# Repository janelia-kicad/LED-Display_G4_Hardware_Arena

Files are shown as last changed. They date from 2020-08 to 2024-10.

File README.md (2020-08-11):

---
title: Arena PCB
parent: Hardware
grand_parent: Generation 4
---

# Arena PCB 

An arena consists of a *Bottom PCB*, a *Top PCB*, and an *Interconnect PCB*.

The *Bottom PCB* is the basis on which the panels are mounted and where the power and input signal are connected. The *Top PCB* terminates the signal lines for each of the panel columns. The *Interconnect PCB* is an adapter from the NI connector to a ribbon connector required on the *Bottom PCB*. An arena can support up to 12 columns with up to 4 panels in each column. There are different forms of the panel, a full cylinder and a 12-18 cylinder.

## Arena 12-18

The Arena 12-18 allows to build panels around the fly in a 2/3 cylinder with a diameter of 250mm. The name originates from a the full cylinder virtually consisting of 18 columns of which 12 are actually part of the PCB. The current design interation developed in 2019 uses 7 layers.

## Interconnect PCB

The interconnect is a 2 layer PCB. It servers as an adapter between a VHDCI receptacle and a 40-pin header which is connected to the Arena via a ribbon cable. Recent tests have shown, that these ribbon cables introduce noise and should be kept as short as possible.

# Files

```
├── Production              - Gerber, drill, BOM
│   ├── 2017_Arena_12-18    - Arena board (old)
│   ├── 2019_Arena_12-18    - Arena board (current)
│   └── Interconnect        - Interconnect board
├── Schematic
│   └── Arena_bottom.pdf    - generated 2017-06-09
└── README.md
```

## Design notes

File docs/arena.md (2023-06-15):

---
title: Arena
parent: Acquisition
grand_parent: Generation 4
nav_order: 7
---

1. TOC
{:toc}

# Arena Board

The arena board organizes panels in a geometry and provides structural integrity to the whole setup. Different shapes of cylindrical arenas have been built. They are often described by their number of panel columns populated and the virtual ones forming a full circle. An _arena 12-12_ is a closed cylinder formed by 12 columns in total. All columns can be populated in this design, but typically between 1 and 3 are left empty to access the center of the arena.

Most functional designs will have two separate bill of material (BOM). One of the BOM should refer to _BOTTOM_, another to _TOP_. For a single setup, you will need two arena bards of the same type, one acting as the bottom board, one as the top board.

The BOM for the bottom arena board will usually contain more components. The bottom arena board is where the interconnect board and power are connected to and where the signals from the computer are distributed to the different columns. The top arena board gives structural integrity to the whole setup, it terminates signals, and sometimes provides additional power connectors.

## arena 12-12 board {#a12-12}

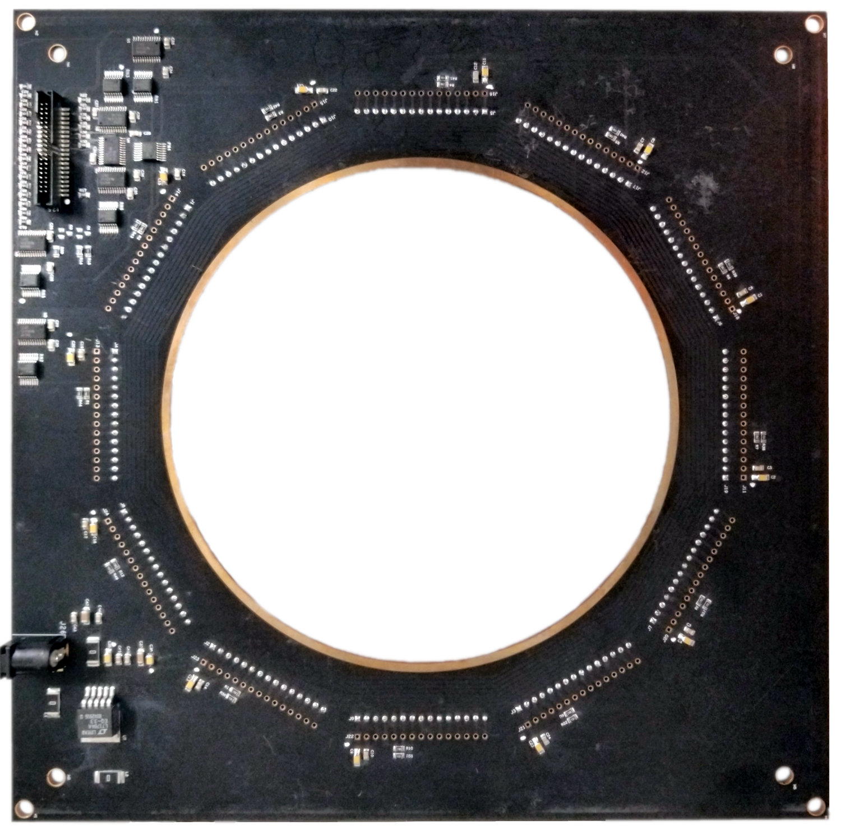
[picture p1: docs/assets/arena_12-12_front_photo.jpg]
Arena 12-12 board v1


A 12-12 Arena places twelve columns of panels in a regular dodecagon, forming an approximate cylindrical display with 170mm diameter. These are type of arenas are useful for behavioral experiments.

Currently, the most recent version 2 is the most widely used version. Nevertheless, version 4 has some improvements and is designed to minimize noise. This should work, but is not yet widely adapted. All other versions are either deprecated or prototypes.

The __Arena 12-12 Version 1__ (OrCAD design file at `arena_12-12/arena_12-12_v1.brd`, see [schematics](assets/arena_12-12_v1_schematic.pdf)) was developed in June 2017 as a 6 layer board. In addition to the connectors approximating an inner circle with 170mm diameter, it had a second row of connectors about 180mm apart. Another visible distinction are eight vias inside the connector ring, which are used for the chip selects. The image on the right shows such an arena board with the ribbon connector on the top left and the power connector on the bottom left.

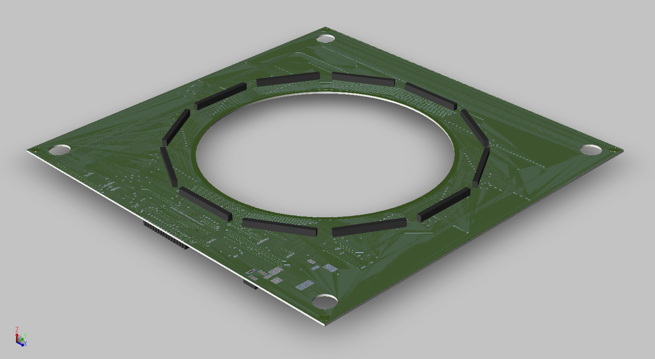
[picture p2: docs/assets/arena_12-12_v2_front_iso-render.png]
Rendering of an Arena 12-12 Version 2


The __Arena 12-12 Version 2__ (OrCAD design file at `arena_12-12/arena_12-12_v2.brd`) is similar to version 1 in [schematics](assets/arena_12-12_v1_schematic.pdf) and most of the pcb layout, but is missing the outer ring of potential connectors. Development on the 6 layer version 2 started in February 2018. If you want to repair a version 1 or version 2 board, we recommend the production files for __Arena 12-12 v2.4__ archived at `arena_12-12/production_v2/arena_12-12_v2p4.zip` as it includes incremental improvements like a more helpful silkscreen. While most of the arenas were hand-assembled and with parts that our machine shop had lying around. Version v2.4 is an attempt to fill in some of the gaps and is a step towards being able to give the assembly job to an external contractor. [Contact us]({{site.baseurl}}/Contact) about the progress if you have questions.

__Arena 12-12 Version 2C__ (OrCAD design file at `arena_12-12/arena_12-12_v2C`) is a prototype to length match all signal lines and decrease electric noise by routing them on individual layers. As a result the board has 12 (hex: `0xC`, hence 2C) layers. In our hands it didn't show improvements over other version 2 boards, but if you are looking to debug timing issues this could be a helpful starting point.

__Arena 12-12 Version 3__ (OrCAD design file at `arena_12-12/arena_12-12_v3.brd`, see [schematics](assets/arena_12-12_v3_schematic.pdf)) is a 6 layer prototype with two rings of connectors and additional changes to the physical shape of the PCB. It never left prototyping stage and is here only for historical purposes. This version was designed in June 2019.

__Arena 12-12 Version 4__ (OrCAD design file at `arena_12-12/arena_12-12_v4.brd`, see [schematics](assets/arena_12-12_v4_schematic.pdf)) is the attempt to minimize noise in the system further. To achieve that, the electronic design of this 6 layer PCB was changed in August 2019 so that the clock signal is now actively driven by a fanout instead of a simpler voltage translator as in previous versions. Furthermore, the chip select lines are isolated from each other through active components. The circular PCB was physically interrupted to avoid timing issues through circular traces.

The __Arena 12-12 Version 5__ (OrCAD design file at `arena_12-12/arena_12-12_v5.brd`, see [schematics](assets/arena_12-12_v5_schematic.pdf)) is an experimental 6 layer design without a [interconnect board](#interconnect) but instead with a direct VHDCI connector. Development is ongoing since Summer 2020, but the design does not work yet.

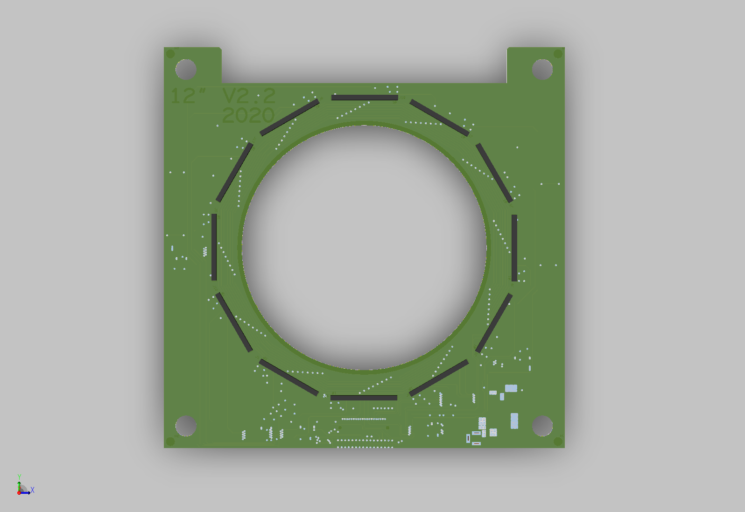
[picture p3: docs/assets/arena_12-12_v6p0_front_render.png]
Rendering of a notched Arena 12-12 Version 6


The __Arena 12-12 Version 6__ (OrCAD design file at `arena_12-12/arena_12-12_v6.brd`, see [schematics](assets/arena_12-12_v6_schematic.pdf)) from June 2019 is technically the same as Version 2 (hence the schematic is literally the same), but has a cutout in the PCB to fit under a specific microscope (see image of _notched_ arena). The latest production files are at `arena_12-12/production_v6/arena_12-12_v6p0.zip`. This version was previously know as version v2.2, but since later improvements to v2.1 lead to confusion, we rebranded it as version v6.0.

## 12-18 arena board {#a12-18}

The Arena 12-18 populates 12 out of 18 sides of a regular octadecagon with panel connectors. This means the approximated cylinder can cover up to 240° of the visual field with a diameter of around 250mm. This type of arena is particularly useful for electrophysiology and imaging experiments.

__Arena 12-18 Version 1__ and 2 are based on the same [schematic](assets/arena_12-18_bottom_schematics.pdf), differences are in routing. Also, __Arena 12-18 v2.0__ uses hidden vias, is more difficult and expensive to manufacture, and has not been used as often as boards from version 1 (and we cannot share the design files at this point). Consequently we recommend using the newest version 1 at the moment, archived at `arena_12-18/production_v1/arena_12-18_v1p1.zip`. The Arena 12-18 v1.1 is a 7 layer PCB with a footprint of 299×206mm². For a more detailed description and changelog see the `README.mdown` file in `arena_12-18/production_v1/`.

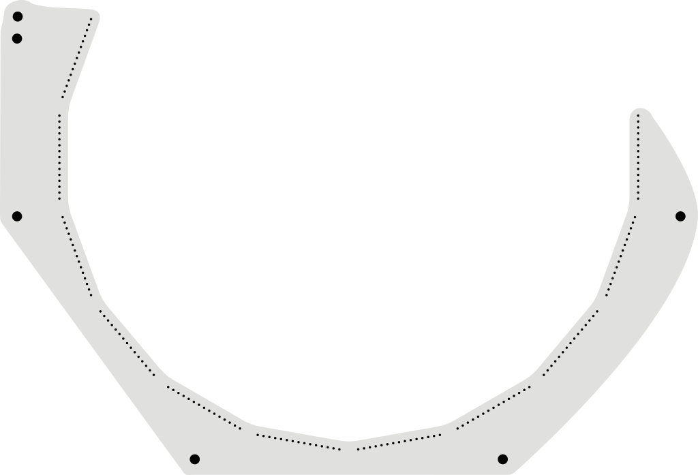
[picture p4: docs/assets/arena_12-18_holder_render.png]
Rendering of the 12-18 arena holder

For some arenas, one board required physical but not electrical connection. In this case a laser cut board, for example from acrylic, is good enough. We share a file `Arena_holder.svg` that can be used to laser cut this type of board inside the arena_12-18 folder.

## Arena Interconnect Board {#interconnect}

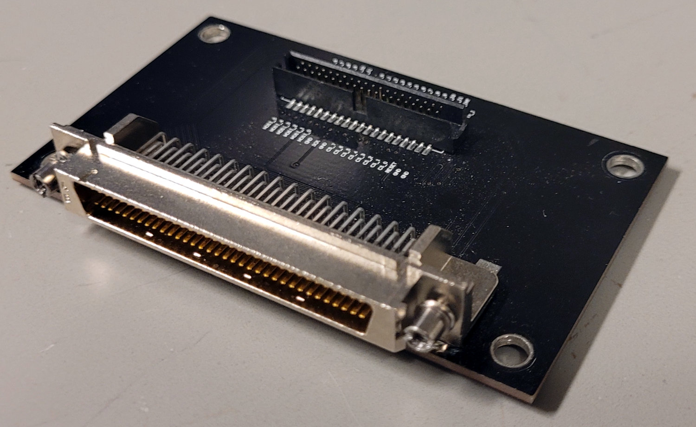
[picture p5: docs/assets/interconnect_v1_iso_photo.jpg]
Assembled interconnect board


Some of the arenas are rotated during experiments and a direct connection of the stiff VHDCI cables would put unnecessary physical stress on the arena board and connector. Therefore the majority of arena boards use a 40pin header which can be used with flexible ribbon cables. The arena interconnect board acts as an adapter between 40pin arena connector and 68pin VHDCI connector from the computer PCIe card. Unfortunately, recent tests suggest, that the ribbon cable introduces noise in the communication. The ribbon cable should be as short as possible to reduce the noise.

The __Arena Interconnect Board Version 1__ (OrCAD design file at `interconnect/interconnect_v1.brd`, see [schematics](assets/interconnect_v1_schematic.pdf)) is a simple 2 layer PCB within the dimensions of 4.9×8.4mm². The most recent production files are archived at `interconnect/production_v1/interconnect_v1p2.zip`.

We also share the OrCAD design files (`interconnect/interconnect_v2.brd`) for an __Interconnect Board Version 2__ (see [schematics](assets/interconnect_v2_schematic.pdf)). This board is designed as 4-layer PCBs with additional power connectors and 15pin connector. In theory, they could be used to drive a single column of panels directly. This design is currently untested and we recommend using version 1.

# Historic

## 12-18 arena board v0.2

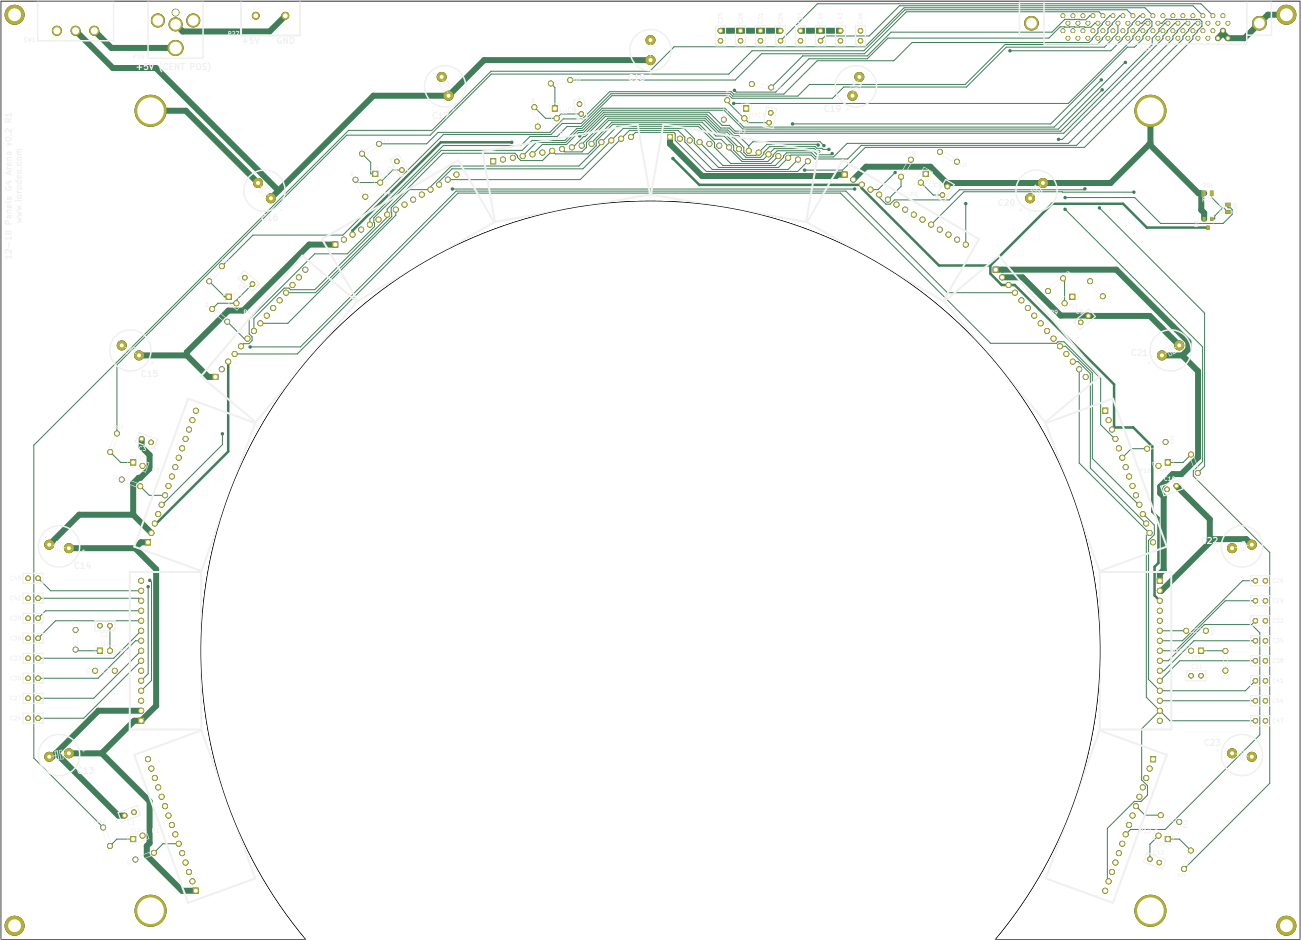
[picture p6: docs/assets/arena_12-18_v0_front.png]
12-18 arena initial design v0.2 (front)


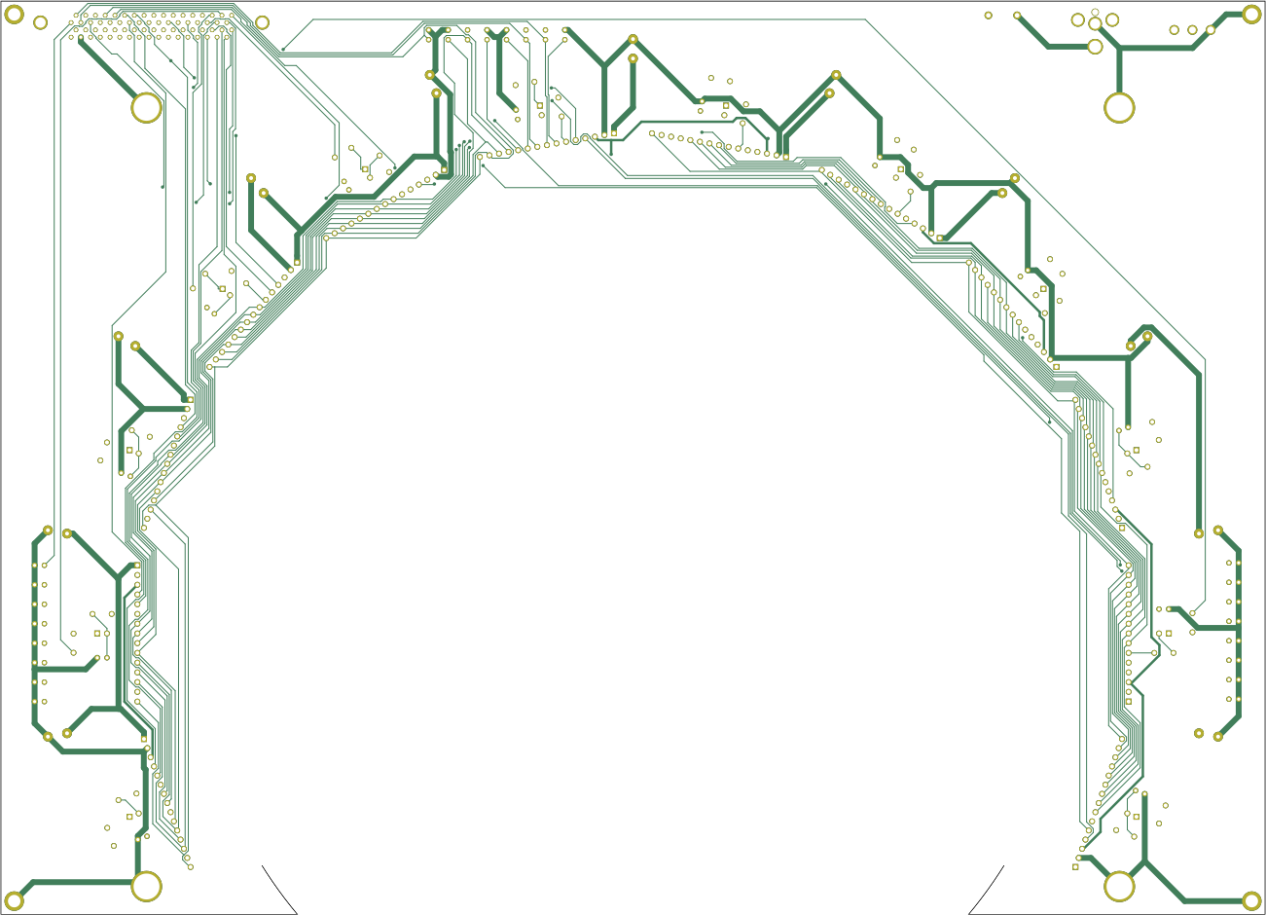
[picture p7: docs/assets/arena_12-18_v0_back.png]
12-18 arena initial design v0.2


The initial version of an 12-18 arena was designed in KiCad (see [schematic](assets/arena_12-18_v0_schematic.pdf) and [pcb](assets/arena_12-18_v0_pcb.pdf)), but the production never exceeded the version 0.2. The project is at `arena_12-18_v0`.

## 12-18 arena board v0.1

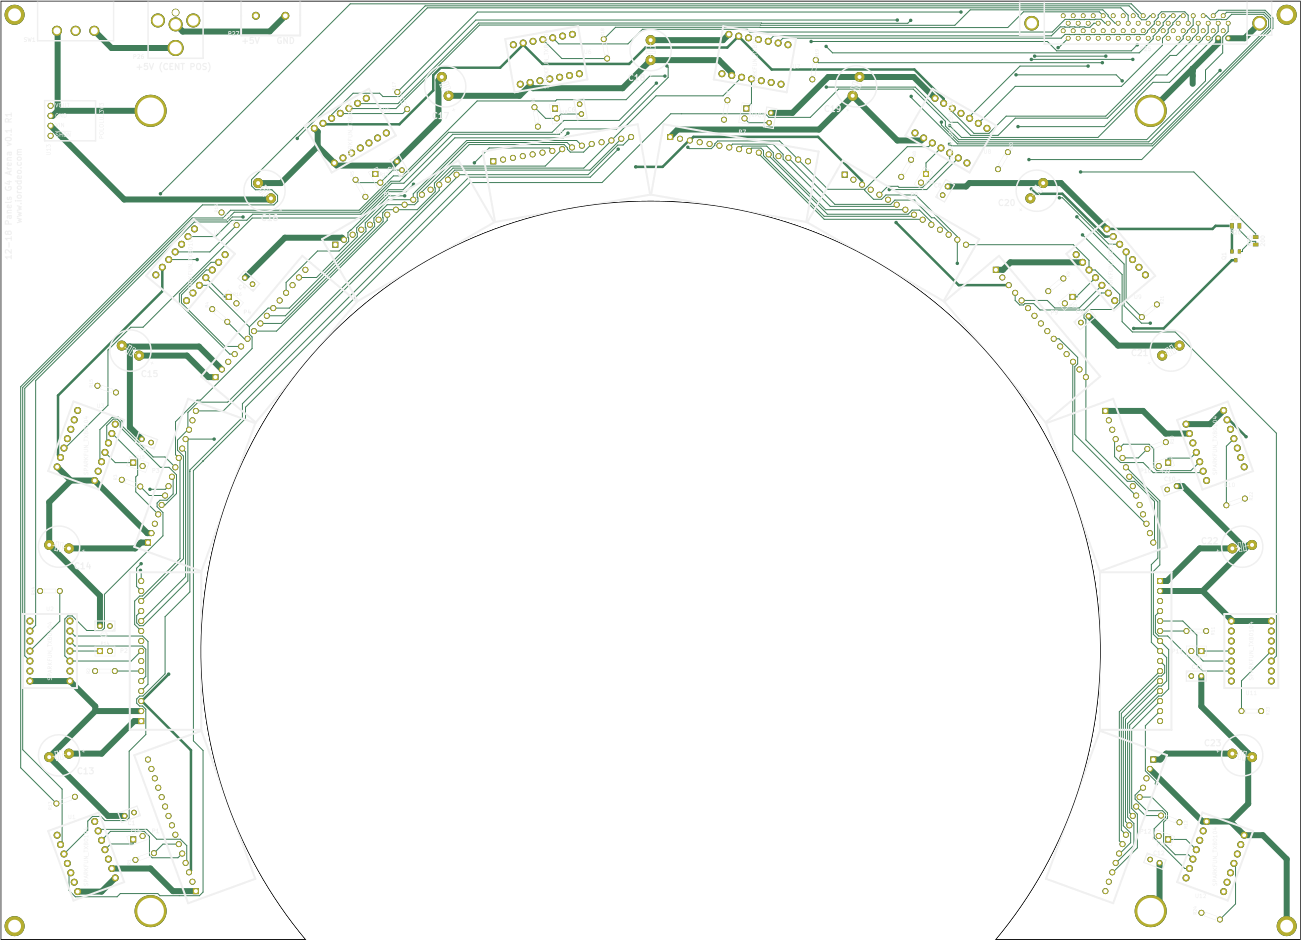
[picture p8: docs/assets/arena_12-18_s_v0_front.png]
12-18 arena initial design v0.1 (front)


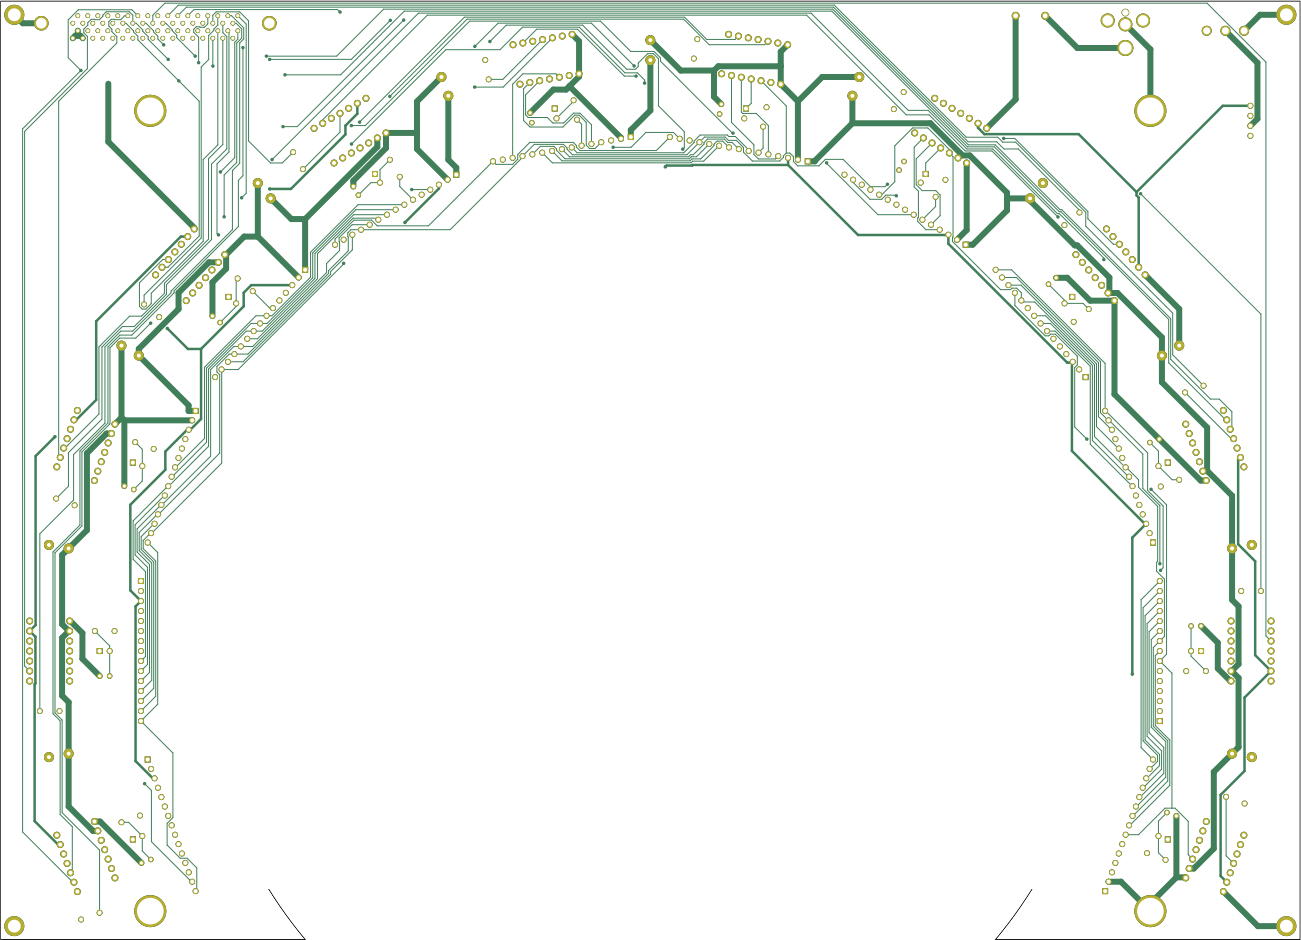
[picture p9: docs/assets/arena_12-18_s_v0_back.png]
12-18 arena initial design v0.1


Early on, there was a 12-18 arena that was called _with shifters_ was designed in KiCad (see project at `arena_12-18_s_v0` and [schematic](assets/arena_12-18_s_v0_schematic.pdf), but the production in `arena_12-18_s_v0/production_v0` never exceeded the version 0.1.

## 6 connector arena prototype (6-inf arena)

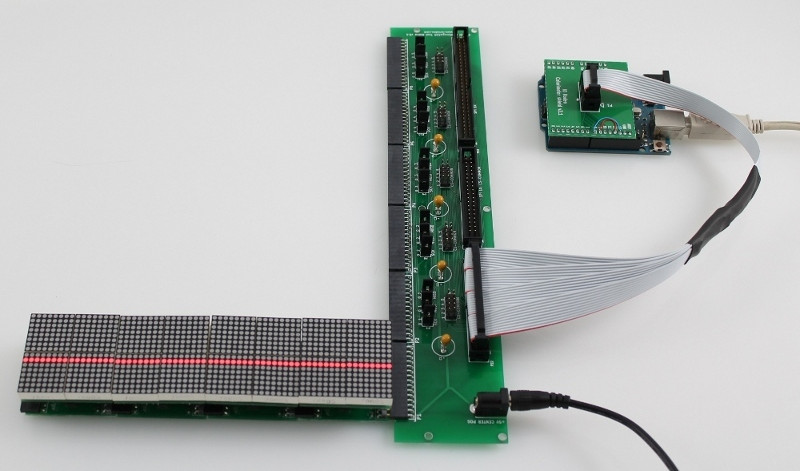
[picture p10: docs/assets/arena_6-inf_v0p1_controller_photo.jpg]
6 Connector arena (6-inf) with an Arduino prototype controller


The test arena with 6 panel connectors in a row (called a _6-inf arena_) is used to connect the panels with the controller and to supply power to the panels. There are three different headers which can be used to connect the panels to the display controller.

- P22 40-Pin (2x20) single SPI bus header.
- P23 60_Pin (2x30) six SPI bus header.
- P30 40-Pin (2x20) six SPI bus w/ common chip select lines.

5V power is supplied to the panels via 2.1mm DC jack, polarity is center positive.

There are three different versions for the ATmega328 based panels, one for the MAX6960 panels.
{:.clear}

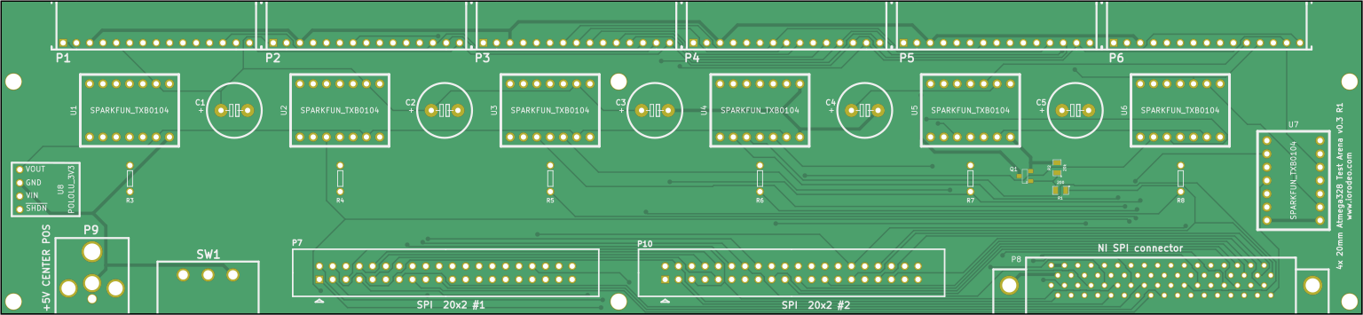
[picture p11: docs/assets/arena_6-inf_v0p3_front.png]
6-inf arena PCB for ATmega328 v0.3 (front)


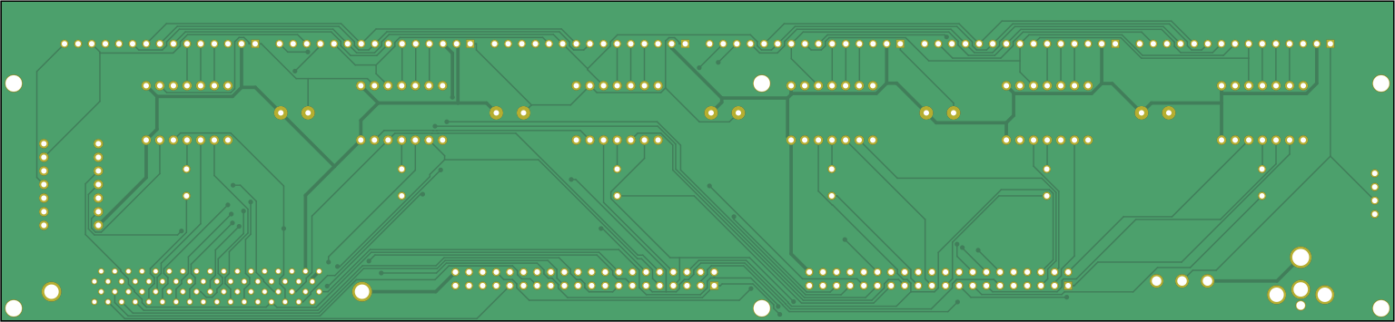
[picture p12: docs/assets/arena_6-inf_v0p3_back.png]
6-inf arena PCB for ATmega328 v0.3


Design files for version 0.3 of the 6-inf arenas for a ATmega328 (see [schematic](assets/arena_6-inf_v0p3_schematic.pdf)) are available in `arena_6-inf_v0p3`, production files in the subfolder `arena_6-inf_v0p3/production_v0`.

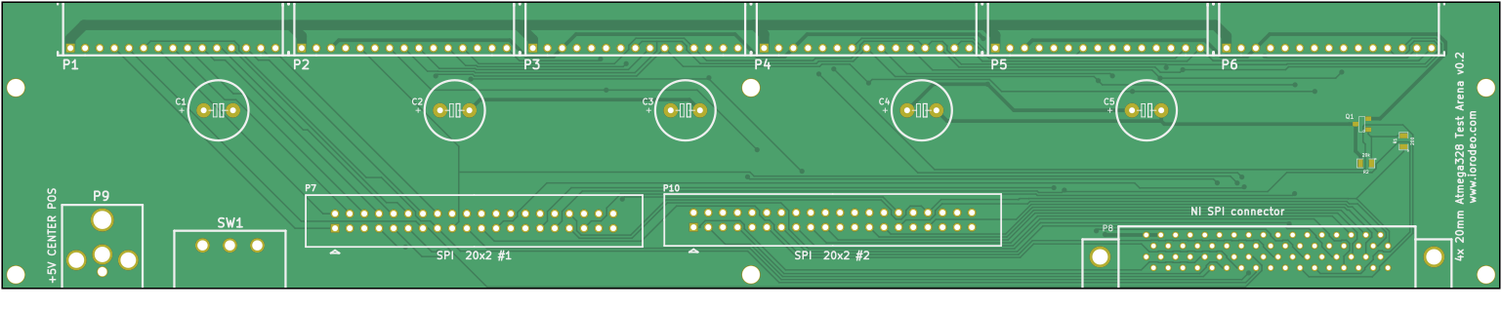
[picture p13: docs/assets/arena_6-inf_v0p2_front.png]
6-inf arena PCB for ATmega328 v0.2 (front)


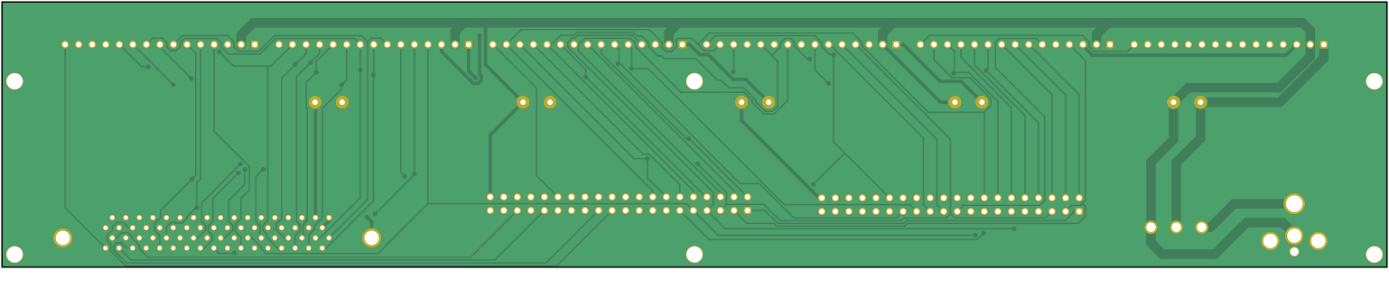
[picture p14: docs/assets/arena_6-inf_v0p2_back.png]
6-inf arena PCB for ATmega328 v0.2


Design files for version 0.2 of the 6-inf arenas for a ATmega328 (see [schematic](assets/arena_6-inf_v0p2_schematic.pdf)) are available in `arena_6-inf_v0p2`, production files in the subfolder `arena_6-inf_v0p2/production_v0`.

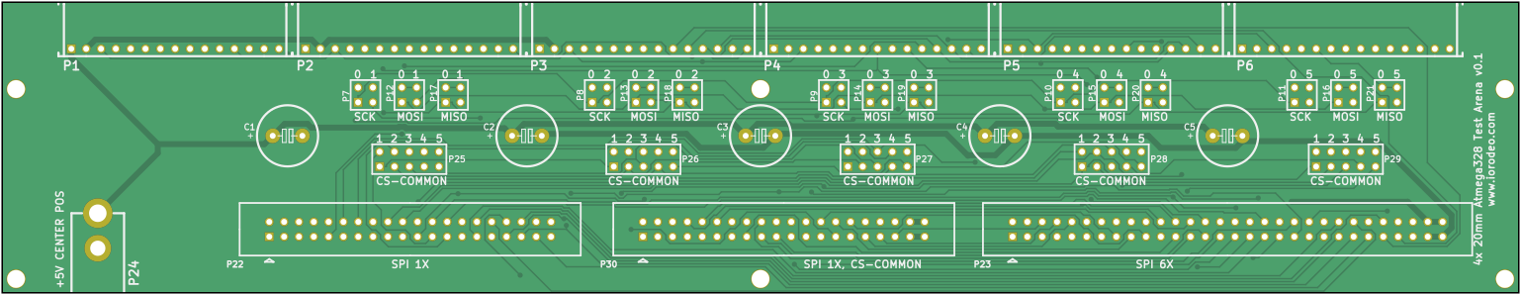
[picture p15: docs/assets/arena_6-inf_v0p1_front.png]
6-inf arena PCB for ATmega328 v0.1 (front)


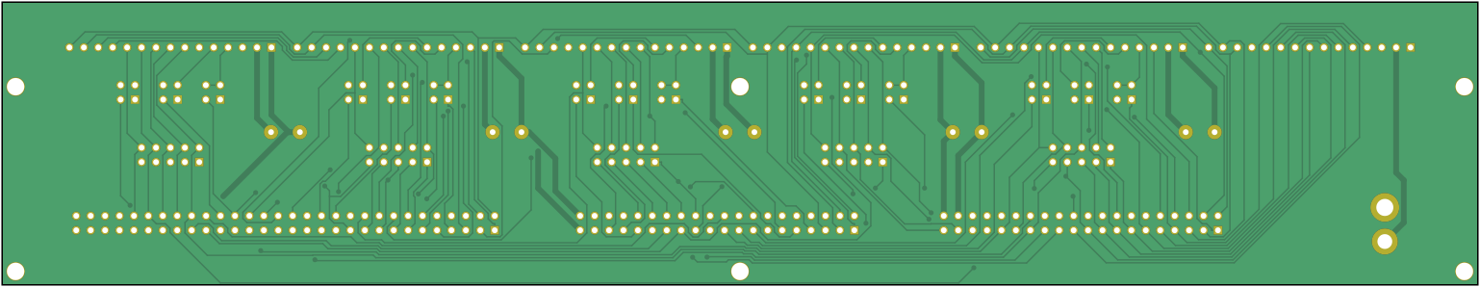
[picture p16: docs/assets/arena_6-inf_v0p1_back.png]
6-inf arena PCB for ATmega328 v0.1


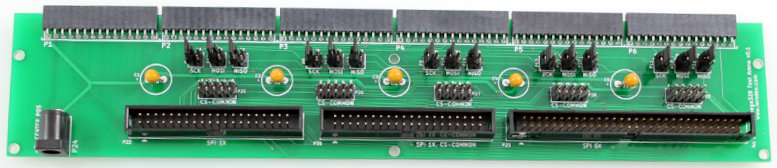
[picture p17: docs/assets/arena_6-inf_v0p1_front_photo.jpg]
6-inf arena prototype in version v0.1


Design files for version 0.1 of the 6-inf arenas for a ATmega328 (see [schematic](assets/arena_6-inf_v0p1_schematic.pdf)) are available in `arena_6-inf_v0p1`, production files in the subfolder `arena_6-inf_v0p1/production_v0`. There are 5 sets of jumpers which can be used to configure the arena.

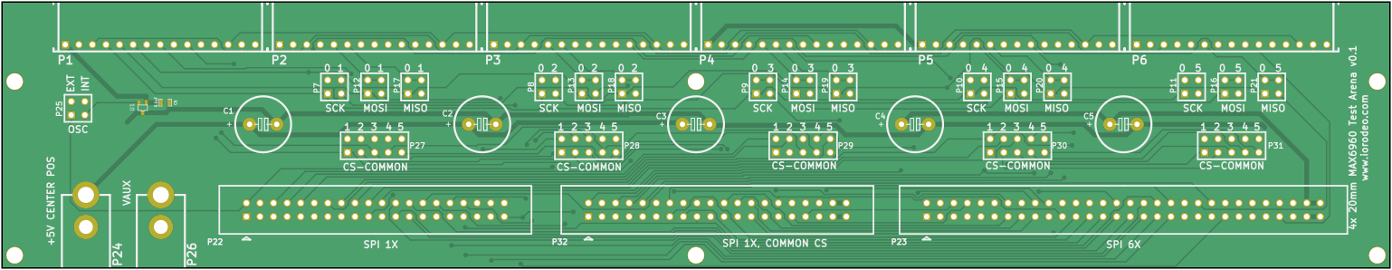
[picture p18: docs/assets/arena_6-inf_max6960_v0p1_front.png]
6-inf arena PCB for MAX6960 (front)


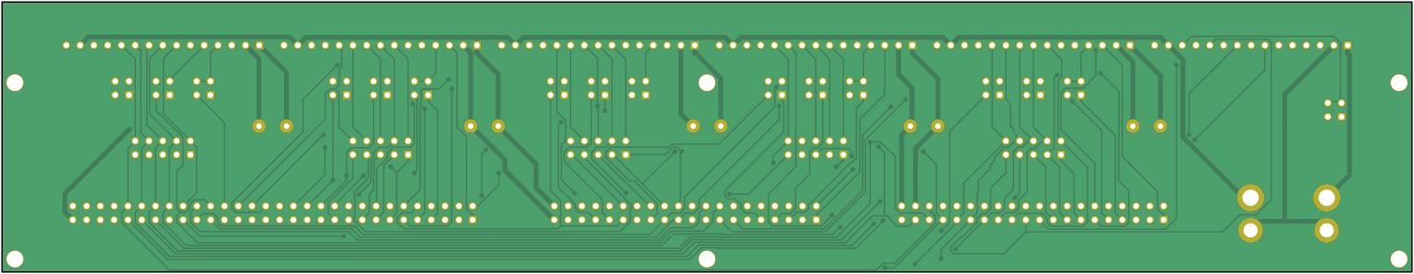
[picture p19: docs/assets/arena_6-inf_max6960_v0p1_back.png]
6-inf arena PCB for MAX6960


There is also a 6-inf arenas for a MAX6960 driver (see [schematic](assets/arena_6-inf_max6960_v0p1_schematic.pdf)) available in `arena_6-inf_max6960`. This specific one only made it to version 0.1 and production files in the subfolder `arena_6-inf_max6960/production_v0`.

## Prototype Controller

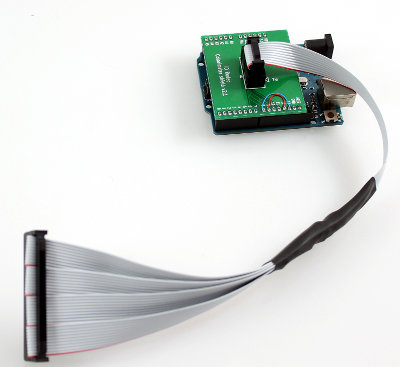
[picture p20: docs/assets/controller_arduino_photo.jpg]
Arduino based prototype controller


A demonstration controller, based on an Arduino Uno, is provided with the arena and panels. The demonstration controller connects to header P22 on the arena and will display a moving stripe pattern in 16-level gray scale mode.  The panels (up to four) should be connected to header P1 when using the demo controller. Note, the demo controller requires 5V power via the USB connector on the Arduino Uno in order to operate.

The firmware for an Arduino Uno, Arduino Due, and Teensy 3 are in the [Firmware repository]({{site.baseurl}}/Generation%204/Firmware/docs/). We cannot find the shields to connect these boards to the test arena at the moment, but they should be fairly easy to reverse engineer. But then again, we cannot think of a use case for the prototype controller or the prototype arena.

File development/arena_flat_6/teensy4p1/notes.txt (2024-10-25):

Changes from rev 1 to rev2. 
Fixed missing 5V trace between teensy's VIN (pin 48) to VUSB (pin 49).

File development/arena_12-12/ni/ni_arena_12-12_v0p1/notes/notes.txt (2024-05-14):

panel header pin distance from front

D = PCB + HDR1 + HDR2 - 0.5*HDR3

where

PCB  = thickness of PCB (1.6mm)
HDR1 = distance from PCB to top of insulation for 2x2 headers on driver (3.81mm)
HDR2 = distance from PCB to top of insulation for 2x2 headers on comm (8.5mm)
HDR3 = distance from PCB to pin in 15-pos header on comm (0.5*2.54mm)

D = 1.6 + 3.81 + 8.5 + 0.5*2.54 = 12.01mm

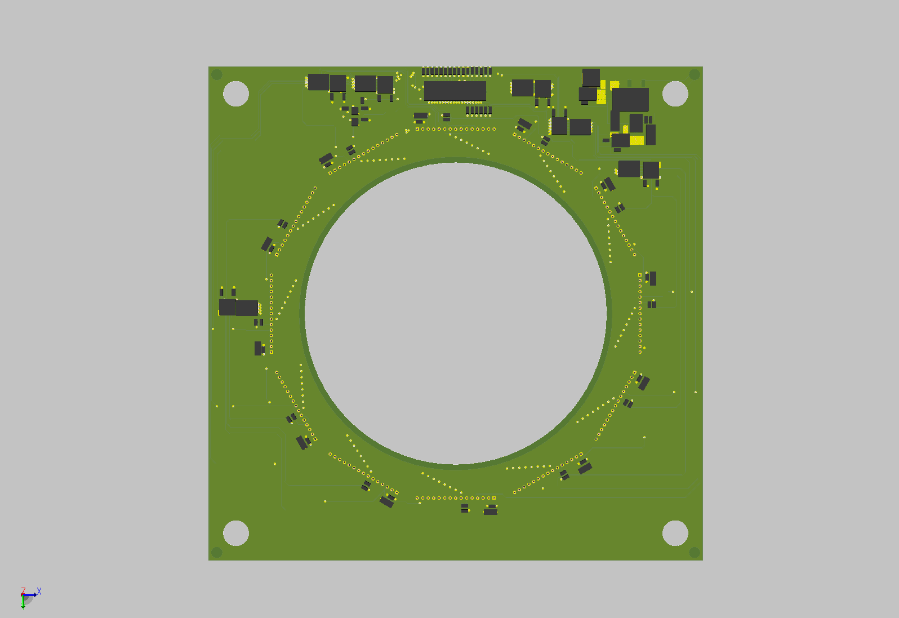
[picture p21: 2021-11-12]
docs/assets/arena_12-12_v2_back_render.png

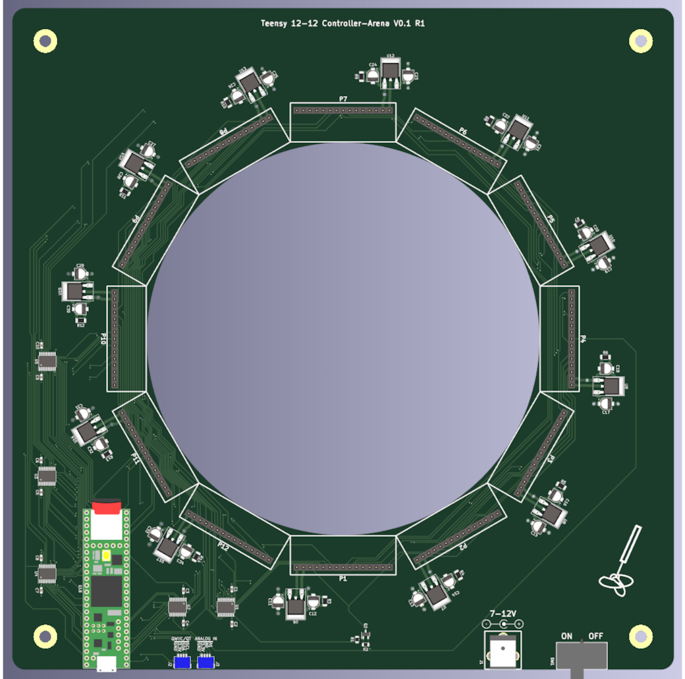
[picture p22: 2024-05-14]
development/arena_12-12_w_vreg/teensy4p1/teensy_arena_12-12_v0p2/images/kicad_3d_view.png

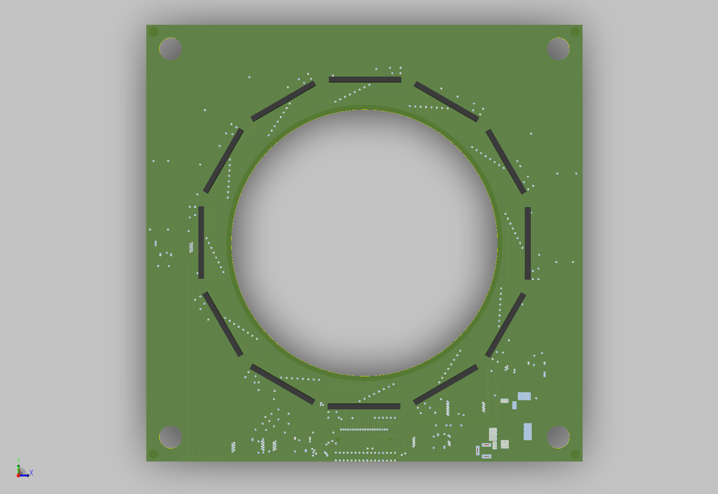
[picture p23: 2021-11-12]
docs/assets/arena_12-12_v2_front_render.png

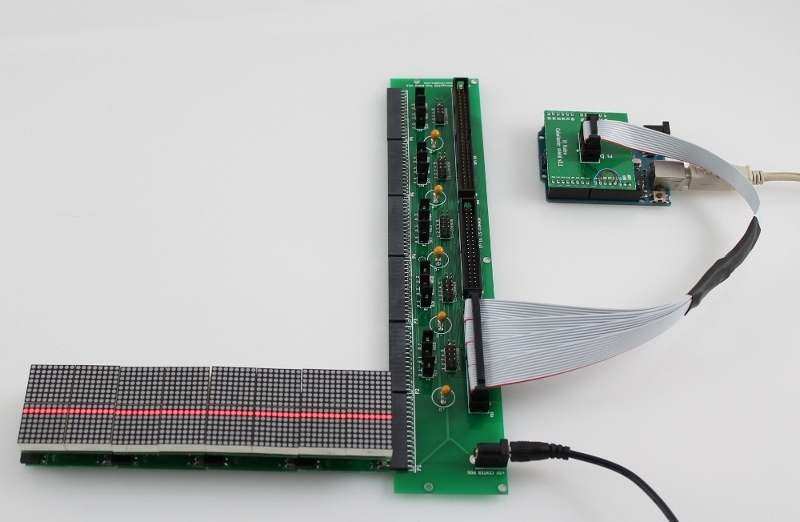
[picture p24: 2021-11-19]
docs/assets/arena_6-inf_v0p1_controller_photo.png

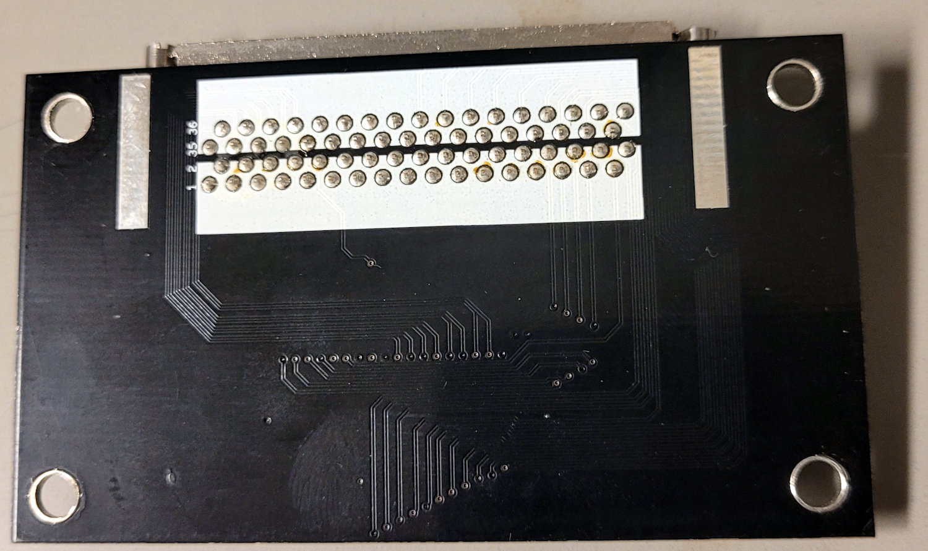
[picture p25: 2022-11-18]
docs/assets/interconnect_v1_back_photo.jpg

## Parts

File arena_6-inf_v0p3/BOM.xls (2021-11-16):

Item # | Qty | Reference | Descritpion | P/N | Vendor | unit price
1 | 5 | C1-C5 | 10uF tantulum capacitor, 25V | 478-4170-ND | Digikey | 0.98 | 24 | 23.52
2 | 6 | P1-P6 | 15x1 female header, right angle | S5490-ND or SAM1195-15-ND | Digikey | 2.26 | 12 | 27.12
3 | 2 | P7, P10 | 20x2 male header, shrouded | S9175-ND | Digikey | 0.91 | 2 | 1.82
4 | 1 | P8 | 68-pin DSUB for NI cable, TE Connectivity | A33476-ND | Digikey | 24.82 | 1 | 24.82
5 | 1 | Q1 | MOSFET N-Channel | SI2302-TPMSCT-ND | Digikey | 0.49 | 1 | 0.49
6 | 1 | R1 | Resistor, 200 SM0805 | RHM200KCT-ND | Digikey | 0.1 | 1 | 0.1
7 | 1 | R2 | Resistor, 20k SM0805 | P20.0KCCT-ND | Digikey | 0.1 | 1 | 0.1
8 | 6 | R3–R8 | Resistor 100Ohm | S100QCT-ND | Digikey | 0.1 | 12 | 1.2
9 | 1 | SW1 | Slide switch | CKC5102-ND | Digikey | 2.23 | 2 | 4.46
10 | 1 | P9 | 2.1mm DC Jack,high current | CP-063AH-ND | Digikey | 1.78 | 2 | 3.56
11 | 7 | U1-U7 | Voltage-Level Translator Breakout – TXB0104 | BOB-11771 | Sparkfun | 3.95 | 13 | 51.35
12 | 1 | U8 | 3.3V, 600mA step down voltage regulator | 2106 | Pololu | 5.95 | 1 | 5.95
 |  |  |  |  |  |  |  | 0
Extra |  |  |  |  |  |  |  | 0
1 | 2 | P22,P30 | connector socket IDC 40 position | S9326-ND | Digikey | 1.54 | 2 | 3.08
 |  |  |  |  |  | 1.6 | 6 | 9.6
 |  |  |  |  |  |  |  | 157.17 | 785.85

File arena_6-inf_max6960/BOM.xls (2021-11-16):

Item # | Qty | Reference | Descritpion | P/N | Vendor
1 | 5 | C1-C5 | 10uF tantulum capacitor, 25V | 478-4170-ND | Digikey
2 | 1 | C6 | 0.1uF ceramic capacitor, SM0603 | 445-1316-1-ND | Digikey
3 | 6 | P1-P6 | 15x1 female header, right angle | S5490-ND, SAM1195-15-ND | Digikey
4 | 15 | P7-P21, P25 | 2x2 male header, break away | S2011EC-40-ND | Digikey
5 | 2 | P22, P32 | 20x2 male header, shrouded | S9175-ND | Digikey
6 | 1 | P23 | 30x2 male header, shrouded | OR968-ND | Digikey
7 | 2 | P24, P26 | 2.1mm DC Jack 2-pin | 137673 | Jameco
8 | 5 | P27-P31 | 5x2 male header | S2011EC-40-ND | Digikey
9 | 1 | U1 | MAX7375, | MAX7375AXR425+TCT-ND | Digikey
Extra
1 | 1 | P22,P30 | connector socket IDC 40 position | S9326-ND | Digikey
2 | 1 | P23 | connector socket IDC 60 position | OR978-ND | Digikey

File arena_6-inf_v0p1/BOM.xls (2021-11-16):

Item # | Qty | Reference | Descritpion | P/N | Vendor
1 | 5 | C1-C5 | 10uF tantulum capacitor, 25V | 478-4170-ND | Digikey
2 | 6 | P1-P6 | 15x1 female header, right angle | S5490-ND or SAM1195-15-ND | Digikey
3 | 15 | P7-P21 | 2x2 male header, break away | S2011EC-40-ND | Digikey
4 | 2 | P22, P30 | 20x2 male header, shrouded | S9175-ND | Digikey
5 | 1 | P23 | 30x2 male header, shrouded | OR968-ND | Digikey
6 | 1 | P24 | 2.1mm DC Jack 2-pin | 137673 | Jameco
7 | 5 | P25-P29 | 5x2 male header | S2011EC-40-ND | Digikey
Extra
1 | 1 | P22,P30 | connector socket IDC 40 position | S9326-ND | Digikey
2 | 1 | P23 | connector socket IDC 60 position | OR978-ND | Digikey

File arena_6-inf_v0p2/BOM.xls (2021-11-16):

Item # | Qty | Reference | Descritpion | P/N | Vendor
1 | 5 | C1-C5 | 10uF tantulum capacitor, 25V | 478-4170-ND | Digikey
2 | 6 | P1-P6 | 15x1 female header, right angle | S5490-ND or SAM1195-15-ND | Digikey
3 | 2 | P7, P10 | 20x2 male header, shrouded | S9175-ND | Digikey
4 | 1 | P8 | 68-pin DSUB for NI cable, TE Connectivity | A33476-ND | Digikey
5 | 1 | Q1 | MOSFET N-Channel | SI2302-TPMSCT-ND | Digikey
6 | 1 | R1 | Resistor, 200 SM0805 | RHM200KCT-ND | Digikey
7 | 1 | R2 | Resistor, 20k SM0805 | P20.0KCCT-ND | Digikey
8 | 1 | SW1 | Slide switch | CKC5102-ND | Digikey
9 | 1 | P9 | 2.1mm DC Jack 2-pin | 137673 | Jameco
Extra
1 | 1 | P22,P30 | connector socket IDC 40 position | S9326-ND | Digikey
2 | 1 | P23 | connector socket IDC 60 position | OR978-ND | Digikey

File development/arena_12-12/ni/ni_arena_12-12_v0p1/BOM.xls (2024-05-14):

Item # | Qty | Reference | Descritpion | P/N | Vendor
1 | 5 | C1-C6 | 10uF tantalum capacitor, 25V | 478-4170-ND | Digikey
2 | 1 | J1 | 2.1mm DC Jack,high current | CP-063AH-ND | Digikey
3 | 2 | J2, J3 | Grove 2mm 4pin R/A conn | 1597-1083-ND | Digikey
4 | 6 | P1-P6 | 15x1 female header, right angle | SAM1195-15-ND | Digikey
5 | 1 | Q2 | MOSFET N-Channel | SI2302-TPMSCT-ND | Digikey
6 | 1 | R1 | Resistor, 200 Ohms, SM0805 | RHM200KCT-ND | Digikey
7 | 1 | R2 | Resistor, 20k SM0805 | P20.0KCCT-ND | Digikey
8 | 1 | SW1 | Slide switch | CKC5102-ND | Digikey
9 | 6 | U1-U6 | Voltage-Level Translator Breakout – TXB0104 | 1568-1208-ND | Digikey
10 | 1 | U7 | Teensy 4.1 | 1568-DEV-16771-ND | Digikey

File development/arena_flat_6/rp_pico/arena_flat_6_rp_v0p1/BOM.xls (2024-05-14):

Item # | Qty | Reference | Descritpion | P/N | Vendor
1 | 5 | C1-C6 | 10uF tantalum capacitor, 25V | 478-4170-ND | Digikey
2 | 1 | J1 | 2.1mm DC Jack,high current | CP-063AH-ND | Digikey
3 | 6 | P1-P6 | 15x1 female header, right angle | SAM1195-15-ND | Digikey
4 | 1 | Q2 | MOSFET N-Channel | SI2302-TPMSCT-ND | Digikey
5 | 1 | R1 | Resistor, 200 Ohms, SM0805 | RHM200KCT-ND | Digikey
6 | 1 | R2 | Resistor, 20k SM0805 | P20.0KCCT-ND | Digikey
7 | 1 | SW1 | Slide switch | CKC5102-ND | Digikey
8 | 6 | U1-U6 | Voltage-Level Translator Breakout – TXB0104 | 1568-1208-ND | Digikey
9 | 1 | U10 | Raspberry Pi Pico RP2040 | 2648-SC0915CT-ND | Digikey

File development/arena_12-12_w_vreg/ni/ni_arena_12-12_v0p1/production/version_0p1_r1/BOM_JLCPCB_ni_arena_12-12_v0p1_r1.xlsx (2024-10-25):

Comment | Designator | Footprint | LCSC Part #（optional） | Qty
0.1uF ceramic Capacitor | C1, C2, C3, C4, C5, C6, C7, C8, C9, C10 | 0603 | C1591 | 10
10uF Ceramic Capacitor, 25V | C11, C14, C17, C20, C23, C26, C29, C32, C35, C38, C41, C44, C47, C48 | 0603 | C96446 | 14
100nF Ceramic Capacitor | C12, C15, C18, C21, C24, C27, C30, C33, C36, C39, C42, C45 | 0603 | C1591 | 12
22uF Ceramic Capacitor | C13, C16, C19, C22, C25, C28, C31, C34, C37, C40, C43, C46 | 0603 | C2762594 | 12
3.3uH Inductor | L1, L2, L3, L4, L5, L6, L7, L8, L9, L10, L11, L12 | SMD,7.2x6.6mm | C5189747 | 12
200 Ohm resistor | R1 | 0805 | C17540 | 1
20k Ohms resistor | R2 | 0805 | C4328 | 1
56.2k Resistor, 0.1% | R3, R5, R7, R9, R11, R13, R15, R17, R19, R21, R23, R25 | 0603 | C705784 | 12
10k Resistor, 0.1% | R4, R6, R8, R10, R12, R14, R16, R18, R20, R22, R24, R26 | 0603 | C95204 | 12
MOSFET N-channel | Q2 | SOT-23 | C165220 | 1
Level shifter TXB0108PWR | U1,U2,U3,U4,U5 | TSSOP-20 | C53406 | 5
TPS564201DDC Step-Down Regulator | U6, U7, U8, U9, U10, U11, U12, U13, U14, U15, U16, U17 | TSOT-23-6 | C464812 | 12
AP2112K-3.3 3.3V Linear Regulator | U18 | SOT-25-5 | C51118 | 1
DC Power Barrel Jack | J1 | through hole | global parts | 1
TE/NI 68 Position Connector | J2 | through hole | global parts | 1
15x1 female header, 0.1in pitch | P1,P2,P3,P4,P5,P6,P7,P8,P9,P10,P11,P12 | through hole | global parts | 12
Slide Switch SPDT | SW1 | through hole | global parts | 1

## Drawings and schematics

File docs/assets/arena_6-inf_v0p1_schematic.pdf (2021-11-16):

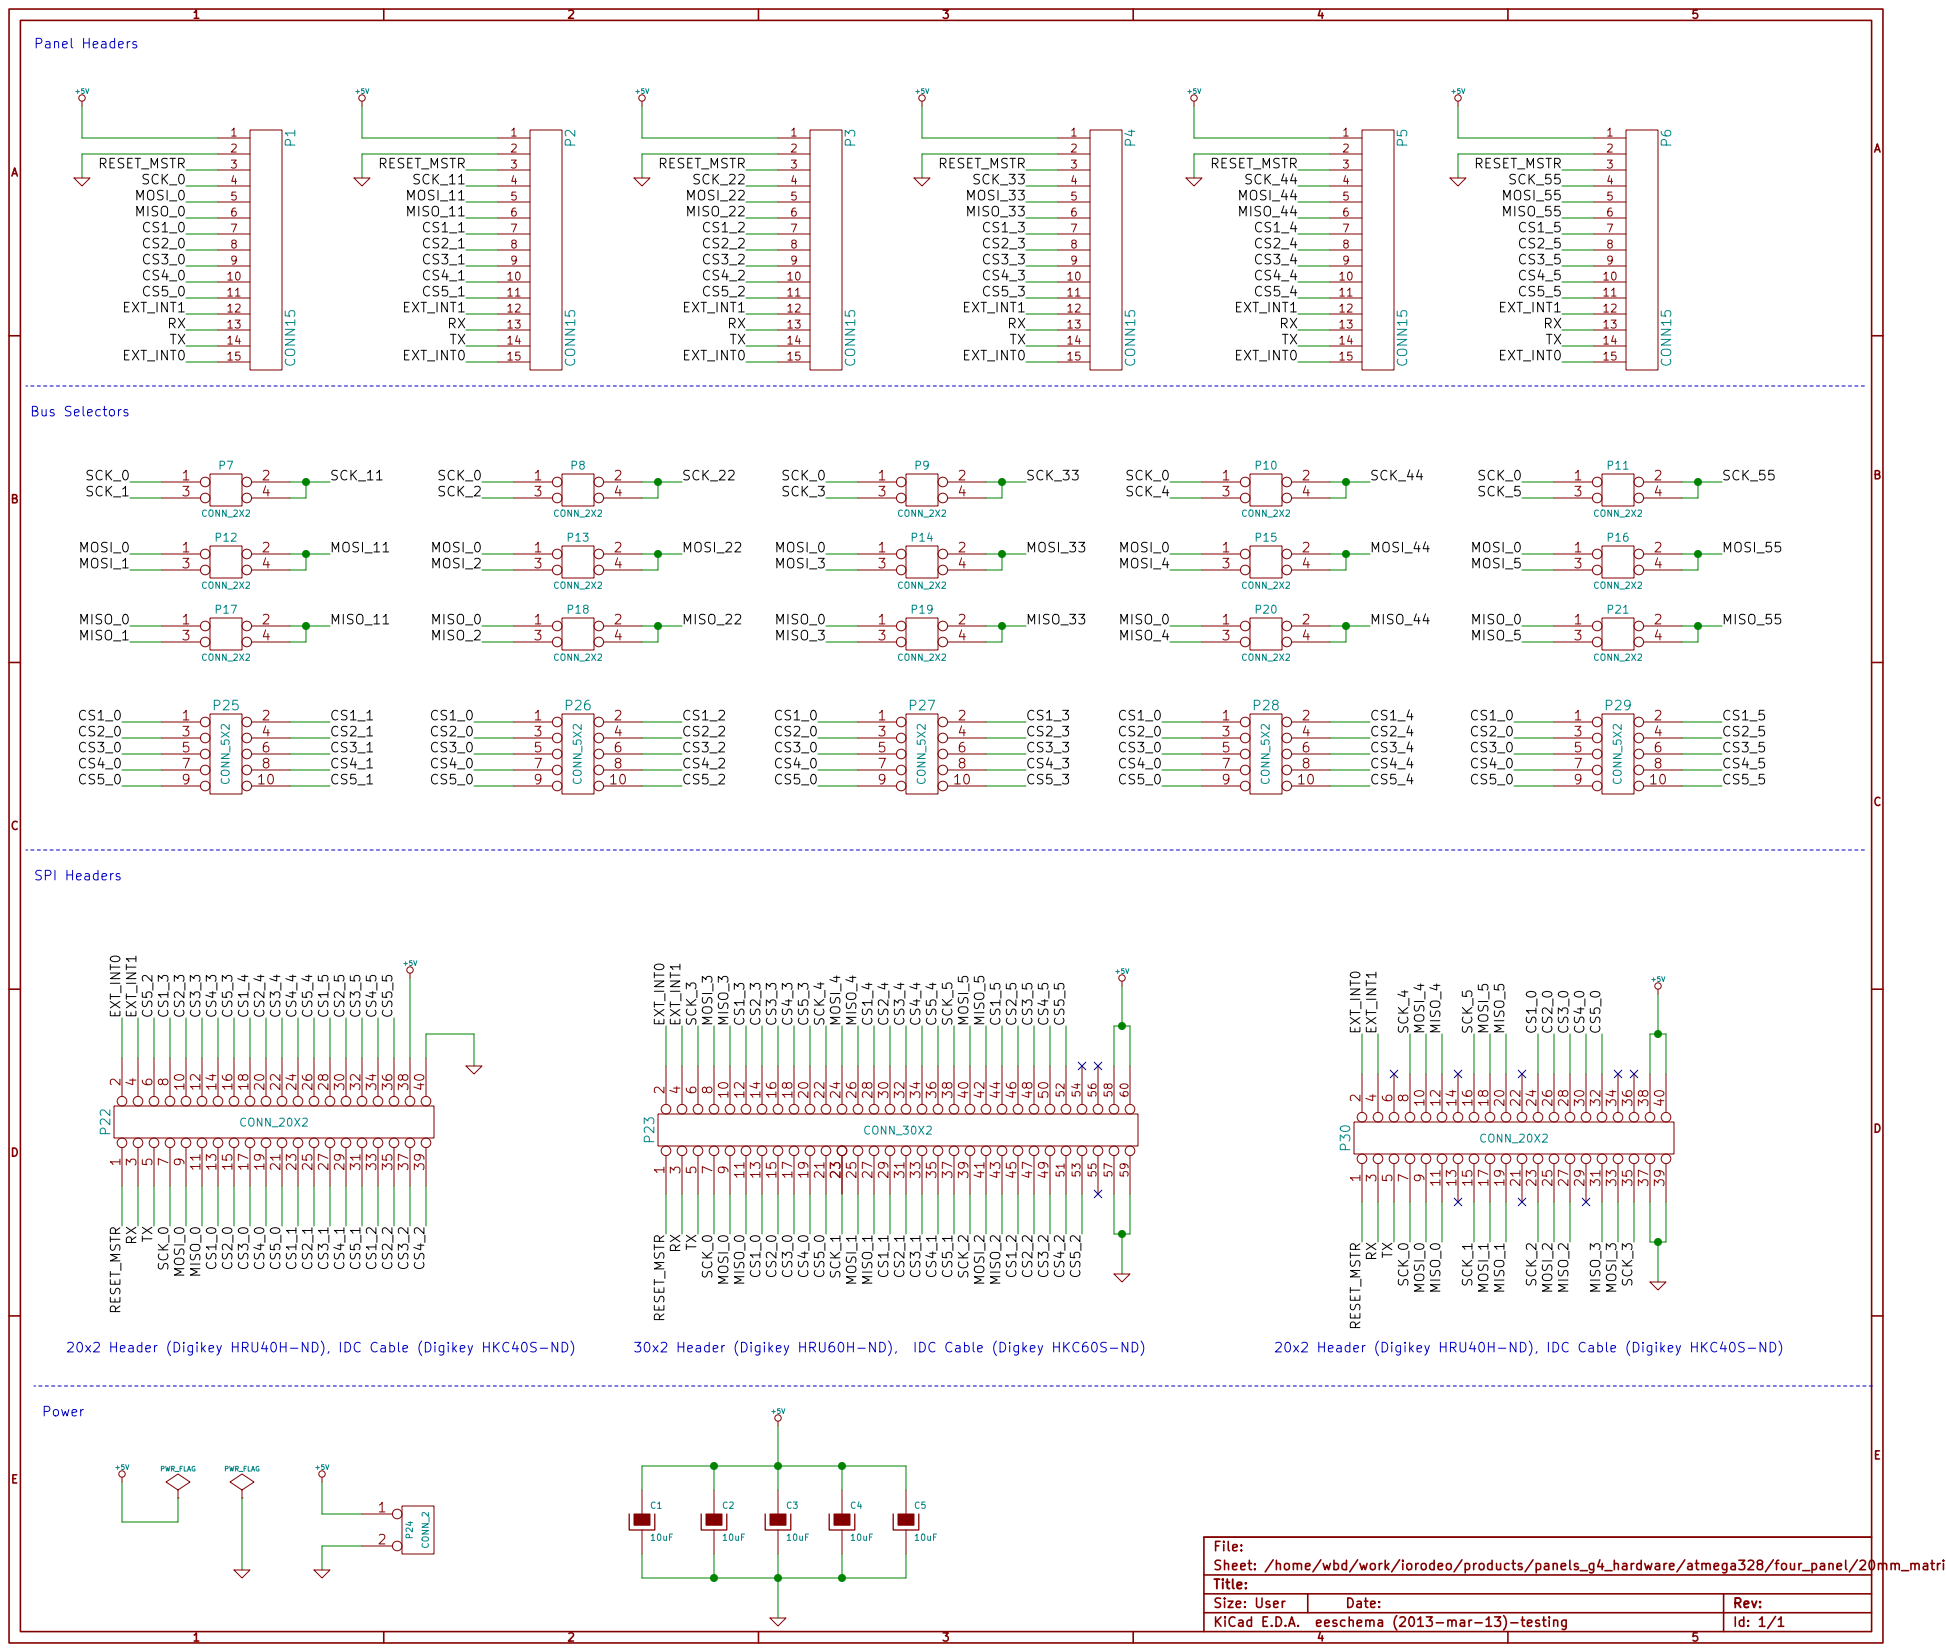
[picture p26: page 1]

9 10203040 112131 122232 132333 142434 152535 162636 172737 182838 192939 P22CONN_20X2 20x2 Header (Digikey HRU40H-ND), IDC Cable (Digikey HKC40S-ND) RESET_MSTRRXTX EXT_INT0 EXT_INT1 SCK_0 MOSI_0 MISO_0 CS1_0 CS2_0 CS3_0 CS4_0 CS5_0 CS1_1 CS2_1 CS3_1 CS4_1 CS5_1 CS1_2 CS2_2 CS3_2 CS4_2 CS5_2 CS1_3 CS2_3 CS3_3 CS4_3 CS5_3 CS1_4 CS2_4 CS3_4 CS4_4 CS5_4 CS1_5 CS2_5 CS3_5 CS4_5 CS5_5

30x2 Header (Digikey HRU60H-ND), IDC Cable (Digkey HKC60S-ND) 1 2

20x2 Header (Digikey HRU40H-ND), IDC Cable (Digikey HKC40S-ND)

E Sheet: /home/wbd/work/iorodeo/products/panels_g4_hardware/atmega328/four_panel/20mm_matrix/test_arena/arena.sch File: Title:

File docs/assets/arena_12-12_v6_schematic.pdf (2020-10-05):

5VDC | 5VDC | 5VDC | 5VDC | 5VDC | 5VDC | 5VDC | 5VDC | 5VDC | 5VDC | 5VDC | 5VDC

J7

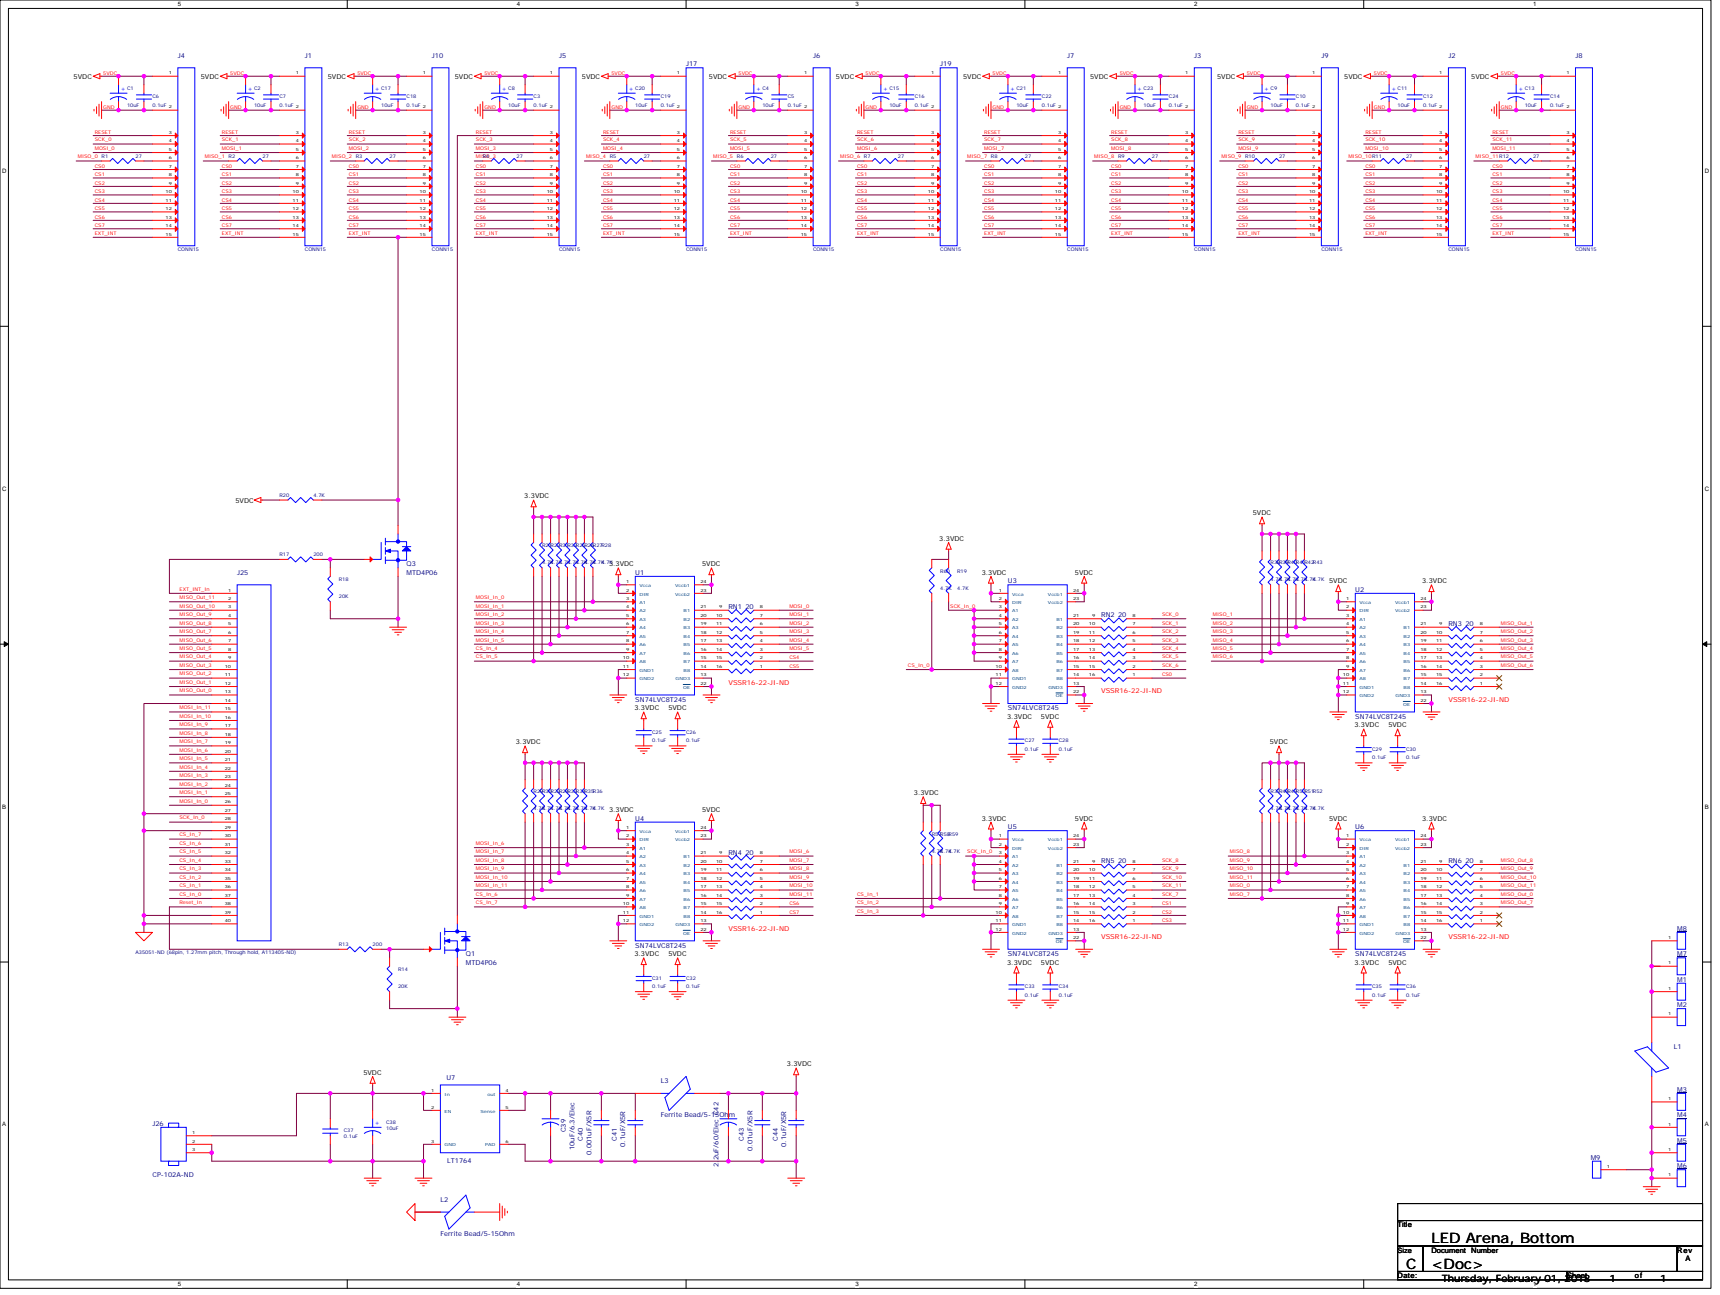
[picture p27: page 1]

A35051-ND (68pin, 1.27mm pitch, Through hold, A113405-ND)

Size Size Size C C C | Document Number Document Number Document Number <Doc> <Doc> <Doc> | Rev Rev Rev A A A

Date: Date: Date: Thursday, February 01, 2018 Thursday, February 01, 2018 Thursday, February 01, 2018 | Sheet Sheet Sheet 1 1 1 of of of 1 1 1

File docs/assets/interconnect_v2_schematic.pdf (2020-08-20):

### 5VDC

### 5VDC

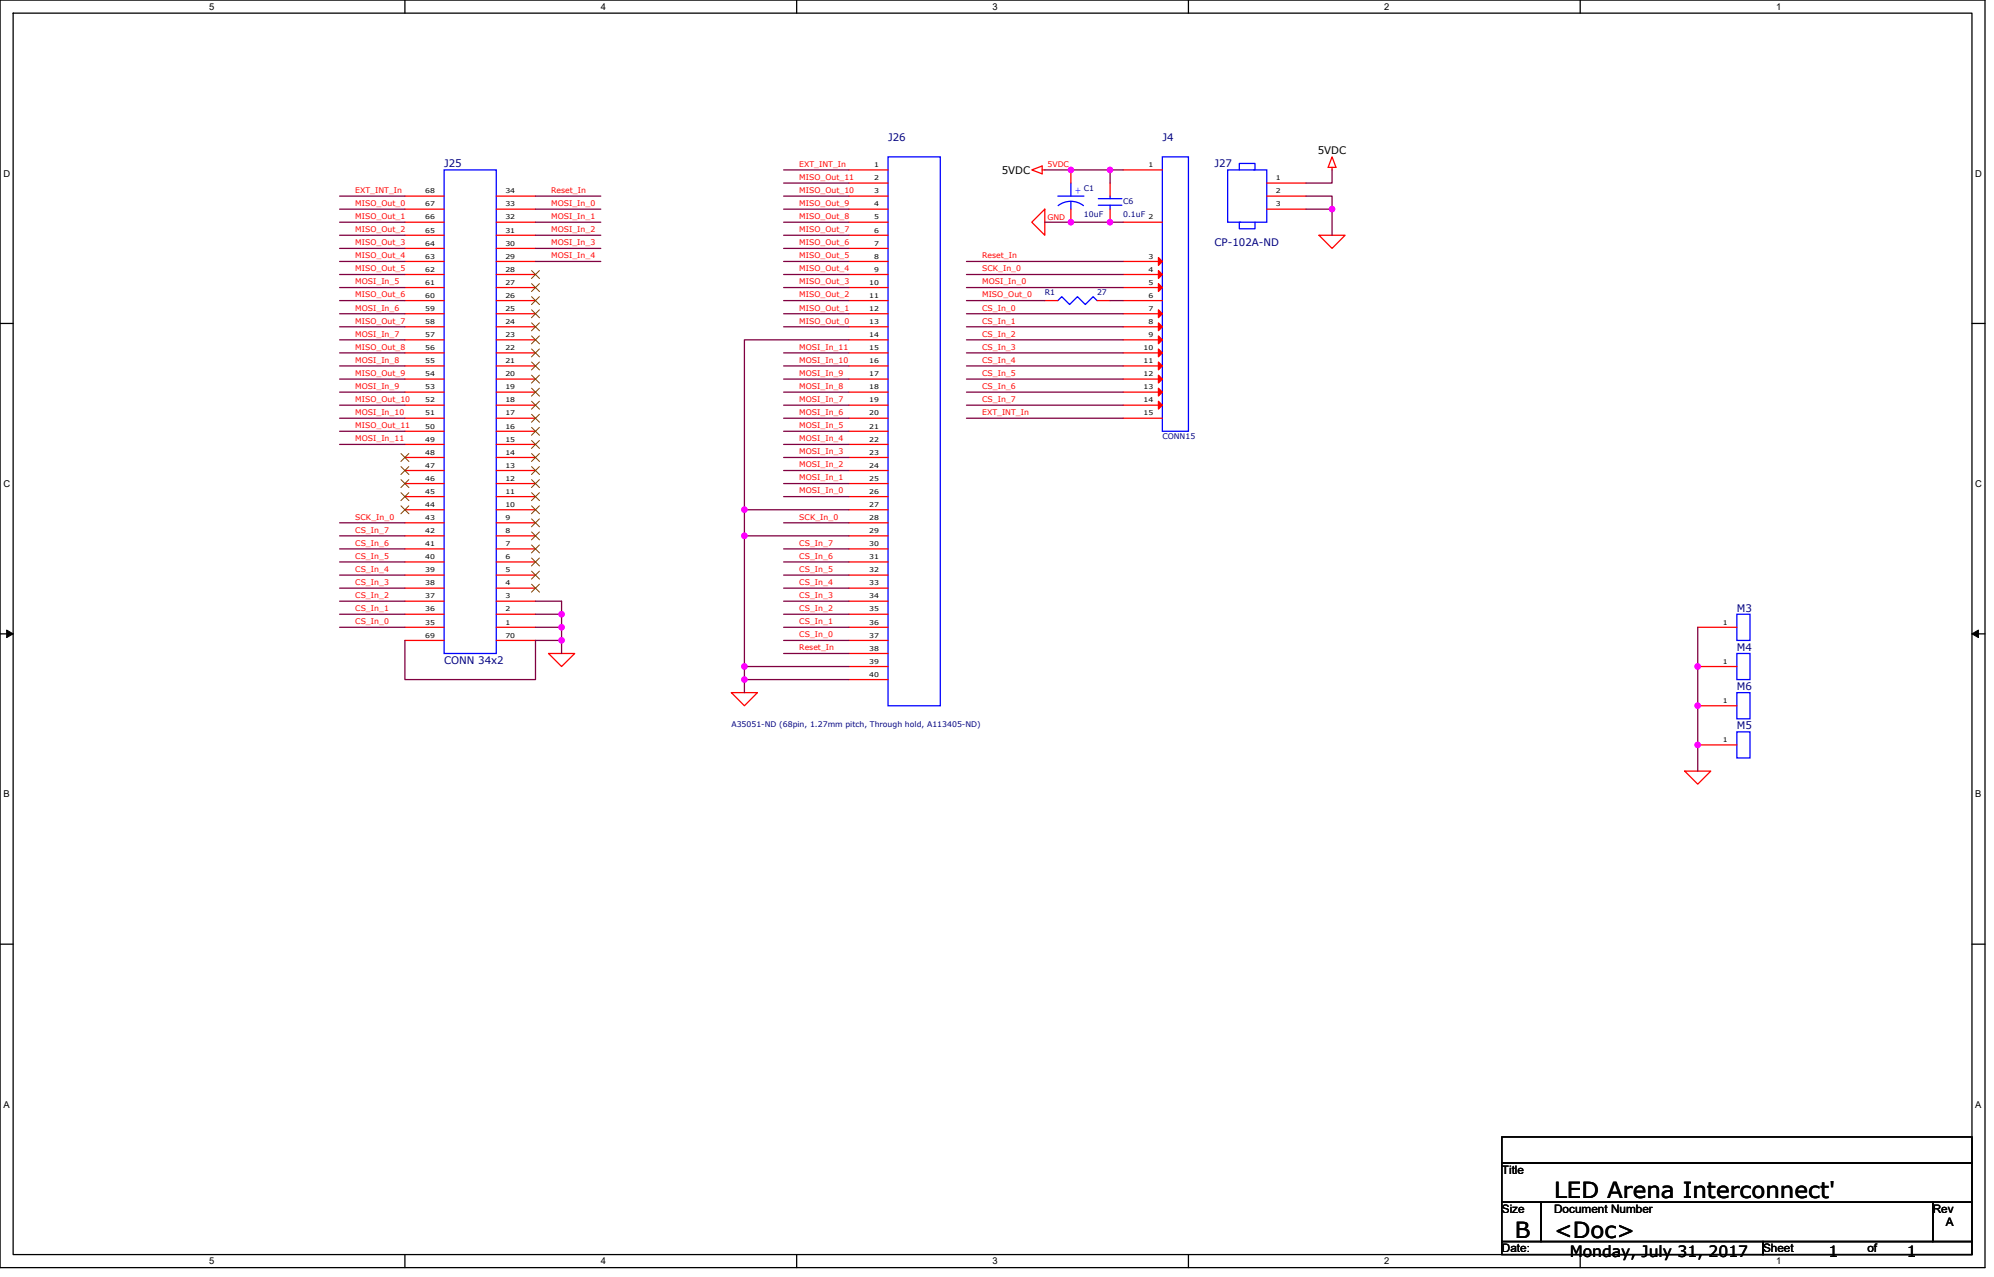
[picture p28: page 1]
Monday, July 31, 2017; CONN15; CONN 34x2; MISO_Out_0; EXT_INT_In; MISO_Out_2; MISO_Out_1; MISO_Out_4; MISO_Out_3; MOSI_In_5; MISO_Out_5; MOSI_In_6; MISO_Out_6; MOSI_In_7; MISO_Out_7; MOSI_In_8; MISO_Out_8; MOSI_In_9; MISO_Out_9; MOSI_In_10; MISO_Out_10; MOSI_In_11; MISO_Out_11; SCK_In_0; Reset_In; MOSI_In_4; MOSI_In_1; MOSI_In_0; MOSI_In_3; MOSI_In_2; MOSI_In_6 MOSI_In_5 MOSI_In_4 MOSI_In_3 MOSI_In_2 MOSI_In_1; MISO_Out_6 MISO_Out_5 MISO_Out_4 MISO_Out_3 MISO_Out_2 MISO_Out_1; 5VDC; GND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

A35051-ND (68pin, 1.27mm pitch, Through hold, A113405-ND)

Title
LED Arena Interconnect'

Size Size Size B B B | Document Number Document Number Document Number <Doc> <Doc> <Doc> | Rev Rev Rev A A A

Date: Date: Date: | Sheet Sheet Sheet of of of

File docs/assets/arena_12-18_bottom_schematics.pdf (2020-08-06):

5VDC | 5VDC | 5VDC
5VDC | 5VDC | 5VDC

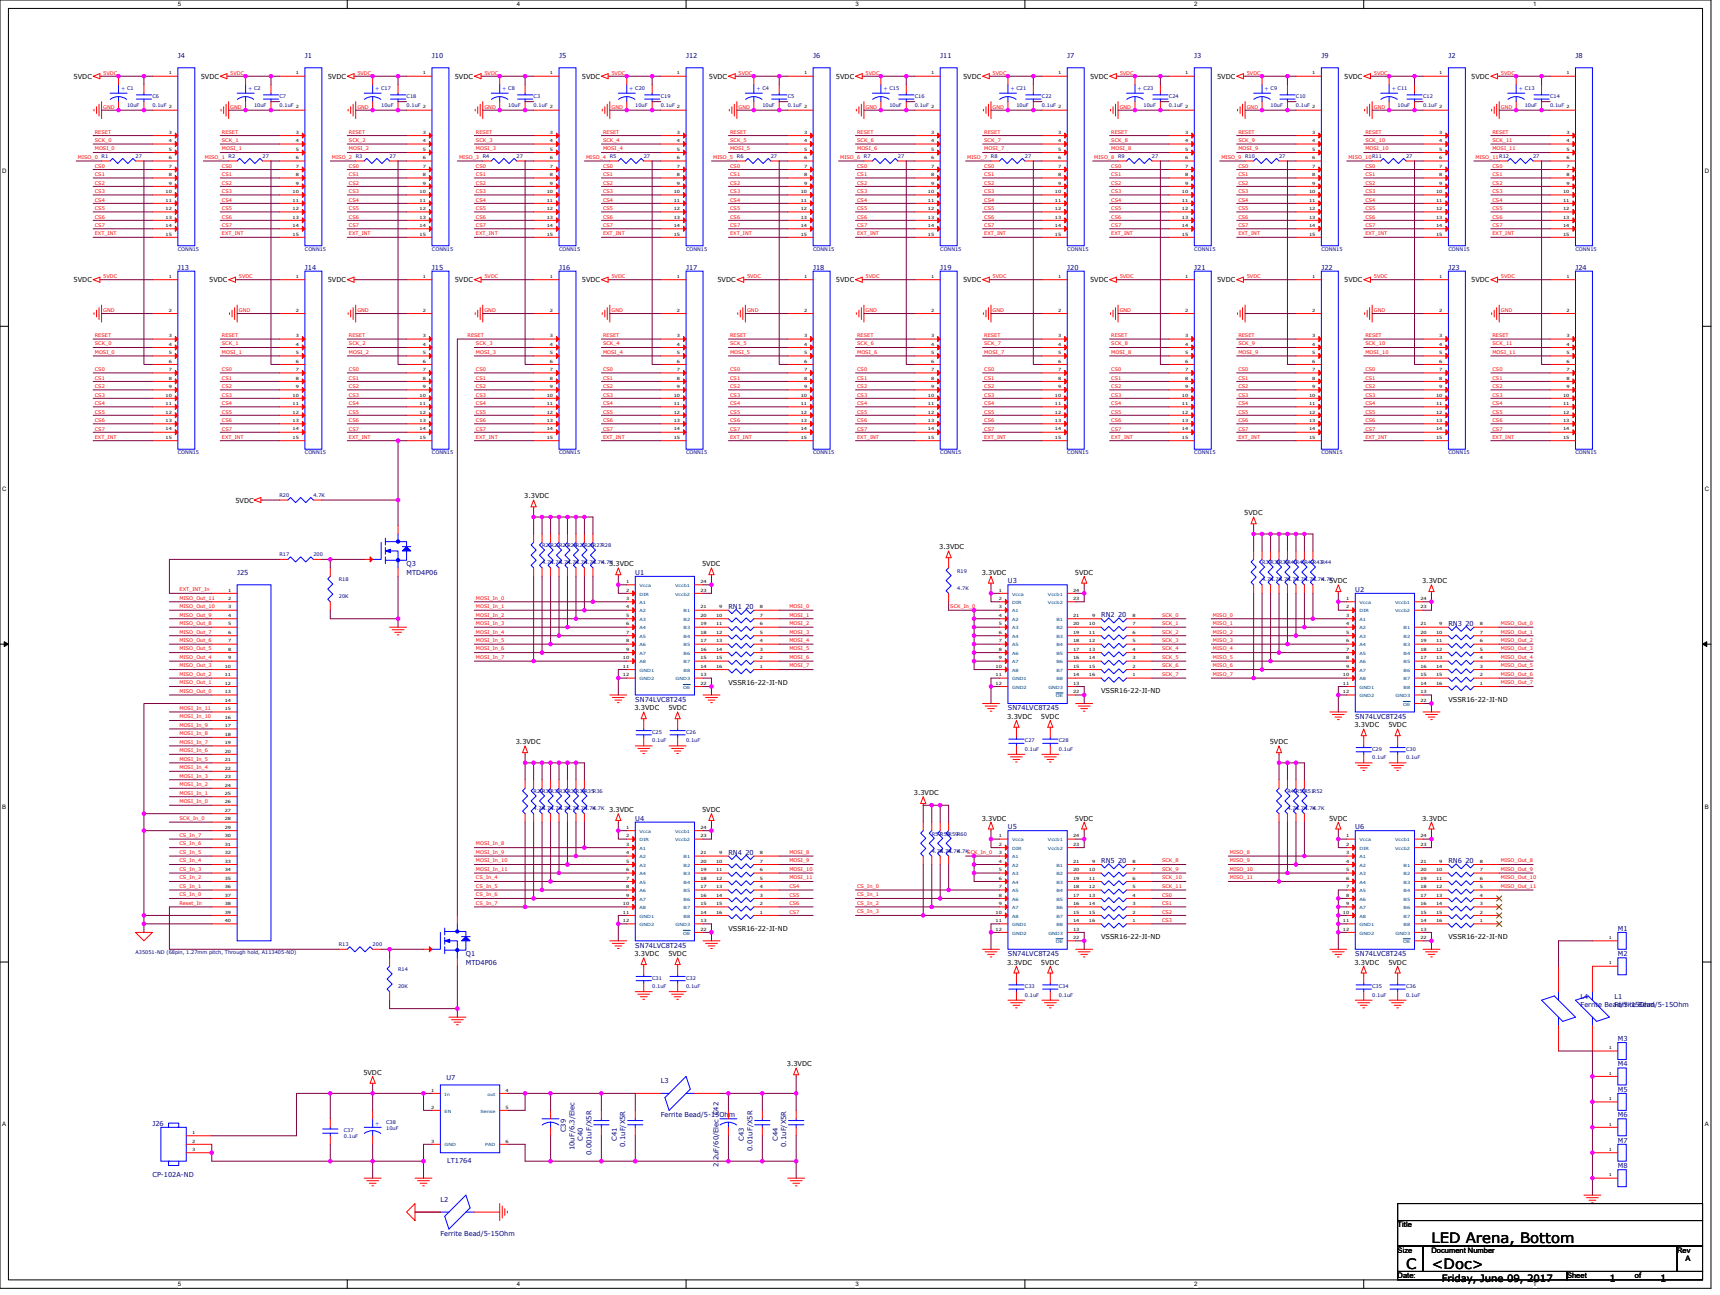
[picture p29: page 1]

A35051-ND (68pin, 1.27mm pitch, Through hold, A113405-ND)

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

Date: Date: Date: Friday, June 09, 2017 Friday, June 09, 2017 Friday, June 09, 2017 | Sheet Sheet Sheet 1 1 1 of of of 1 1 1

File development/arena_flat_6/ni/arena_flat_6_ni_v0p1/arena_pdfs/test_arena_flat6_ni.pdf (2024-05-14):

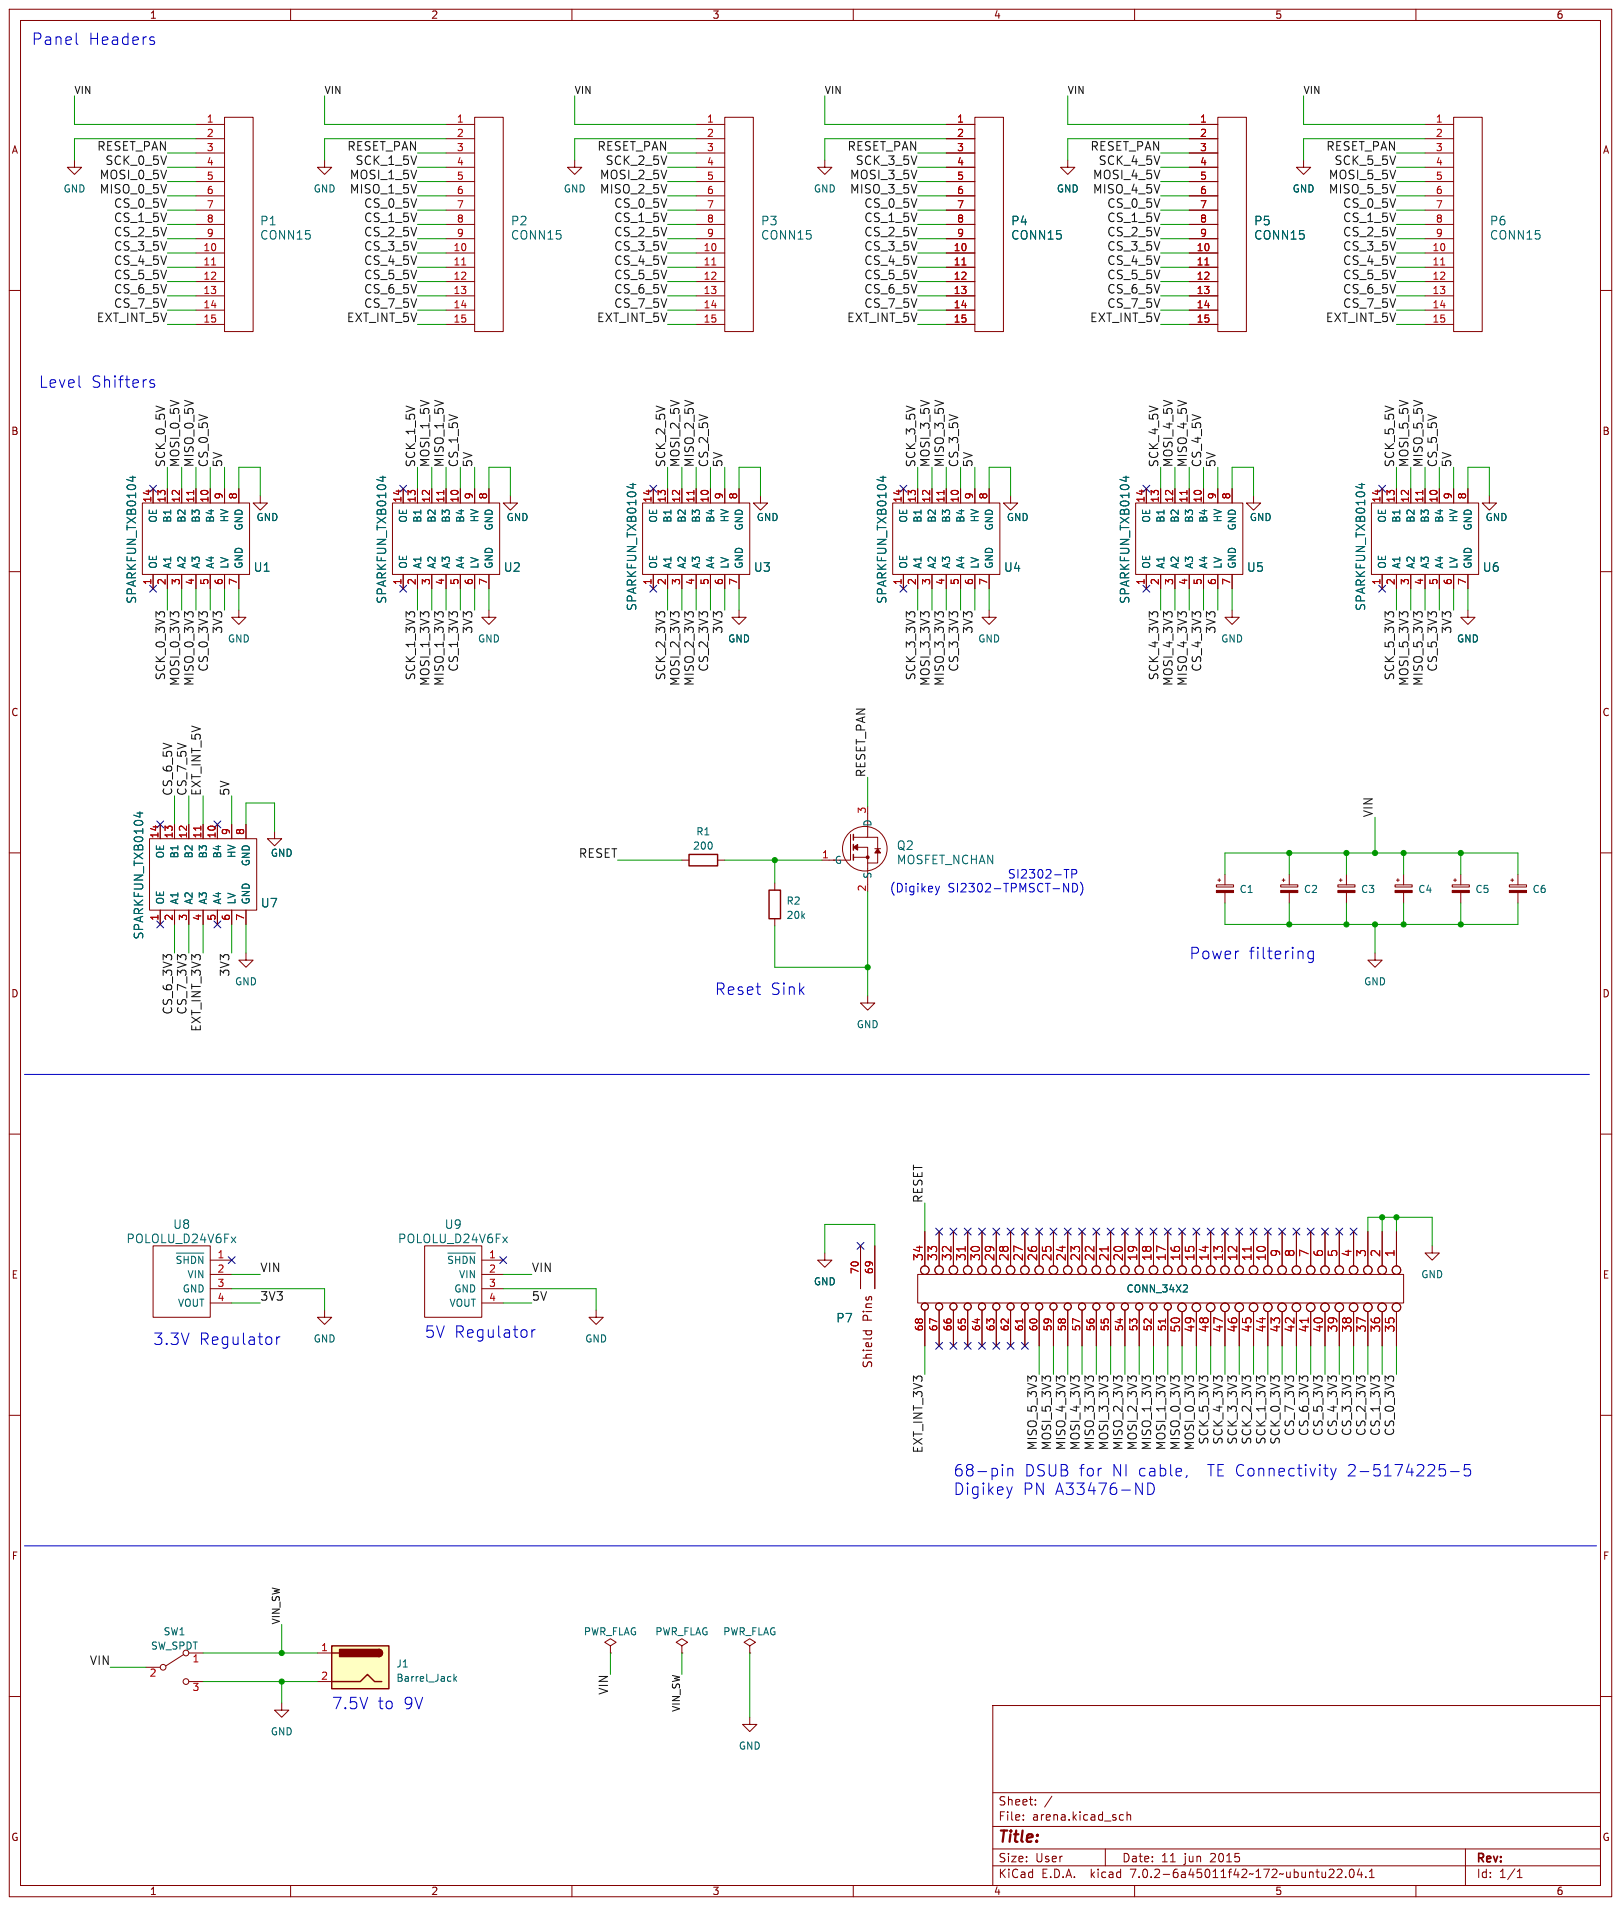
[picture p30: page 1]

9 GND GND GND U6 SPARKFUN_TXB0104 OE

~{SHDN} 1 VIN 2 GND 3 VOUT 4 U8 POLOLU_D24V6Fx GND

Id: 1/1 Title: File: arena.kicad_sch Sheet: /

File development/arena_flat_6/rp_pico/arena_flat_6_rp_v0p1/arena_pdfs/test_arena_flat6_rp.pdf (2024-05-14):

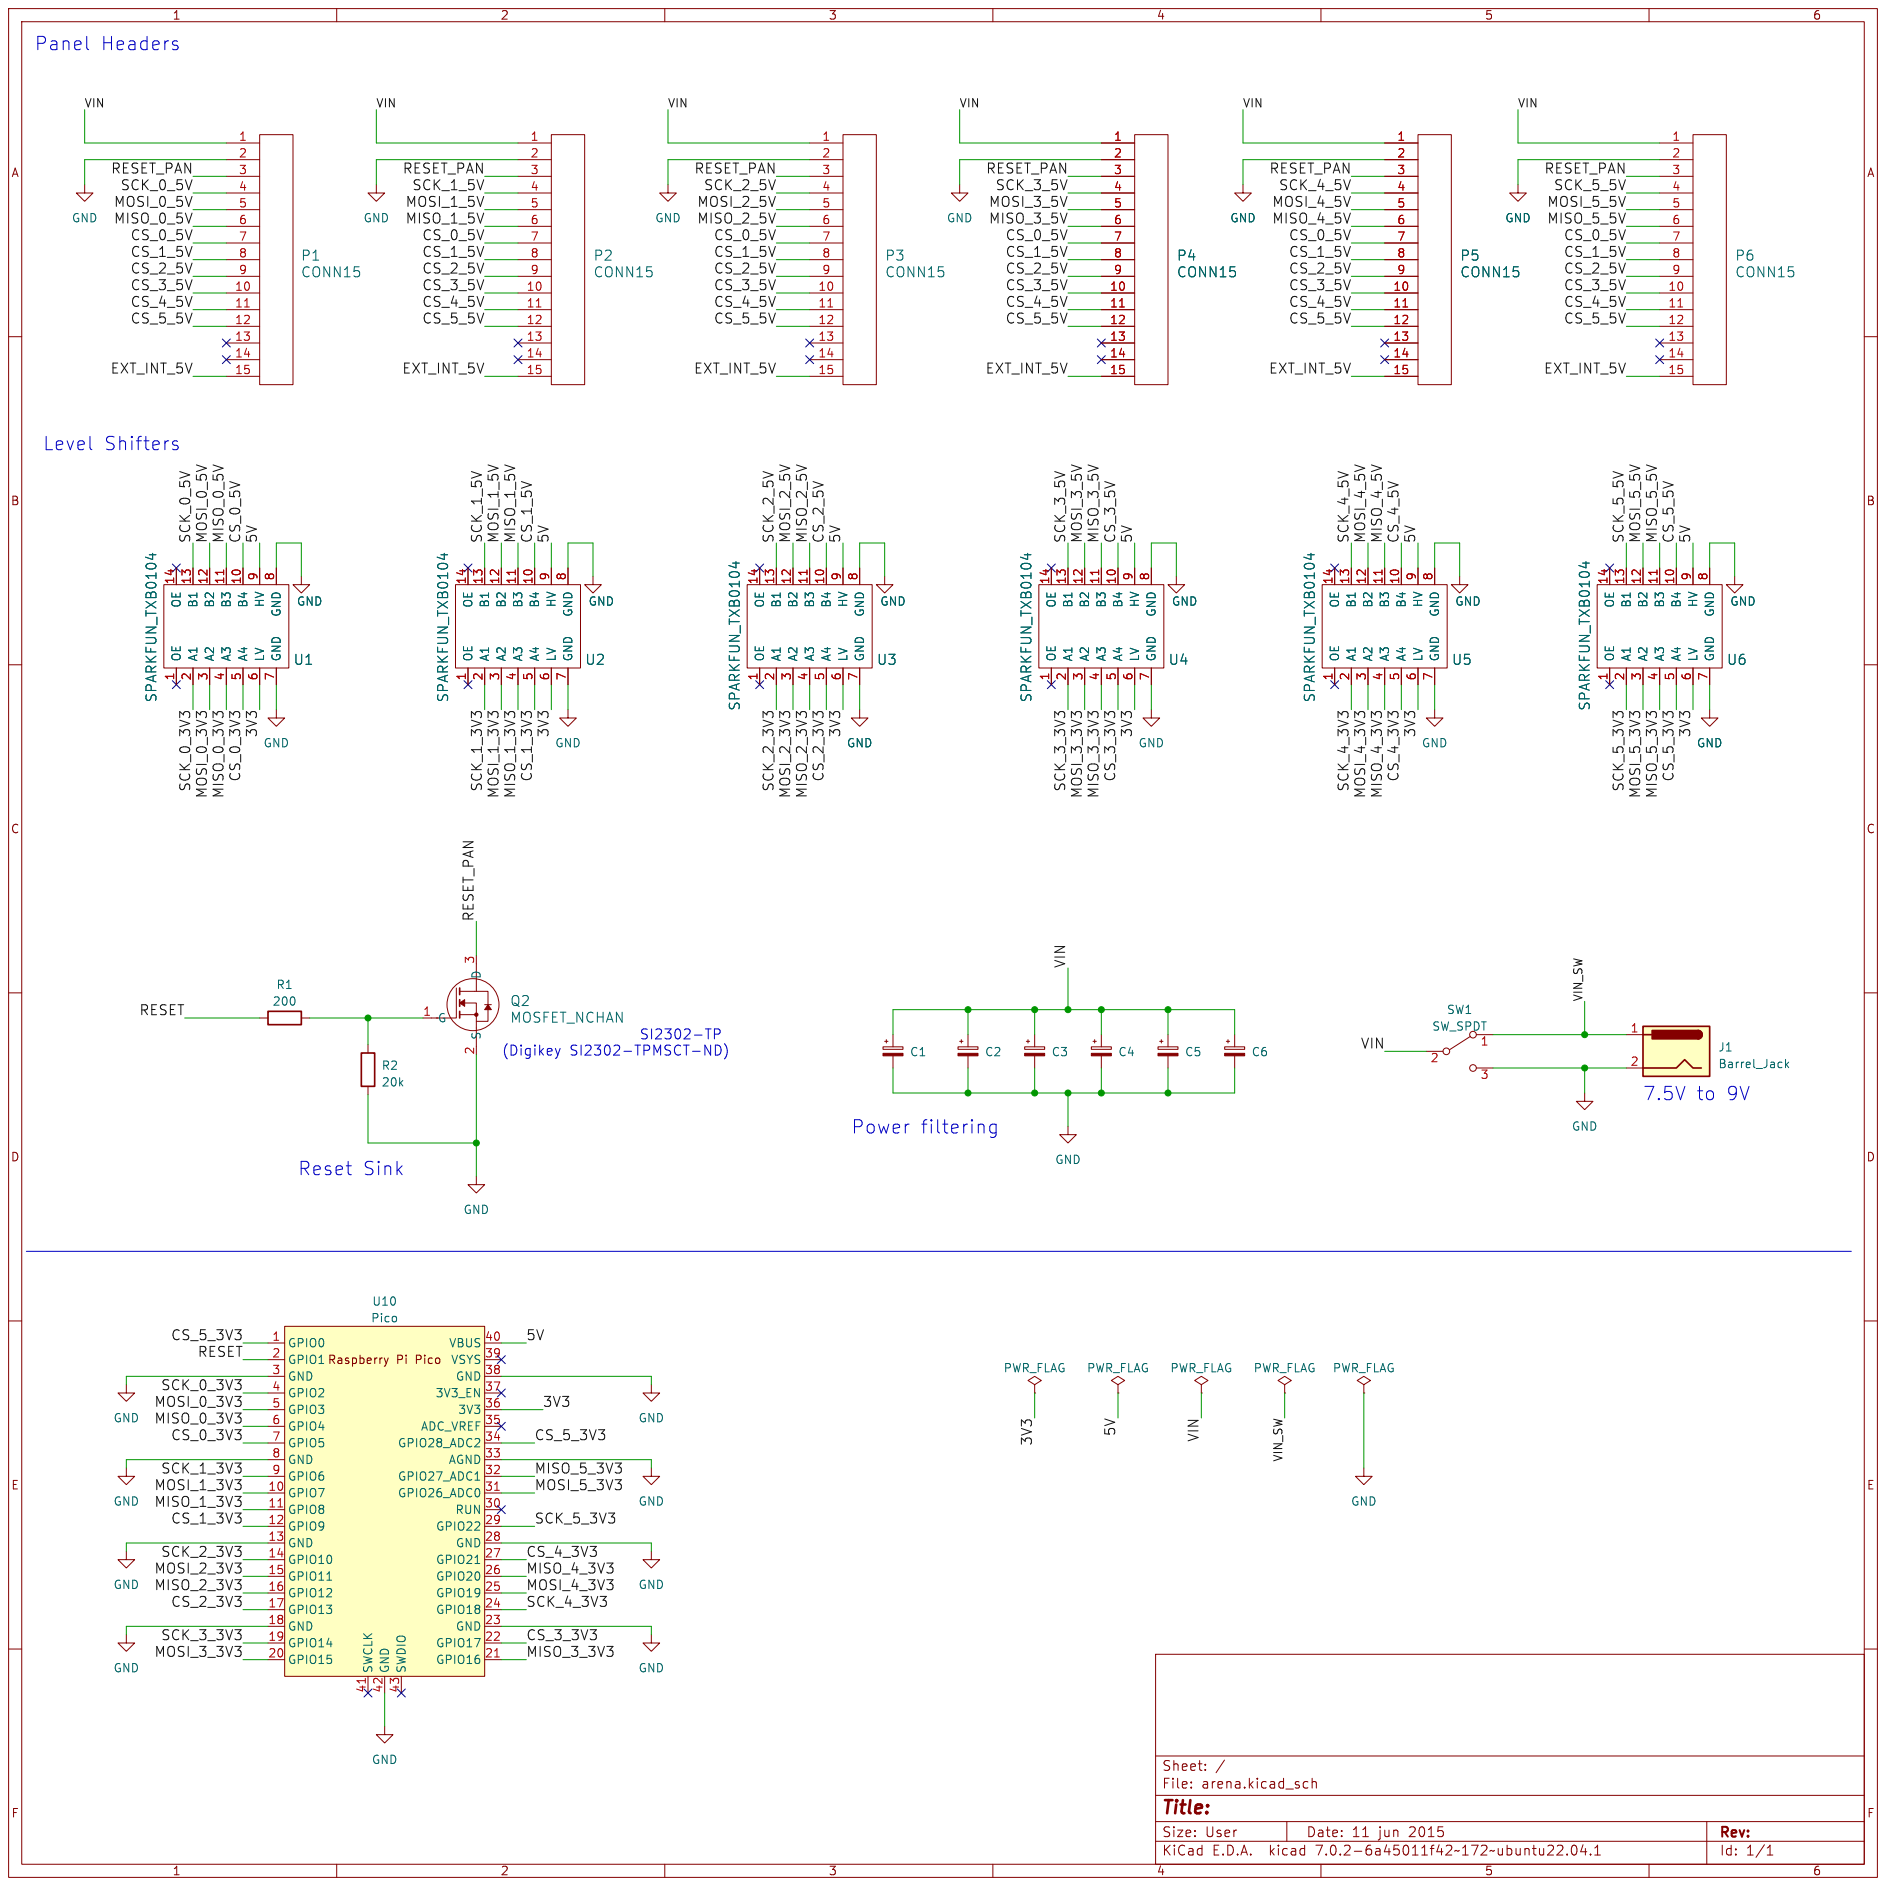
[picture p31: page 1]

Id: 1/1 Title: File: arena.kicad_sch Sheet: / OE

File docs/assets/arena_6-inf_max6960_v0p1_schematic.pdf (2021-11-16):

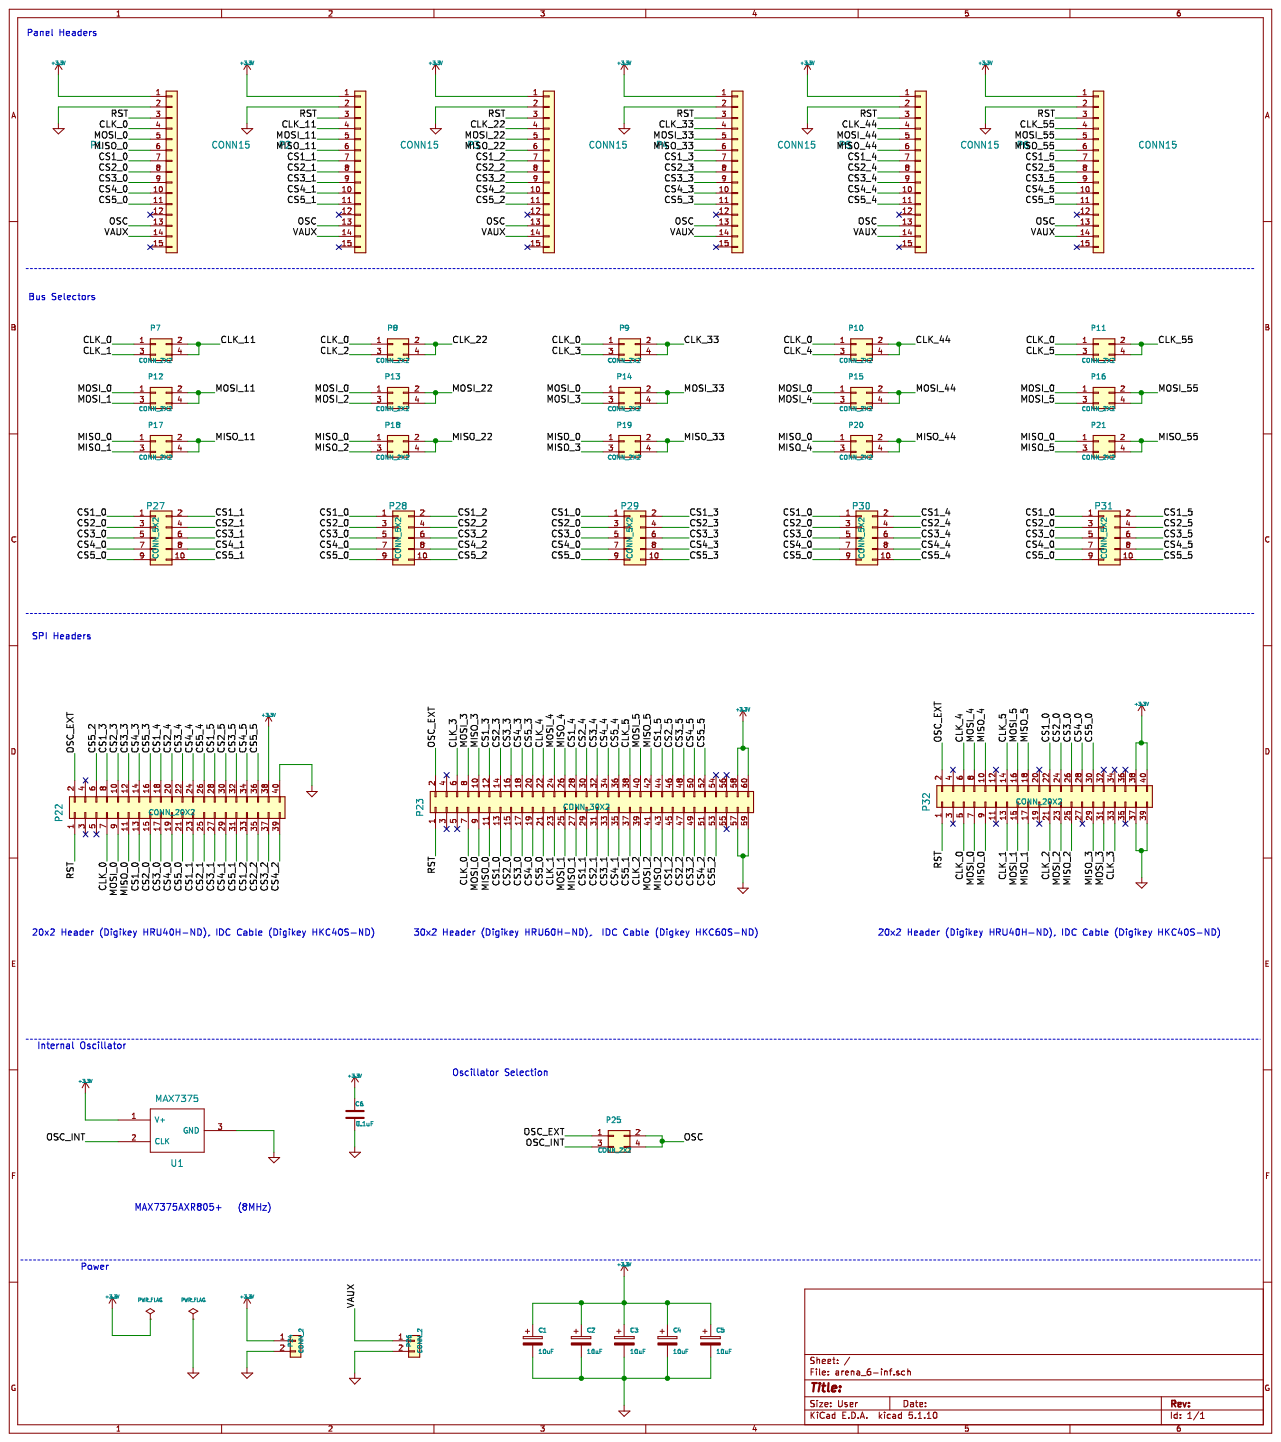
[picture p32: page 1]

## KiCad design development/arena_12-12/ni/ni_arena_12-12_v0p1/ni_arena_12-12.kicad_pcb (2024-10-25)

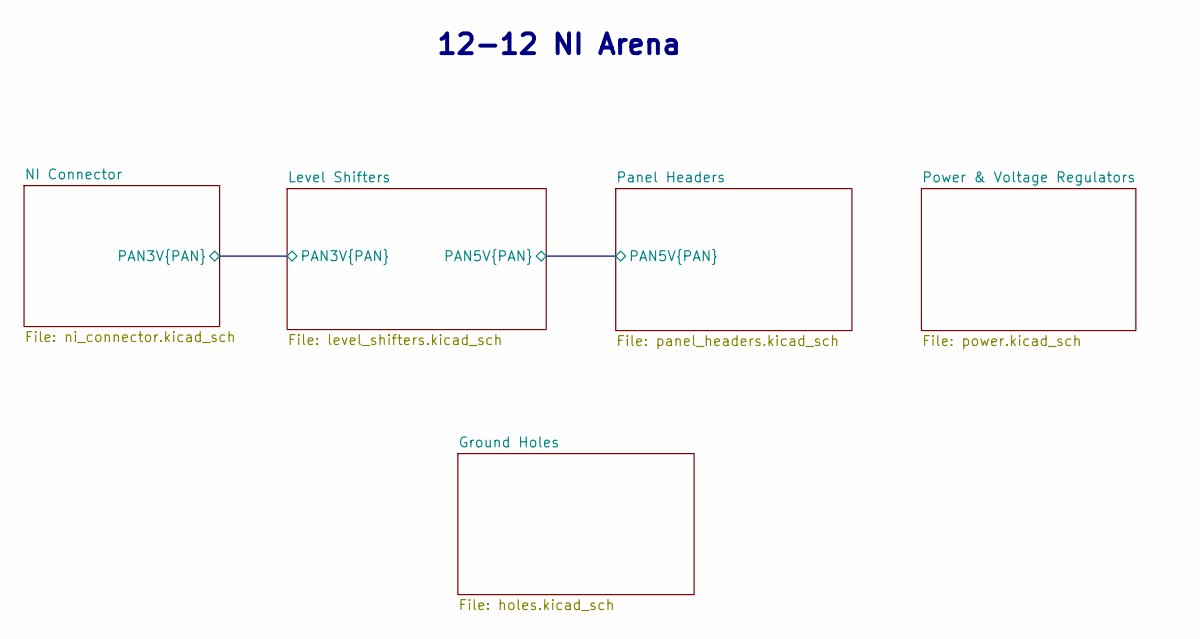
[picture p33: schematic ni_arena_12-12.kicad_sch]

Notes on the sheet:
12-12 NI Arena

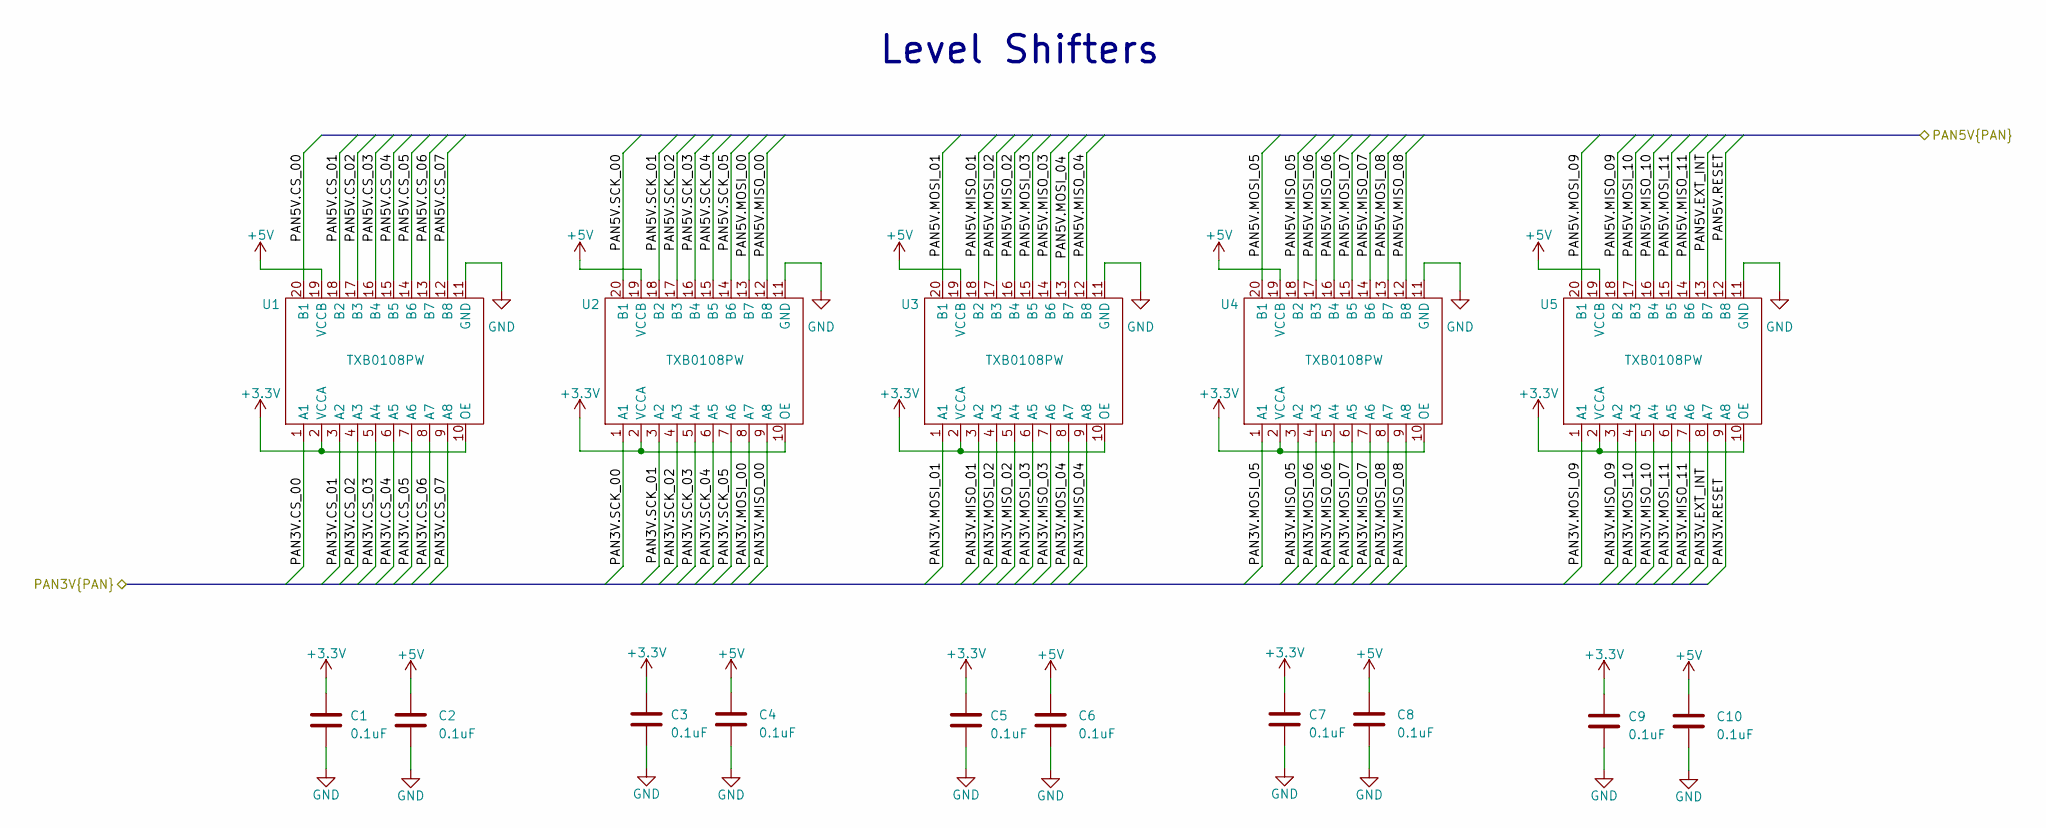
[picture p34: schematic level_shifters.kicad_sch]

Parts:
C1, C2, C3, C4, C5, C6, C7, C8, C9, C10: 0.1uF; C_0603_1608Metric
U1, U2, U3, U4, U5: TXB0108PW; TSSOP-20_4.4x6.5mm_P0.65mm

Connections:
+3.3V: C1.1, C3.1, C5.1, C7.1, C9.1, U1.2 (VCCA), U1.10 (OE), U2.2 (VCCA), U2.10 (OE), U3.2 (VCCA), U3.10 (OE), U4.2 (VCCA), U4.10 (OE), U5.2 (VCCA), U5.10 (OE); also elsewhere on the board
+5V: C2.1, C4.1, C6.1, C8.1, C10.1, U1.19 (VCCB), U2.19 (VCCB), U3.19 (VCCB), U4.19 (VCCB), U5.19 (VCCB); also elsewhere on the board
/Level Shifters/PAN3V.CS_00: U1.1 (A1); also elsewhere on the board
/Level Shifters/PAN3V.CS_01: U1.3 (A2); also elsewhere on the board
/Level Shifters/PAN3V.CS_02: U1.4 (A3); also elsewhere on the board
/Level Shifters/PAN3V.CS_03: U1.5 (A4); also elsewhere on the board
/Level Shifters/PAN3V.CS_04: U1.6 (A5); also elsewhere on the board
/Level Shifters/PAN3V.CS_05: U1.7 (A6); also elsewhere on the board
/Level Shifters/PAN3V.CS_06: U1.8 (A7); also elsewhere on the board
/Level Shifters/PAN3V.CS_07: U1.9 (A8); also elsewhere on the board
/Level Shifters/PAN3V.EXT_INT: U5.8 (A7); also elsewhere on the board
/Level Shifters/PAN3V.MISO_00: U2.9 (A8); also elsewhere on the board
/Level Shifters/PAN3V.MISO_01: U3.3 (A2); also elsewhere on the board
/Level Shifters/PAN3V.MISO_02: U3.5 (A4); also elsewhere on the board
/Level Shifters/PAN3V.MISO_03: U3.7 (A6); also elsewhere on the board
/Level Shifters/PAN3V.MISO_04: U3.9 (A8); also elsewhere on the board
/Level Shifters/PAN3V.MISO_05: U4.3 (A2); also elsewhere on the board
/Level Shifters/PAN3V.MISO_06: U4.5 (A4); also elsewhere on the board
/Level Shifters/PAN3V.MISO_07: U4.7 (A6); also elsewhere on the board
/Level Shifters/PAN3V.MISO_08: U4.9 (A8); also elsewhere on the board
/Level Shifters/PAN3V.MISO_09: U5.3 (A2); also elsewhere on the board
/Level Shifters/PAN3V.MISO_10: U5.5 (A4); also elsewhere on the board
/Level Shifters/PAN3V.MISO_11: U5.7 (A6); also elsewhere on the board
/Level Shifters/PAN3V.MOSI_00: U2.8 (A7); also elsewhere on the board
/Level Shifters/PAN3V.MOSI_01: U3.1 (A1); also elsewhere on the board
/Level Shifters/PAN3V.MOSI_02: U3.4 (A3); also elsewhere on the board
/Level Shifters/PAN3V.MOSI_03: U3.6 (A5); also elsewhere on the board
/Level Shifters/PAN3V.MOSI_04: U3.8 (A7); also elsewhere on the board
/Level Shifters/PAN3V.MOSI_05: U4.1 (A1); also elsewhere on the board
/Level Shifters/PAN3V.MOSI_06: U4.4 (A3); also elsewhere on the board
/Level Shifters/PAN3V.MOSI_07: U4.6 (A5); also elsewhere on the board
/Level Shifters/PAN3V.MOSI_08: U4.8 (A7); also elsewhere on the board
/Level Shifters/PAN3V.MOSI_09: U5.1 (A1); also elsewhere on the board
/Level Shifters/PAN3V.MOSI_10: U5.4 (A3); also elsewhere on the board
/Level Shifters/PAN3V.MOSI_11: U5.6 (A5); also elsewhere on the board
/Level Shifters/PAN3V.RESET: U5.9 (A8); also elsewhere on the board
/Level Shifters/PAN3V.SCK_00: U2.1 (A1); also elsewhere on the board
/Level Shifters/PAN3V.SCK_01: U2.3 (A2); also elsewhere on the board
/Level Shifters/PAN3V.SCK_02: U2.4 (A3); also elsewhere on the board
/Level Shifters/PAN3V.SCK_03: U2.5 (A4); also elsewhere on the board
/Level Shifters/PAN3V.SCK_04: U2.6 (A5); also elsewhere on the board
/Level Shifters/PAN3V.SCK_05: U2.7 (A6); also elsewhere on the board
/Level Shifters/PAN5V.CS_00: U1.20 (B1); also elsewhere on the board
/Level Shifters/PAN5V.CS_01: U1.18 (B2); also elsewhere on the board
/Level Shifters/PAN5V.CS_02: U1.17 (B3); also elsewhere on the board
/Level Shifters/PAN5V.CS_03: U1.16 (B4); also elsewhere on the board
/Level Shifters/PAN5V.CS_04: U1.15 (B5); also elsewhere on the board
/Level Shifters/PAN5V.CS_05: U1.14 (B6); also elsewhere on the board
/Level Shifters/PAN5V.CS_06: U1.13 (B7); also elsewhere on the board
/Level Shifters/PAN5V.CS_07: U1.12 (B8); also elsewhere on the board
/Level Shifters/PAN5V.EXT_INT: U5.13 (B7); also elsewhere on the board
/Level Shifters/PAN5V.MISO_00: U2.12 (B8); also elsewhere on the board
/Level Shifters/PAN5V.MISO_01: U3.18 (B2); also elsewhere on the board
/Level Shifters/PAN5V.MISO_02: U3.16 (B4); also elsewhere on the board
/Level Shifters/PAN5V.MISO_03: U3.14 (B6); also elsewhere on the board
/Level Shifters/PAN5V.MISO_04: U3.12 (B8); also elsewhere on the board
/Level Shifters/PAN5V.MISO_05: U4.18 (B2); also elsewhere on the board
/Level Shifters/PAN5V.MISO_06: U4.16 (B4); also elsewhere on the board
/Level Shifters/PAN5V.MISO_07: U4.14 (B6); also elsewhere on the board
/Level Shifters/PAN5V.MISO_08: U4.12 (B8); also elsewhere on the board
/Level Shifters/PAN5V.MISO_09: U5.18 (B2); also elsewhere on the board
/Level Shifters/PAN5V.MISO_10: U5.16 (B4); also elsewhere on the board
/Level Shifters/PAN5V.MISO_11: U5.14 (B6); also elsewhere on the board
/Level Shifters/PAN5V.MOSI_00: U2.13 (B7); also elsewhere on the board
/Level Shifters/PAN5V.MOSI_01: U3.20 (B1); also elsewhere on the board
/Level Shifters/PAN5V.MOSI_02: U3.17 (B3); also elsewhere on the board
/Level Shifters/PAN5V.MOSI_03: U3.15 (B5); also elsewhere on the board
/Level Shifters/PAN5V.MOSI_04: U3.13 (B7); also elsewhere on the board
/Level Shifters/PAN5V.MOSI_05: U4.20 (B1); also elsewhere on the board
/Level Shifters/PAN5V.MOSI_06: U4.17 (B3); also elsewhere on the board
/Level Shifters/PAN5V.MOSI_07: U4.15 (B5); also elsewhere on the board
/Level Shifters/PAN5V.MOSI_08: U4.13 (B7); also elsewhere on the board
/Level Shifters/PAN5V.MOSI_09: U5.20 (B1); also elsewhere on the board
/Level Shifters/PAN5V.MOSI_10: U5.17 (B3); also elsewhere on the board
/Level Shifters/PAN5V.MOSI_11: U5.15 (B5); also elsewhere on the board
/Level Shifters/PAN5V.RESET: U5.12 (B8); also elsewhere on the board
/Level Shifters/PAN5V.SCK_00: U2.20 (B1); also elsewhere on the board
/Level Shifters/PAN5V.SCK_01: U2.18 (B2); also elsewhere on the board
/Level Shifters/PAN5V.SCK_02: U2.17 (B3); also elsewhere on the board
/Level Shifters/PAN5V.SCK_03: U2.16 (B4); also elsewhere on the board
/Level Shifters/PAN5V.SCK_04: U2.15 (B5); also elsewhere on the board
/Level Shifters/PAN5V.SCK_05: U2.14 (B6); also elsewhere on the board
GND: C1.2, C2.2, C3.2, C4.2, C5.2, C6.2, C7.2, C8.2, C9.2, C10.2, U1.11 (GND), U2.11 (GND), U3.11 (GND), U4.11 (GND), U5.11 (GND); also elsewhere on the board

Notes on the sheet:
Level Shifters

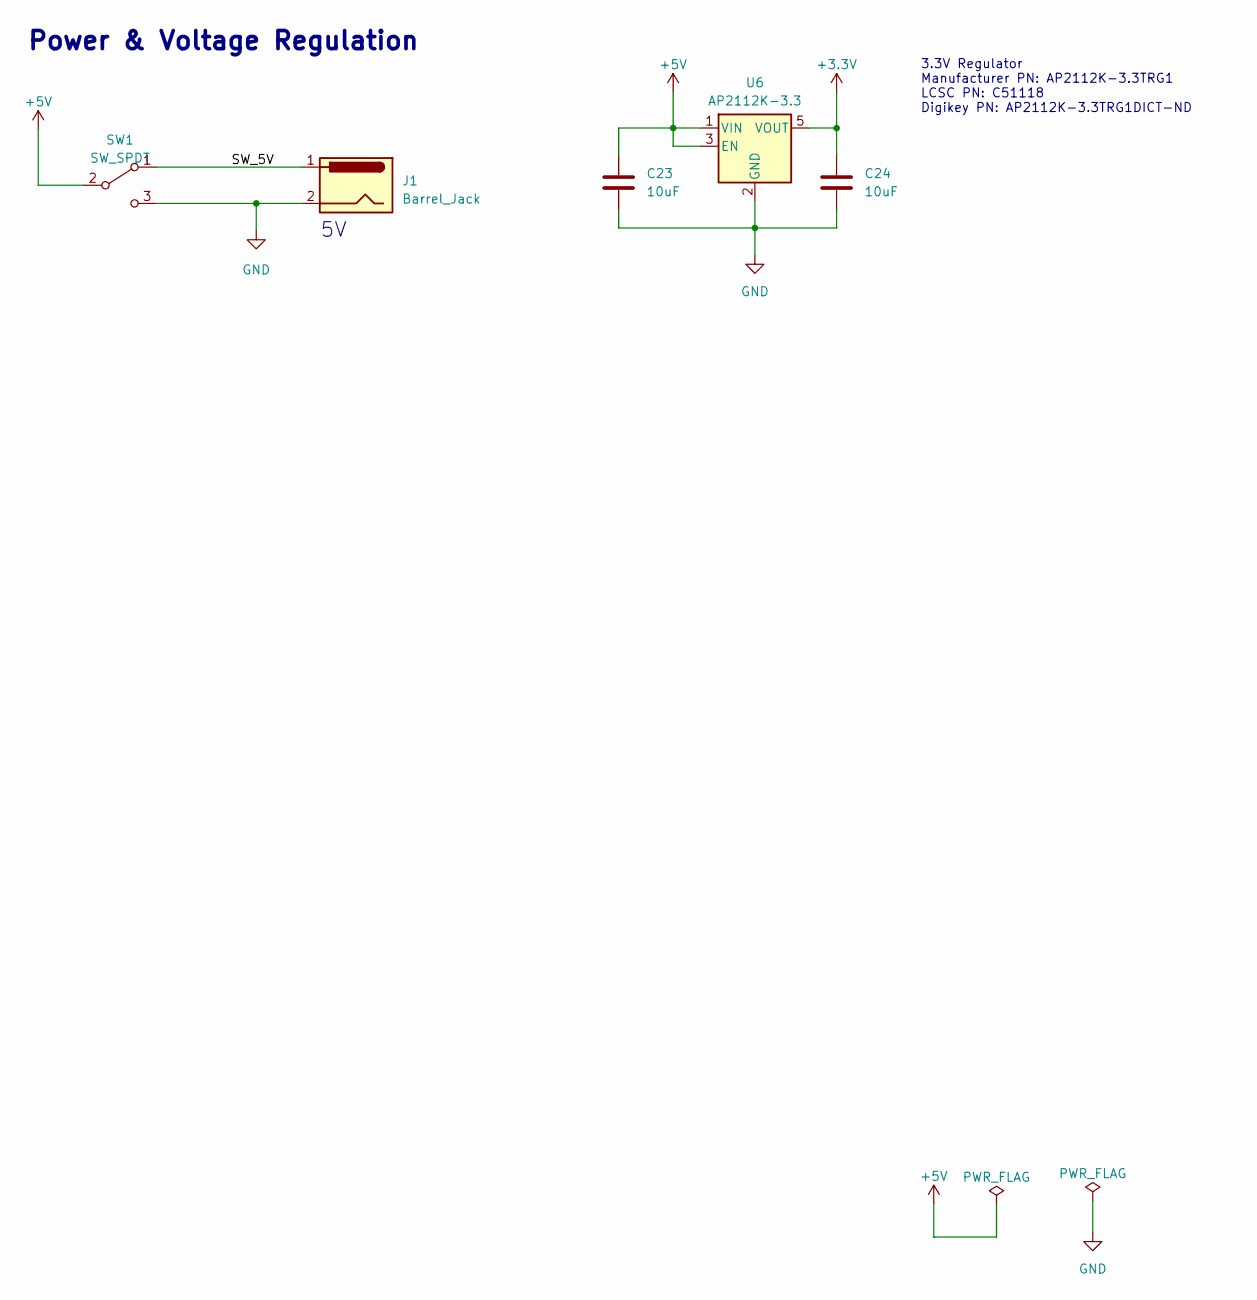
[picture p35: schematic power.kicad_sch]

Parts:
C23, C24: 10uF; C_0603_1608Metric
J1: Barrel_Jack; DCJACK_2PIN_HIGHCURRENT
SW1: SW_SPDT; slide_switch
U6: AP2112K-3.3; SOT-23-5

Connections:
+3.3V: C24.1, U6.5 (VOUT); also elsewhere on the board
+5V: C23.1, SW1.2 (B), U6.1 (VIN), U6.3 (EN); also elsewhere on the board
GND: C23.2, C24.2, J1.2, SW1.3 (C), U6.2 (GND); also elsewhere on the board
unnamed: J1.1, SW1.1 (A)

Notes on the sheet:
3.3V Regulator Manufacturer PN: AP2112K-3.3TRG1 LCSC PN: C51118 Digikey PN: AP2112K-3.3TRG1DICT-ND
Power & Voltage Regulation

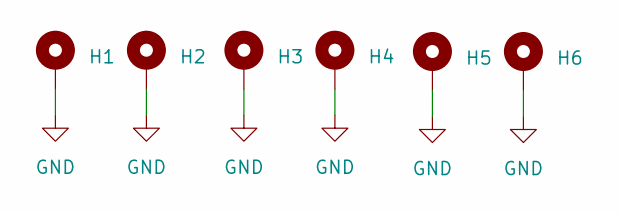
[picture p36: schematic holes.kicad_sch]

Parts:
H1, H2, H3, H4, H5, H6: MountingHole_Pad; MountingHole_4.5mm_Pad

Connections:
GND: H1.1, H2.1, H3.1, H4.1, H5.1, H6.1; also elsewhere on the board

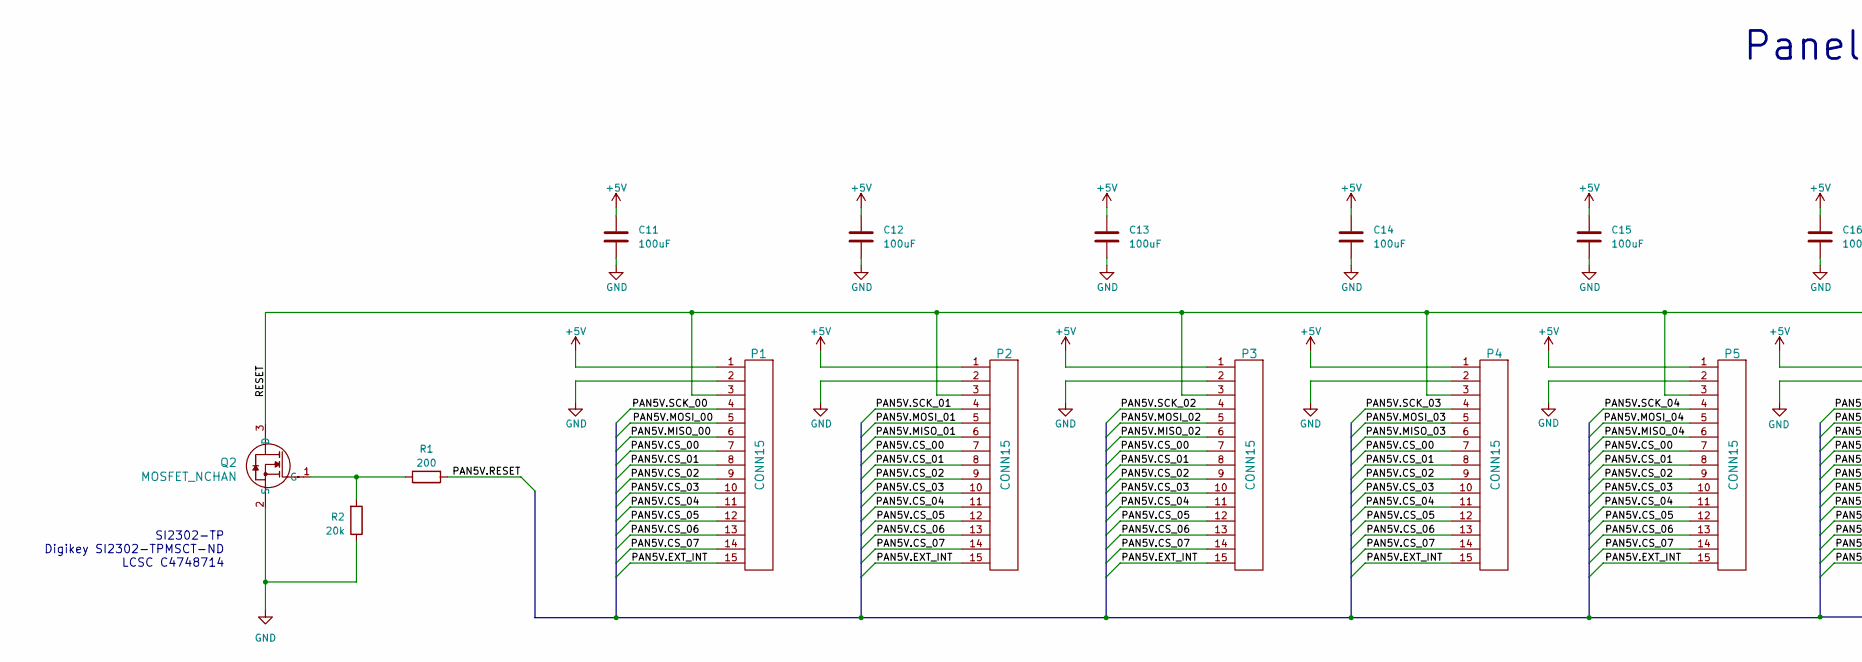
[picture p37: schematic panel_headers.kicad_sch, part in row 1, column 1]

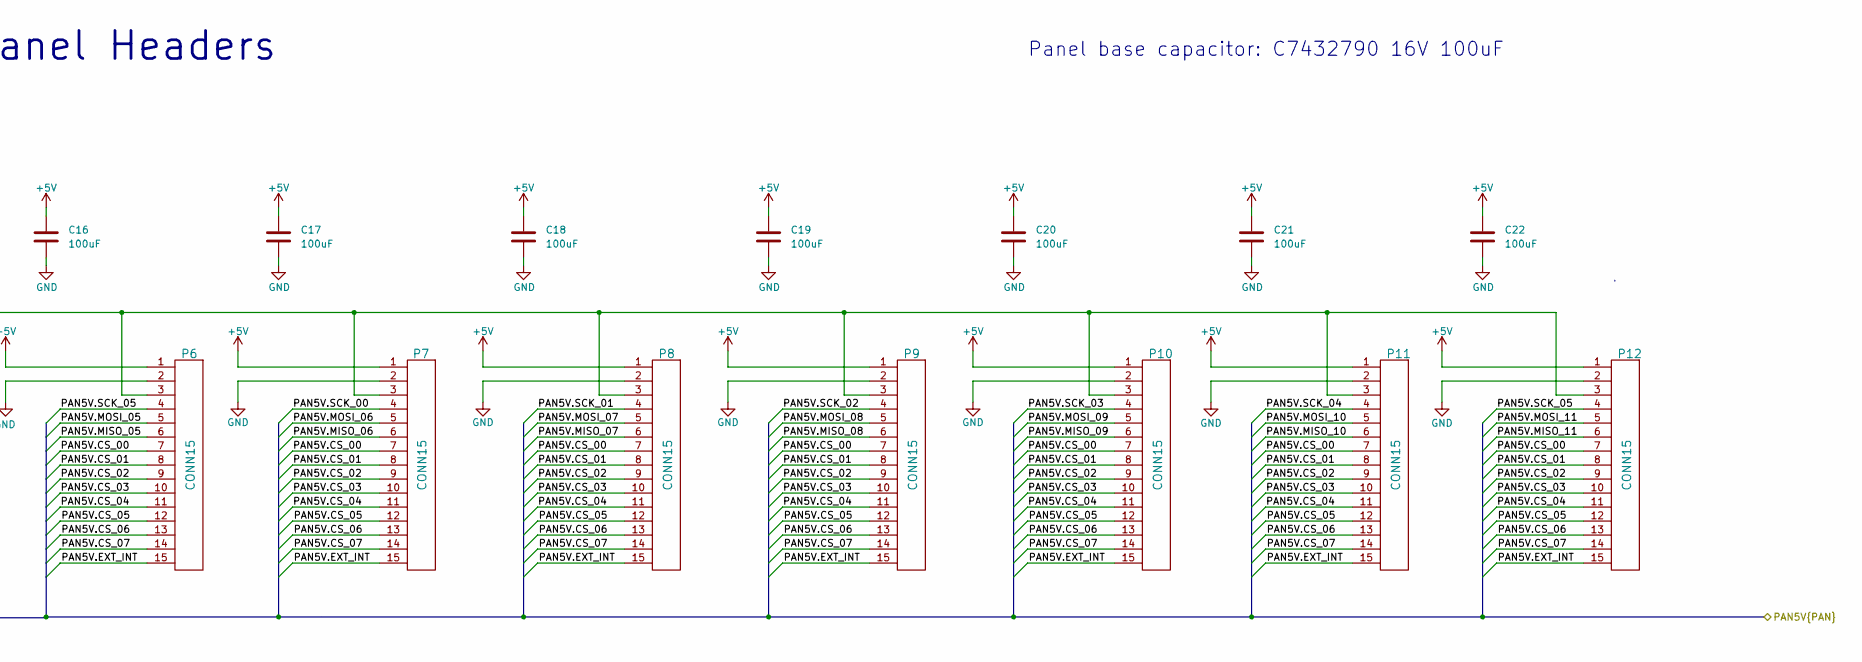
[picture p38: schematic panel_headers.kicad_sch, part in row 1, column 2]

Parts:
C11, C12, C13, C14, C15, C16, C17, C18, C19, C20, C21, C22: 100uF; C_1210_3225Metric
P1, P2, P3, P4, P5, P6, P7, P8, P9, P10, P11, P12: CONN15; HEADER_TOP
Q2: MOSFET_NCHAN; SOT-23-3
R1: 200; R_0805_2012Metric
R2: 20k; R_0805_2012Metric

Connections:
+5V: C11.1, C12.1, C13.1, C14.1, C15.1, C16.1, C17.1, C18.1, C19.1, C20.1, C21.1, C22.1, P1.1, P2.1, P3.1, P4.1, P5.1, P6.1, P7.1, P8.1, P9.1, P10.1, P11.1, P12.1; also elsewhere on the board
/Level Shifters/PAN5V.CS_00: P1.7, P2.7, P3.7, P4.7, P5.7, P6.7, P7.7, P8.7, P9.7, P10.7, P11.7, P12.7; also elsewhere on the board
/Level Shifters/PAN5V.CS_01: P1.8, P2.8, P3.8, P4.8, P5.8, P6.8, P7.8, P8.8, P9.8, P10.8, P11.8, P12.8; also elsewhere on the board
/Level Shifters/PAN5V.CS_02: P1.9, P2.9, P3.9, P4.9, P5.9, P6.9, P7.9, P8.9, P9.9, P10.9, P11.9, P12.9; also elsewhere on the board
/Level Shifters/PAN5V.CS_03: P1.10, P2.10, P3.10, P4.10, P5.10, P6.10, P7.10, P8.10, P9.10, P10.10, P11.10, P12.10; also elsewhere on the board
/Level Shifters/PAN5V.CS_04: P1.11, P2.11, P3.11, P4.11, P5.11, P6.11, P7.11, P8.11, P9.11, P10.11, P11.11, P12.11; also elsewhere on the board
/Level Shifters/PAN5V.CS_05: P1.12, P2.12, P3.12, P4.12, P5.12, P6.12, P7.12, P8.12, P9.12, P10.12, P11.12, P12.12; also elsewhere on the board
/Level Shifters/PAN5V.CS_06: P1.13, P2.13, P3.13, P4.13, P5.13, P6.13, P7.13, P8.13, P9.13, P10.13, P11.13, P12.13; also elsewhere on the board
/Level Shifters/PAN5V.CS_07: P1.14, P2.14, P3.14, P4.14, P5.14, P6.14, P7.14, P8.14, P9.14, P10.14, P11.14, P12.14; also elsewhere on the board
/Level Shifters/PAN5V.EXT_INT: P1.15, P2.15, P3.15, P4.15, P5.15, P6.15, P7.15, P8.15, P9.15, P10.15, P11.15, P12.15; also elsewhere on the board
/Level Shifters/PAN5V.MISO_00: P1.6; also elsewhere on the board
/Level Shifters/PAN5V.MISO_01: P2.6; also elsewhere on the board
/Level Shifters/PAN5V.MISO_02: P3.6; also elsewhere on the board
/Level Shifters/PAN5V.MISO_03: P4.6; also elsewhere on the board
/Level Shifters/PAN5V.MISO_04: P5.6; also elsewhere on the board
/Level Shifters/PAN5V.MISO_05: P6.6; also elsewhere on the board
/Level Shifters/PAN5V.MISO_06: P7.6; also elsewhere on the board
/Level Shifters/PAN5V.MISO_07: P8.6; also elsewhere on the board
/Level Shifters/PAN5V.MISO_08: P9.6; also elsewhere on the board
/Level Shifters/PAN5V.MISO_09: P10.6; also elsewhere on the board
/Level Shifters/PAN5V.MISO_10: P11.6; also elsewhere on the board
/Level Shifters/PAN5V.MISO_11: P12.6; also elsewhere on the board
/Level Shifters/PAN5V.MOSI_00: P1.5; also elsewhere on the board
/Level Shifters/PAN5V.MOSI_01: P2.5; also elsewhere on the board
/Level Shifters/PAN5V.MOSI_02: P3.5; also elsewhere on the board
/Level Shifters/PAN5V.MOSI_03: P4.5; also elsewhere on the board
/Level Shifters/PAN5V.MOSI_04: P5.5; also elsewhere on the board
/Level Shifters/PAN5V.MOSI_05: P6.5; also elsewhere on the board
/Level Shifters/PAN5V.MOSI_06: P7.5; also elsewhere on the board
/Level Shifters/PAN5V.MOSI_07: P8.5; also elsewhere on the board
/Level Shifters/PAN5V.MOSI_08: P9.5; also elsewhere on the board
/Level Shifters/PAN5V.MOSI_09: P10.5; also elsewhere on the board
/Level Shifters/PAN5V.MOSI_10: P11.5; also elsewhere on the board
/Level Shifters/PAN5V.MOSI_11: P12.5; also elsewhere on the board
/Level Shifters/PAN5V.RESET: R1.2; also elsewhere on the board
/Level Shifters/PAN5V.SCK_00: P1.4, P7.4; also elsewhere on the board
/Level Shifters/PAN5V.SCK_01: P2.4, P8.4; also elsewhere on the board
/Level Shifters/PAN5V.SCK_02: P3.4, P9.4; also elsewhere on the board
/Level Shifters/PAN5V.SCK_03: P4.4, P10.4; also elsewhere on the board
/Level Shifters/PAN5V.SCK_04: P5.4, P11.4; also elsewhere on the board
/Level Shifters/PAN5V.SCK_05: P6.4, P12.4; also elsewhere on the board
/Panel Headers/RESET: P1.3, P2.3, P3.3, P4.3, P5.3, P6.3, P7.3, P8.3, P9.3, P10.3, P11.3, P12.3, Q2.3 (D)
GND: C11.2, C12.2, C13.2, C14.2, C15.2, C16.2, C17.2, C18.2, C19.2, C20.2, C21.2, C22.2, P1.2, P2.2, P3.2, P4.2, P5.2, P6.2, P7.2, P8.2, P9.2, P10.2, P11.2, P12.2, Q2.2 (S), R2.1; also elsewhere on the board
unnamed: Q2.1 (G), R1.1, R2.2

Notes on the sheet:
Panel base capacitor: C7432790 16V 100uF
Panel Headers
SI2302-TP Digikey SI2302-TPMSCT-ND LCSC C4748714

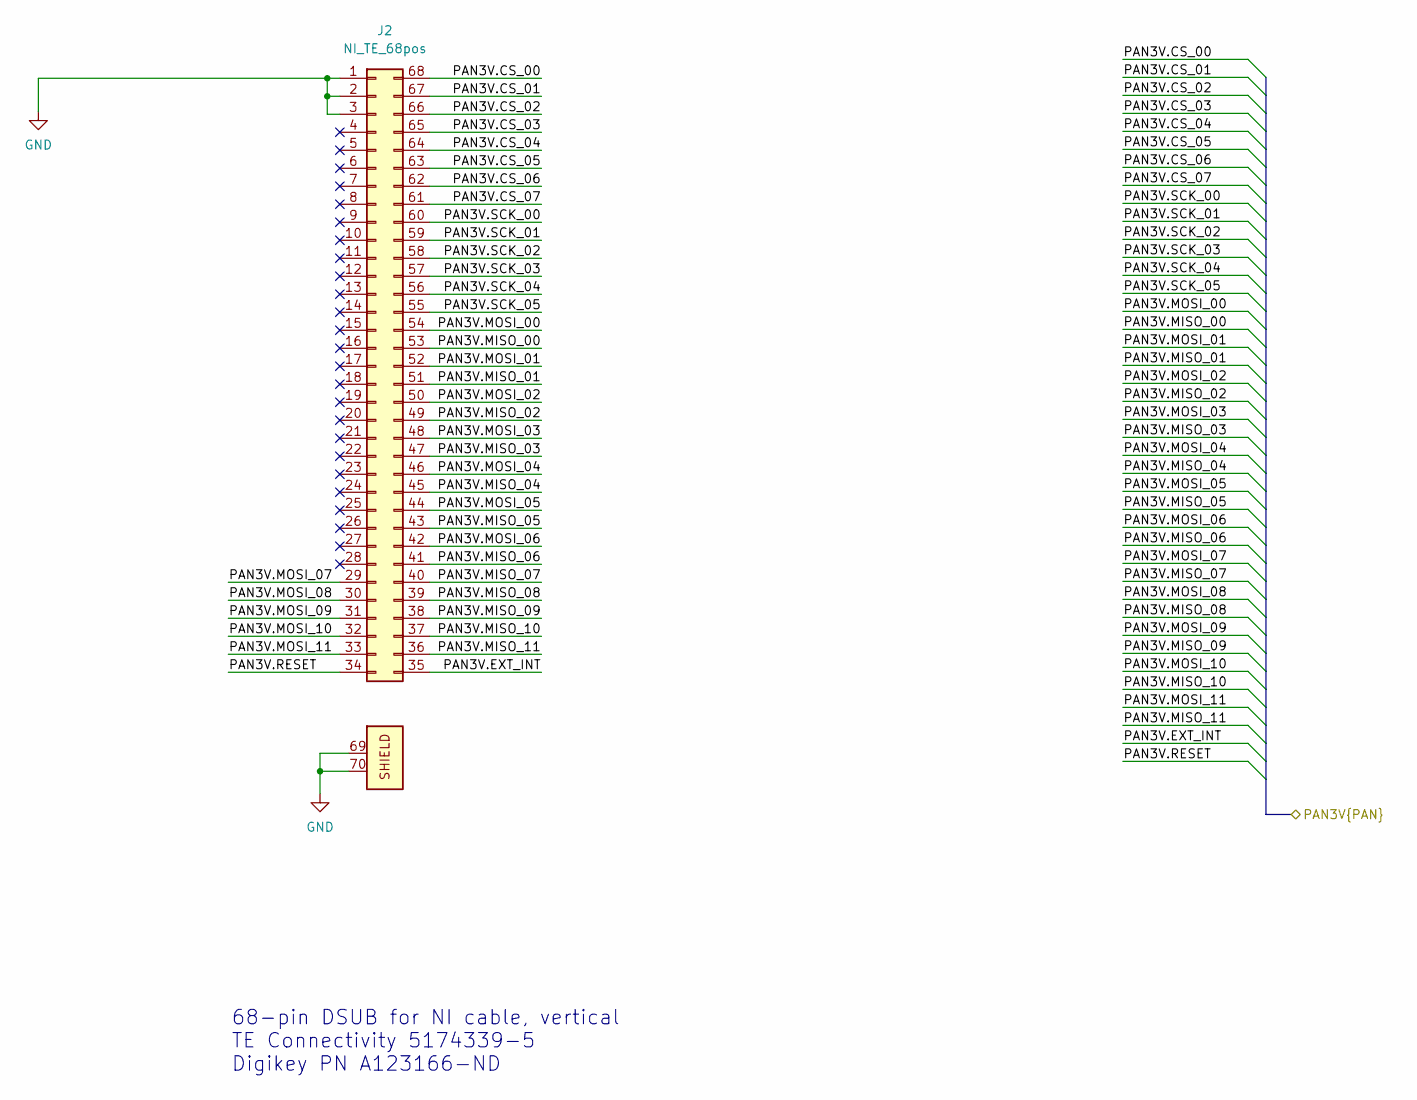
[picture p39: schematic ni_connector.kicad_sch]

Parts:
J2: NI_TE_68pos; TE_CONN_DSUB_VERT_68

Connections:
/Level Shifters/PAN3V.CS_00: J2.68; also elsewhere on the board
/Level Shifters/PAN3V.CS_01: J2.67; also elsewhere on the board
/Level Shifters/PAN3V.CS_02: J2.66; also elsewhere on the board
/Level Shifters/PAN3V.CS_03: J2.65; also elsewhere on the board
/Level Shifters/PAN3V.CS_04: J2.64; also elsewhere on the board
/Level Shifters/PAN3V.CS_05: J2.63; also elsewhere on the board
/Level Shifters/PAN3V.CS_06: J2.62; also elsewhere on the board
/Level Shifters/PAN3V.CS_07: J2.61; also elsewhere on the board
/Level Shifters/PAN3V.EXT_INT: J2.35; also elsewhere on the board
/Level Shifters/PAN3V.MISO_00: J2.53; also elsewhere on the board
/Level Shifters/PAN3V.MISO_01: J2.51; also elsewhere on the board
/Level Shifters/PAN3V.MISO_02: J2.49; also elsewhere on the board
/Level Shifters/PAN3V.MISO_03: J2.47; also elsewhere on the board
/Level Shifters/PAN3V.MISO_04: J2.45; also elsewhere on the board
/Level Shifters/PAN3V.MISO_05: J2.43; also elsewhere on the board
/Level Shifters/PAN3V.MISO_06: J2.41; also elsewhere on the board
/Level Shifters/PAN3V.MISO_07: J2.40; also elsewhere on the board
/Level Shifters/PAN3V.MISO_08: J2.39; also elsewhere on the board
/Level Shifters/PAN3V.MISO_09: J2.38; also elsewhere on the board
/Level Shifters/PAN3V.MISO_10: J2.37; also elsewhere on the board
/Level Shifters/PAN3V.MISO_11: J2.36; also elsewhere on the board
/Level Shifters/PAN3V.MOSI_00: J2.54; also elsewhere on the board
/Level Shifters/PAN3V.MOSI_01: J2.52; also elsewhere on the board
/Level Shifters/PAN3V.MOSI_02: J2.50; also elsewhere on the board
/Level Shifters/PAN3V.MOSI_03: J2.48; also elsewhere on the board
/Level Shifters/PAN3V.MOSI_04: J2.46; also elsewhere on the board
/Level Shifters/PAN3V.MOSI_05: J2.44; also elsewhere on the board
/Level Shifters/PAN3V.MOSI_06: J2.42; also elsewhere on the board
/Level Shifters/PAN3V.MOSI_07: J2.29; also elsewhere on the board
/Level Shifters/PAN3V.MOSI_08: J2.30; also elsewhere on the board
/Level Shifters/PAN3V.MOSI_09: J2.31; also elsewhere on the board
/Level Shifters/PAN3V.MOSI_10: J2.32; also elsewhere on the board
/Level Shifters/PAN3V.MOSI_11: J2.33; also elsewhere on the board
/Level Shifters/PAN3V.RESET: J2.34; also elsewhere on the board
/Level Shifters/PAN3V.SCK_00: J2.60; also elsewhere on the board
/Level Shifters/PAN3V.SCK_01: J2.59; also elsewhere on the board
/Level Shifters/PAN3V.SCK_02: J2.58; also elsewhere on the board
/Level Shifters/PAN3V.SCK_03: J2.57; also elsewhere on the board
/Level Shifters/PAN3V.SCK_04: J2.56; also elsewhere on the board
/Level Shifters/PAN3V.SCK_05: J2.55; also elsewhere on the board
GND: J2.1, J2.2, J2.3, J2.69 (GND), J2.70 (GND); also elsewhere on the board

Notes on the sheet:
68-pin DSUB for NI cable, vertical TE Connectivity 5174339-5 Digikey PN A123166-ND

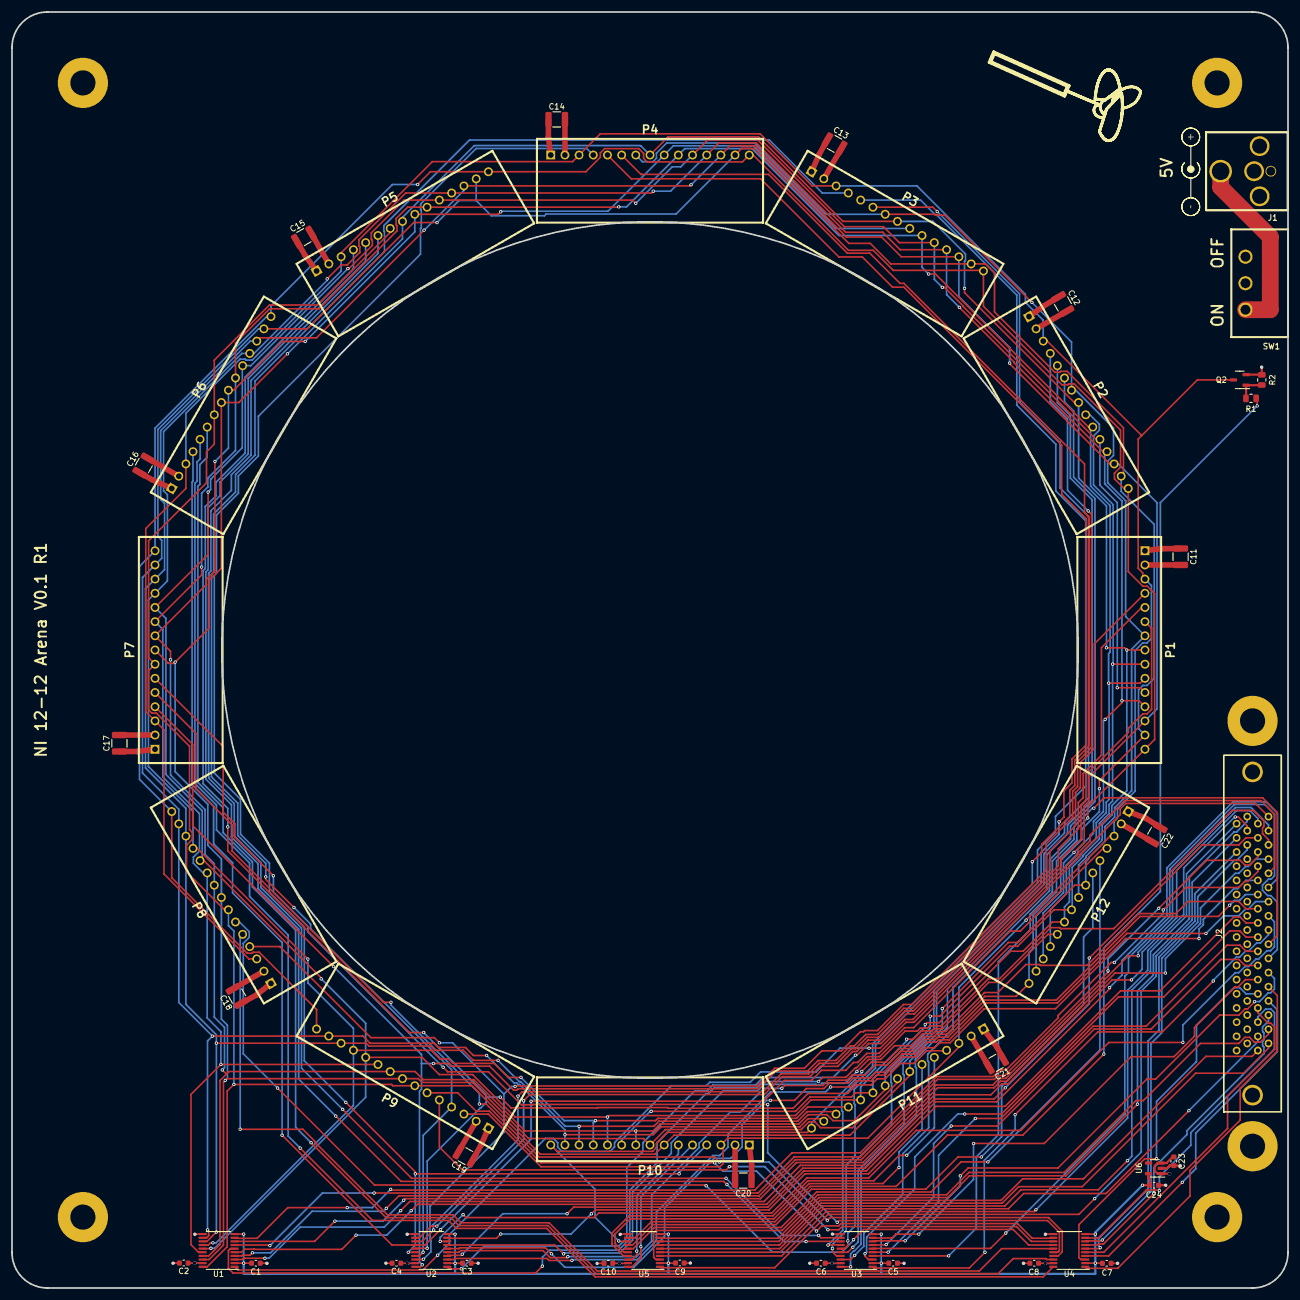
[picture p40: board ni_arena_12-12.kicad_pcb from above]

Board: 4 copper layers, 228.6 x 228.6 mm, 54 parts (0 on the bottom side), 86 nets.

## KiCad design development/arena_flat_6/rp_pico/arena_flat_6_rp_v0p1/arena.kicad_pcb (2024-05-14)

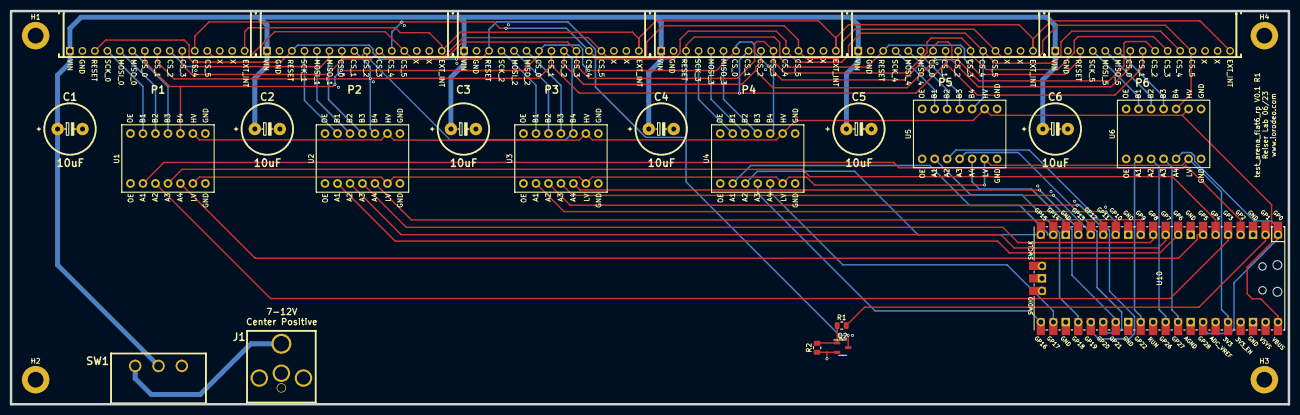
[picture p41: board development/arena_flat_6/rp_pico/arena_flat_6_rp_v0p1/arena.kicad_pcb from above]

Board: 4 copper layers, 260.0 x 80.0 mm, 28 parts (0 on the bottom side), 57 nets.

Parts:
C1, C2, C3, C4, C5, C6: 10uF; Capacitor_Polarized
H1, H2, H3, H4: MountingHole_Pad; MountingHole_3.2mm_M3_DIN965_Pad
J1: Barrel_Jack; DCJACK_2PIN_HIGHCURRENT
P1, P2, P3, P4, P5, P6: CONN15; HEADER_TOP
Q2: MOSFET_NCHAN; SOT-23-3
R1: 200; R_0805_2012Metric
R2: 20k; R_0805_2012Metric
SW1: SW_SPDT; slide_switch
U1, U2, U3, U4, U5, U6: SPARKFUN_TXB0104
U10: Pico; RPi_Pico_SMD_TH

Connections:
/3V3: U1.6 (LV), U2.6 (LV), U3.6 (LV), U4.6 (LV), U5.6 (LV), U6.6 (LV), U10.36 (3V3)
/5V: U1.9 (HV), U2.9 (HV), U3.9 (HV), U4.9 (HV), U5.9 (HV), U6.9 (HV), U10.40 (VBUS)
/CS_0_3V3: U1.5 (A4), U10.7 (GPIO5)
/CS_0_5V: P1.7, P2.7, P3.7, P4.7, P5.7, P6.7, U1.10 (B4)
/CS_1_3V3: U2.5 (A4), U10.12 (GPIO9)
/CS_1_5V: P1.8, P2.8, P3.8, P4.8, P5.8, P6.8, U2.10 (B4)
/CS_2_3V3: U3.5 (A4), U10.17 (GPIO13)
/CS_2_5V: P1.9, P2.9, P3.9, P4.9, P5.9, P6.9, U3.10 (B4)
/CS_3_3V3: U4.5 (A4), U10.22 (GPIO17)
/CS_3_5V: P1.10, P2.10, P3.10, P4.10, P5.10, P6.10, U4.10 (B4)
/CS_4_3V3: U5.5 (A4), U10.27 (GPIO21)
/CS_4_5V: P1.11, P2.11, P3.11, P4.11, P5.11, P6.11, U5.10 (B4)
/CS_5_3V3: U6.5 (A4), U10.1 (GPIO0), U10.34 (GPIO28_ADC2)
/CS_5_5V: P1.12, P2.12, P3.12, P4.12, P5.12, P6.12, U6.10 (B4)
/EXT_INT_5V: P1.15, P2.15, P3.15, P4.15, P5.15, P6.15
/MISO_0_3V3: U1.4 (A3), U10.6 (GPIO4)
/MISO_0_5V: P1.6, U1.11 (B3)
/MISO_1_3V3: U2.4 (A3), U10.11 (GPIO8)
/MISO_1_5V: P2.6, U2.11 (B3)
/MISO_2_3V3: U3.4 (A3), U10.16 (GPIO12)
/MISO_2_5V: P3.6, U3.11 (B3)
/MISO_3_3V3: U4.4 (A3), U10.21 (GPIO16)
/MISO_3_5V: P4.6, U4.11 (B3)
/MISO_4_3V3: U5.4 (A3), U10.26 (GPIO20)
/MISO_4_5V: P5.6, U5.11 (B3)
/MISO_5_3V3: U6.4 (A3), U10.32 (GPIO27_ADC1)
/MISO_5_5V: P6.6, U6.11 (B3)
/MOSI_0_3V3: U1.3 (A2), U10.5 (GPIO3)
/MOSI_0_5V: P1.5, U1.12 (B2)
/MOSI_1_3V3: U2.3 (A2), U10.10 (GPIO7)
/MOSI_1_5V: P2.5, U2.12 (B2)
/MOSI_2_3V3: U3.3 (A2), U10.15 (GPIO11)
/MOSI_2_5V: P3.5, U3.12 (B2)
/MOSI_3_3V3: U4.3 (A2), U10.20 (GPIO15)
/MOSI_3_5V: P4.5, U4.12 (B2)
/MOSI_4_3V3: U5.3 (A2), U10.25 (GPIO19)
/MOSI_4_5V: P5.5, U5.12 (B2)
/MOSI_5_3V3: U6.3 (A2), U10.31 (GPIO26_ADC0)
/MOSI_5_5V: P6.5, U6.12 (B2)
/RESET: R1.2, U10.2 (GPIO1)
/RESET_PAN: P1.3, P2.3, P3.3, P4.3, P5.3, P6.3, Q2.3 (D)
/SCK_0_3V3: U1.2 (A1), U10.4 (GPIO2)
/SCK_0_5V: P1.4, U1.13 (B1)
/SCK_1_3V3: U2.2 (A1), U10.9 (GPIO6)
/SCK_1_5V: P2.4, U2.13 (B1)
/SCK_2_3V3: U3.2 (A1), U10.14 (GPIO10)
/SCK_2_5V: P3.4, U3.13 (B1)
/SCK_3_3V3: U4.2 (A1), U10.19 (GPIO14)
/SCK_3_5V: P4.4, U4.13 (B1)
/SCK_4_3V3: U5.2 (A1), U10.24 (GPIO18)
/SCK_4_5V: P5.4, U5.13 (B1)
/SCK_5_3V3: U6.2 (A1), U10.29 (GPIO22)
/SCK_5_5V: P6.4, U6.13 (B1)
/VIN: C1.1, C2.1, C3.1, C4.1, C5.1, C6.1, P1.1, P2.1, P3.1, P4.1, P5.1, P6.1, SW1.2 (B)
/VIN_SW: J1.1, SW1.1 (A)
GND: C1.2, C2.2, C3.2, C4.2, C5.2, C6.2, H1.1, H2.1, H3.1, H4.1, J1.2, P1.2, P2.2, P3.2, P4.2, P5.2, P6.2, Q2.2 (S), R2.1, SW1.3 (C), U1.7 (GND), U1.8 (GND), U2.7 (GND), U2.8 (GND), U3.7 (GND), U3.8 (GND), U4.7 (GND), U4.8 (GND), U5.7 (GND), U5.8 (GND), U6.7 (GND), U6.8 (GND), U10.3 (GND), U10.8 (GND), U10.13 (GND), U10.18 (GND), U10.23 (GND), U10.28 (GND), U10.33 (AGND), U10.38 (GND), U10.42 (GND)
unnamed: Q2.1 (G), R1.1, R2.2

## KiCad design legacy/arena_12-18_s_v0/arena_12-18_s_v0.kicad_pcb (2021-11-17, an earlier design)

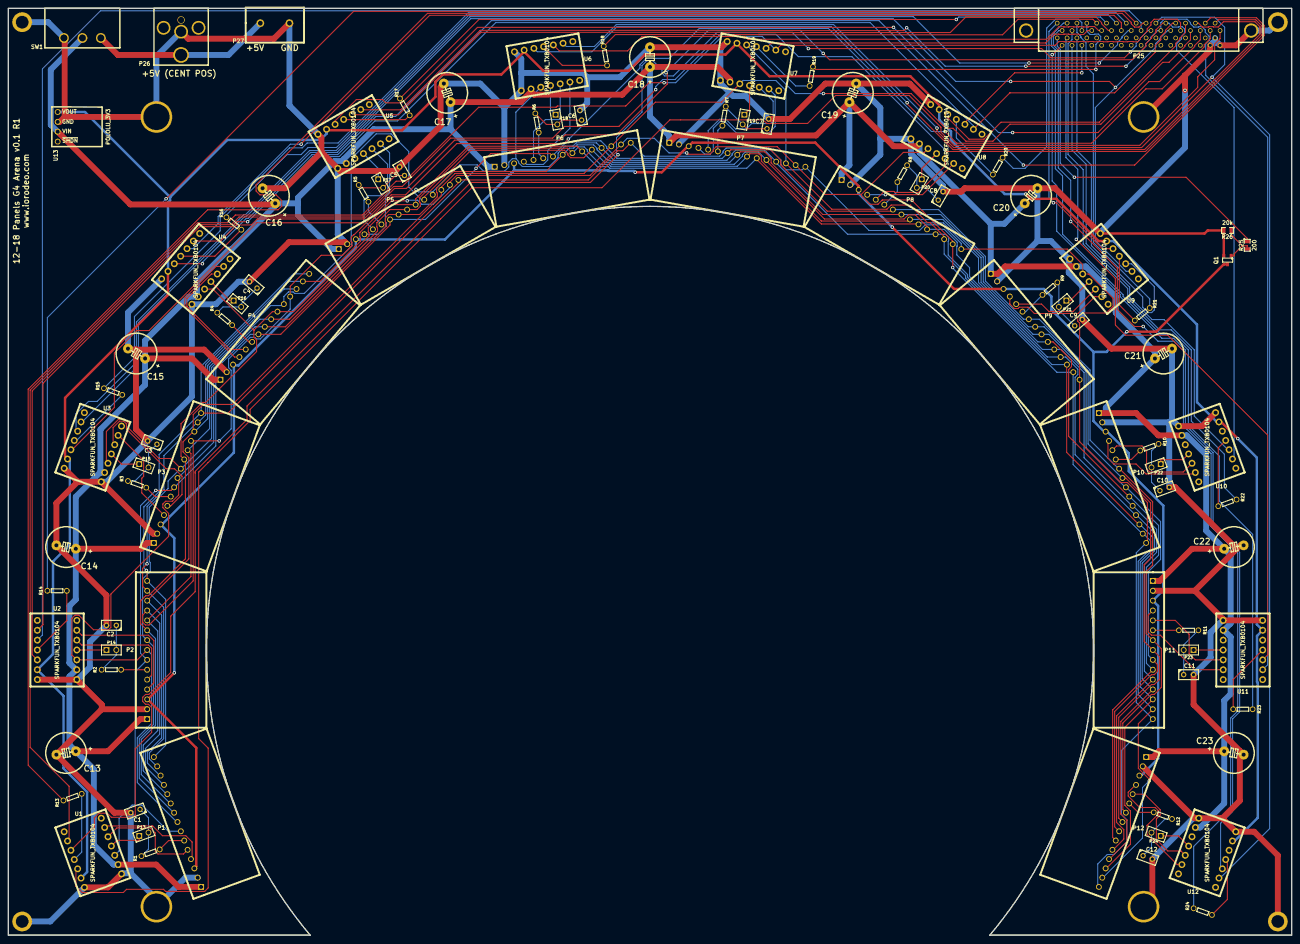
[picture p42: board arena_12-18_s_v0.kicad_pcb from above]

Board: 2 copper layers, 330.2 x 238.5 mm, 99 parts (0 on the bottom side), 127 nets.

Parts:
C1, C2, C3, C4, C5, C6, C7, C8, C9, C10, C11, C12: C; C1
C13, C14, C15, C16, C17, C19, C20, C21, C22, C23: 10uF; Capacitor_Polarized
C18: 10uf; Capacitor_Polarized
P1, P2, P3, P4, P5, P6, P7, P8, P9, P10, P11, P12: CONN15; PANEL_G4
P13, P14, P15, P16, P17, P18, P19, P20, P21, P22, P23, P24: CONN_2; PIN_ARRAY_2X1
P25: CONN_34X2; TE_CONN_DSUB_RA_68
P26: CONN_2; DCJACK_2PIN_HIGHCURRENT
P27: CONN_2; TERM_7P5MM
P28, P29, P30, P31: CONN_1; 0P25_MOUNT_HOLE
P32, P33, P34, P35: CONN_1; #4_THROUGH_HOLE
Q1: MOSFET_NCHAN; SOT23
R1, R2, R3, R4, R5, R6, R7, R8, R9, R10, R11, R12, R13, R14, R15, R16, R17, R18, R19, R20, R21, R22, R23, R24: R; R_SMALL
R25: 200; SM0805
R26: 20k; SM0805
SW1: SWITCH_INV; slide_switch
U1, U2, U3, U4, U5, U6, U7, U8, U9, U10, U11, U12: SPARKFUN_TXB0104
U13: POLOLU_3V3

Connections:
+5V: P26.1, P27.1, SW1.1
/3V3: U1.6, U2.6, U3.6, U4.6, U5.6, U6.6, U7.6, U8.6, U9.6, U10.6, U11.6, U12.6, U13.4
/5V: C13.1, C14.1, C15.1, C16.1, C17.1, C18.1, C19.1, C20.1, C21.1, C22.1, C23.1, P1.1, P2.1, P3.1, P4.1, P5.1, P6.1, P7.1, P8.1, P9.1, P10.1, P11.1, P12.1, SW1.2, U1.9, U2.9, U3.9, U4.9, U5.9, U6.9, U7.9, U8.9, U9.9, U10.9, U11.9, U12.9, U13.2
/CS_0_3V3: P25.35, U1.5
/CS_0_5V: P1.7, P2.7, P3.7, P4.7, P5.7, P6.7, P7.7, P8.7, P9.7, P10.7, P11.7, P12.7, U1.10
/CS_1_3V3: P25.36, U2.5
/CS_1_5V: P1.8, P2.8, P3.8, P4.8, P5.8, P6.8, P7.8, P8.8, P9.8, P10.8, P11.8, P12.8, U2.10
/CS_2_3V3: P25.37, U3.5
/CS_2_5V: P1.9, P2.9, P3.9, P4.9, P5.9, P6.9, P7.9, P8.9, P9.9, P10.9, P11.9, P12.9, U3.10
/CS_3_3V3: P25.38, U4.5
/CS_3_5V: P1.10, P2.10, P3.10, P4.10, P5.10, P6.10, P7.10, P8.10, P9.10, P10.10, P11.10, P12.10, U4.10
/CS_4_3V3: P25.39, U5.5
/CS_4_5V: P1.11, P2.11, P3.11, P4.11, P5.11, P6.11, P7.11, P8.11, P9.11, P10.11, P11.11, P12.11, U5.10
/CS_5_3V3: P25.40, U6.5
/CS_5_5V: P1.12, P2.12, P3.12, P4.12, P5.12, P6.12, P7.12, P8.12, P9.12, P10.12, P11.12, P12.12, U6.10
/CS_6_3V3: P25.41, U7.5
/CS_6_5V: P1.13, P2.13, P3.13, P4.13, P5.13, P6.13, P7.13, P8.13, P9.13, P10.13, P11.13, P12.13, U7.10
/CS_7_3V3: P25.42, U8.5
/CS_7_5V: P1.14, P2.14, P3.14, P4.14, P5.14, P6.14, P7.14, P8.14, P9.14, P10.14, P11.14, P12.14, U8.10
/EXT_INT_3V3: P25.68, U9.5
/EXT_INT_5V: P1.15, P2.15, P3.15, P4.15, P5.15, P6.15, P7.15, P8.15, P9.15, P10.15, P11.15, P12.15, U9.10
/MISO_0_3V3: P25.50, R13.2
/MISO_0_5V: P1.6, R1.1
/MISO_1_3V3: P25.52, R14.2
/MISO_1_5V: P2.6, R2.1
/MISO_2_3V3: P25.54, R15.2
/MISO_2_5V: P3.6, R3.1
/MISO_3_3V3: P25.56, R16.2
/MISO_3_5V: P4.6, R4.1
/MISO_4_3V3: P25.58, R17.2
/MISO_4_5V: P5.6, R5.1
/MISO_5_3V3: P25.60, R18.2
/MISO_5_5V: P6.6, R6.1
/MISO_6_3V3: P25.62, R19.2
/MISO_6_5V: P7.6, R7.1
/MISO_7_3V3: P25.63, R20.2
/MISO_7_5V: P8.6, R8.1
/MISO_8_3V3: P25.64, R21.2
/MISO_8_5V: P9.6, R9.1
/MISO_9_3V3: P25.65, R22.2
/MISO_9_5V: P10.6, R10.1
/MISO_10_3V3: P25.66, R23.2
/MISO_10_5V: P11.6, R11.1
/MISO_11_3V3: P25.67, R24.2
/MISO_11_5V: P12.6, R12.1
/MOSI_0_3V3: P25.49, U1.3
/MOSI_0_5V: P1.5, U1.12
/MOSI_1_3V3: P25.51, U2.3
/MOSI_1_5V: P2.5, U2.12
/MOSI_2_3V3: P25.53, U3.3
/MOSI_2_5V: P3.5, U3.12
/MOSI_3_3V3: P25.55, U4.3
/MOSI_3_5V: P4.5, U4.12
/MOSI_4_3V3: P25.57, U5.3
/MOSI_4_5V: P5.5, U5.12
/MOSI_5_3V3: P25.59, U6.3
/MOSI_5_5V: P6.5, U6.12
/MOSI_6_3V3: P25.61, U7.3
/MOSI_6_5V: P7.5, U7.12
/MOSI_7_3V3: P25.29, U8.3
/MOSI_7_5V: P8.5, U8.12
/MOSI_8_3V3: P25.30, U9.3
/MOSI_8_5V: P9.5, U9.12
/MOSI_9_3V3: P25.31, U10.3
/MOSI_9_5V: P10.5, U10.12
/MOSI_10_3V3: P25.32, U11.3
/MOSI_10_5V: P11.5, U11.12
/MOSI_11_3V3: P25.33, U12.3
/MOSI_11_5V: P12.5, U12.12
/RESET: P25.34, R25.1
/RESET_PAN: P1.3, P2.3, P3.3, P4.3, P5.3, P6.3, P7.3, P8.3, P9.3, P10.3, P11.3, P12.3, Q1.3
/SCK_0_3V3: P25.43, U1.2, U7.2
/SCK_0_5V: P1.4, U1.13
/SCK_1_3V3: P25.44, U2.2, U8.2
/SCK_1_5V: P2.4, U2.13
/SCK_2_3V3: P25.45, U3.2, U9.2
/SCK_2_5V: P3.4, U3.13
/SCK_3_3V3: P25.46, U4.2, U10.2
/SCK_3_5V: P4.4, U4.13
/SCK_4_3V3: P25.47, U5.2, U11.2
/SCK_4_5V: P5.4, U5.13
/SCK_5_3V3: P25.48, U6.2, U12.2
/SCK_5_5V: P6.4, U6.13
/SCK_6_5V: P7.4, U7.13
/SCK_7_5V: P8.4, U8.13
/SCK_8_5V: P9.4, U9.13
/SCK_9_5V: P10.4, U10.13
/SCK_10_5V: P11.4, U11.13
/SCK_11_5V: P12.4, U12.13
GND: C1.2, C2.2, C3.2, C4.2, C5.2, C6.2, C7.2, C8.2, C9.2, C10.2, C11.2, C12.2, C13.2, C14.2, C15.2, C16.2, C17.2, C18.2, C19.2, C20.2, C21.2, C22.2, C23.2, P1.2, P2.2, P3.2, P4.2, P5.2, P6.2, P7.2, P8.2, P9.2, P10.2, P11.2, P12.2, P25.1, P25.2, P25.3, P25.69, P26.2, P27.2, P28.1, P29.1, P30.1, P31.1, P32.1, P33.1, P34.1, P35.1, Q1.2, R26.2, SW1.3, U1.7, U1.8, U2.7, U2.8, U3.7, U3.8, U4.7, U4.8, U5.7, U5.8, U6.7, U6.8, U7.7, U7.8, U8.7, U8.8, U9.7, U9.8, U10.7, U10.8, U11.7, U11.8, U12.7, U12.8, U13.3
unnamed: R21.1, U9.4
unnamed: R22.1, U10.4
unnamed: R19.1, U7.4
unnamed: R18.1, U6.4
unnamed: R20.1, U8.4
unnamed: C12.1, P24.2, R12.2
unnamed: C11.1, P23.2, R11.2
unnamed: P22.1, U10.11
unnamed: P21.1, U9.11
unnamed: P20.1, U8.11
unnamed: P19.1, U7.11
unnamed: P18.1, U6.11
unnamed: P17.1, U5.11
unnamed: C10.1, P22.2, R10.2
unnamed: P16.1, U4.11
unnamed: P15.1, U3.11
unnamed: P14.1, U2.11
unnamed: P13.1, U1.11
unnamed: C7.1, P19.2, R7.2
unnamed: C6.1, P18.2, R6.2
unnamed: C5.1, P17.2, R5.2
unnamed: C9.1, P21.2, R9.2
unnamed: P23.1, U11.11
unnamed: C8.1, P20.2, R8.2
unnamed: P24.1, U12.11
unnamed: R23.1, U11.4
unnamed: C2.1, P14.2, R2.2
unnamed: C1.1, P13.2, R1.2
unnamed: C4.1, P16.2, R4.2
unnamed: C3.1, P15.2, R3.2
unnamed: R24.1, U12.4
unnamed: R15.1, U3.4
unnamed: R14.1, U2.4
unnamed: R16.1, U4.4
unnamed: R17.1, U5.4
unnamed: R13.1, U1.4
unnamed: Q1.1, R25.2, R26.1

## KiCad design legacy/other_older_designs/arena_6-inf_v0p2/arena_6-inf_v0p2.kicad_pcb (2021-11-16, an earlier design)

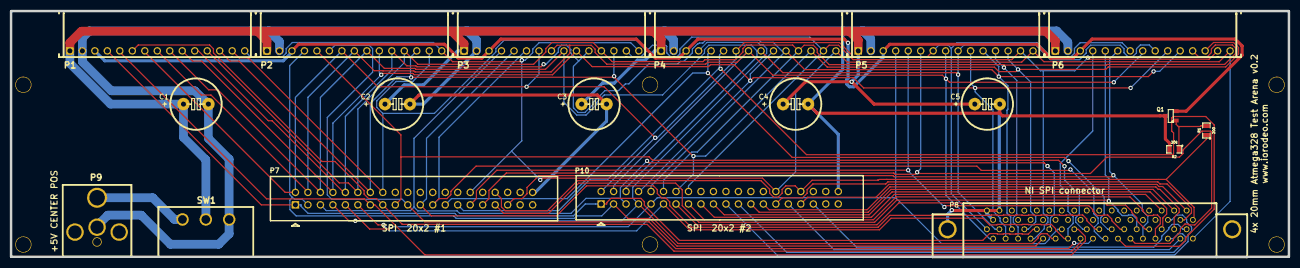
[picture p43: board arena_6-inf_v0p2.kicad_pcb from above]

Board: 2 copper layers, 260.0 x 50.0 mm, 25 parts (0 on the bottom side), 45 nets.

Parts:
C1, C2, C3, C4, C5: 10uF; Capacitor_Polarized
M1, M2, M3, M4, M5, M6: VAL**; MOUNT_HOLE_4_40
P1, P2, P3, P4, P5, P6: CONN15; HEADER_TOP
P7, P10: CONN_20X2; PIN_ARRAY_SHRD_20X2
P8: CONN_34X2; TE_CONN_DSUB_RA_68
P9: CONN_2; DCJACK_2PIN_HIGHCURRENT
Q1: MOSFET_NCHAN; SOT23
R1: 200; SM0805
R2: 20k; SM0805
SW1: SWITCH_INV; slide_switch

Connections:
+5V: P9.1, SW1.1
/CS0: P1.7, P2.7, P3.7, P4.7, P5.7, P6.7, P7.2, P8.35, P10.2
/CS1: P1.8, P2.8, P3.8, P4.8, P5.8, P6.8, P7.4, P8.36, P10.4
/CS2: P1.9, P2.9, P3.9, P4.9, P5.9, P6.9, P7.6, P8.37, P10.6
/CS3: P1.10, P2.10, P3.10, P4.10, P5.10, P6.10, P7.8, P8.38, P10.8
/CS4: P1.11, P2.11, P3.11, P4.11, P5.11, P6.11, P7.10, P8.39, P10.10
/CS5: P1.12, P2.12, P3.12, P4.12, P5.12, P6.12, P7.12, P8.40, P10.12
/CS6: P1.13, P2.13, P3.13, P4.13, P5.13, P6.13, P7.14, P8.41, P10.14
/CS7: P1.14, P2.14, P3.14, P4.14, P5.14, P6.14, P7.16, P8.42, P10.16
/EXT_INT: P1.15, P2.15, P3.15, P4.15, P5.15, P6.15, P7.30, P8.68, P10.30
/MISO_0: P1.6, P7.15, P8.50
/MISO_1: P2.6, P7.19, P8.52
/MISO_2: P3.6, P7.23, P8.54
/MISO_3: P4.6, P7.27, P8.56
/MISO_4: P5.6, P7.31, P8.58
/MISO_5: P6.6, P7.35, P8.60
/MISO_6: P8.62, P10.15
/MISO_7: P8.63, P10.19
/MISO_8: P8.64, P10.23
/MISO_9: P8.65, P10.27
/MISO_10: P8.66, P10.31
/MISO_11: P8.67, P10.35
/MOSI_0: P1.5, P7.13, P8.49
/MOSI_1: P2.5, P7.17, P8.51
/MOSI_2: P3.5, P7.21, P8.53
/MOSI_3: P4.5, P7.25, P8.55
/MOSI_4: P5.5, P7.29, P8.57
/MOSI_5: P6.5, P7.33, P8.59
/MOSI_6: P8.61, P10.13
/MOSI_7: P8.29, P10.17
/MOSI_8: P8.30, P10.21
/MOSI_9: P8.31, P10.25
/MOSI_10: P8.32, P10.29
/MOSI_11: P8.33, P10.33
/RESET: P7.34, P8.34, P10.34, R1.1
/RESET_PAN: P1.3, P2.3, P3.3, P4.3, P5.3, P6.3, Q1.2
/SCK_0: P1.4, P7.1, P8.43, P10.1
/SCK_1: P2.4, P7.3, P8.44, P10.3
/SCK_2: P3.4, P7.5, P8.45, P10.5
/SCK_3: P4.4, P7.7, P8.46, P10.7
/SCK_4: P5.4, P7.9, P8.47, P10.9
/SCK_5: P6.4, P7.11, P8.48, P10.11
/VIN: C1.1, C2.1, C3.1, C4.1, C5.1, P1.1, P2.1, P3.1, P4.1, P5.1, P6.1, SW1.2
GND: C1.2, C2.2, C3.2, C4.2, C5.2, P1.2, P2.2, P3.2, P4.2, P5.2, P6.2, P7.40, P8.1, P8.2, P8.3, P8.69, P9.2, P10.40, Q1.3, R2.2, SW1.3
unnamed: Q1.1, R1.2, R2.1

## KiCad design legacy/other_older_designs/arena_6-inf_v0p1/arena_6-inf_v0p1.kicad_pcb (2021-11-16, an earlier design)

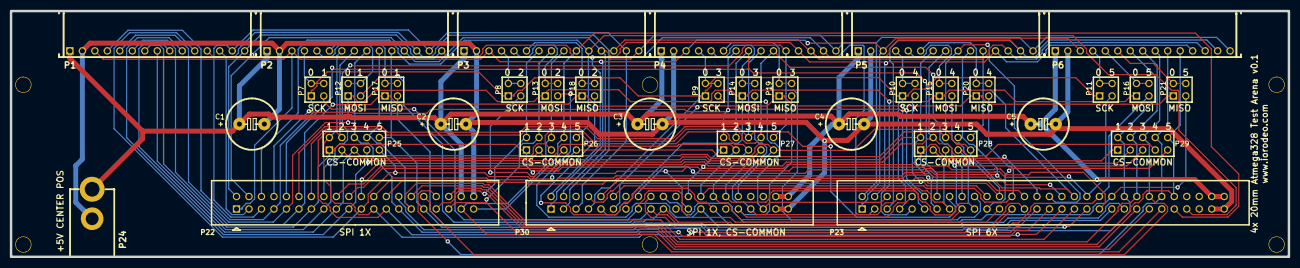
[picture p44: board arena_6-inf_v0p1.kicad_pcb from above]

Board: 2 copper layers, 260.0 x 50.0 mm, 41 parts (0 on the bottom side), 70 nets.

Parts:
C1, C2, C3, C4, C5: 10uF; Capacitor_Polarized
M1, M2, M3, M4, M5, M6: VAL**; MOUNT_HOLE_4_40
P1, P2, P3, P4, P5, P6: CONN15; HEADER_TOP
P7, P8, P9, P10, P11, P12, P13, P14, P15, P16, P17, P18, P19, P20, P21: CONN_2X2; PIN_ARRAY_2X2
P22, P30: CONN_20X2; PIN_ARRAY_SHRD_20X2
P23: CONN_30X2; PIN_ARRAY_SHRD_30X2
P24: CONN_2; DCJACK_2PIN
P25, P26, P27, P28, P29: CONN_5X2; PIN_ARRAY_5x2

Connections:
+5V: C1.1, C2.1, C3.1, C4.1, C5.1, P1.1, P2.1, P3.1, P4.1, P5.1, P6.1, P22.38, P23.58, P23.60, P24.1, P30.38, P30.40
/CS1_0: P1.7, P22.13, P23.13, P25.1, P26.1, P27.1, P28.1, P29.1, P30.24
/CS1_1: P2.7, P22.23, P23.29, P25.2
/CS1_2: P3.7, P22.33, P23.45, P26.2
/CS1_3: P4.7, P22.8, P23.12, P27.2
/CS1_4: P5.7, P22.18, P23.28, P28.2
/CS1_5: P6.7, P22.28, P23.44, P29.2
/CS2_0: P1.8, P22.15, P23.15, P25.3, P26.3, P27.3, P28.3, P29.3, P30.26
/CS2_1: P2.8, P22.25, P23.31, P25.4
/CS2_2: P3.8, P22.35, P23.47, P26.4
/CS2_3: P4.8, P22.10, P23.14, P27.4
/CS2_4: P5.8, P22.20, P23.30, P28.4
/CS2_5: P6.8, P22.30, P23.46, P29.4
/CS3_0: P1.9, P22.17, P23.17, P25.5, P26.5, P27.5, P28.5, P29.5, P30.28
/CS3_1: P2.9, P22.27, P23.33, P25.6
/CS3_2: P3.9, P22.37, P23.49, P26.6
/CS3_3: P4.9, P22.12, P23.16, P27.6
/CS3_4: P5.9, P22.22, P23.32, P28.6
/CS3_5: P6.9, P22.32, P23.48, P29.6
/CS4_0: P1.10, P22.19, P23.19, P25.7, P26.7, P27.7, P28.7, P29.7, P30.30
/CS4_1: P2.10, P22.29, P23.35, P25.8
/CS4_2: P3.10, P22.39, P23.51, P26.8
/CS4_3: P4.10, P22.14, P23.18, P27.8
/CS4_4: P5.10, P22.24, P23.34, P28.8
/CS4_5: P6.10, P22.34, P23.50, P29.8
/CS5_0: P1.11, P22.21, P23.21, P25.9, P26.9, P27.9, P28.9, P29.9, P30.32
/CS5_1: P2.11, P22.31, P23.37, P25.10
/CS5_2: P3.11, P22.6, P23.53, P26.10
/CS5_3: P4.11, P22.16, P23.20, P27.10
/CS5_4: P5.11, P22.26, P23.36, P28.10
/CS5_5: P6.11, P22.36, P23.52, P29.10
/EXT_INT0: P1.15, P2.15, P3.15, P4.15, P5.15, P6.15, P22.2, P23.2, P30.2
/EXT_INT1: P1.12, P2.12, P3.12, P4.12, P5.12, P6.12, P22.4, P23.4, P30.4
/MISO_0: P1.6, P17.1, P18.1, P19.1, P20.1, P21.1, P22.11, P23.11, P30.11
/MISO_1: P17.3, P23.27, P30.19
/MISO_2: P18.3, P23.43, P30.27
/MISO_3: P19.3, P23.10, P30.31
/MISO_4: P20.3, P23.26, P30.12
/MISO_5: P21.3, P23.42, P30.20
/MISO_11: P2.6, P17.2, P17.4
/MISO_22: P3.6, P18.2, P18.4
/MISO_33: P4.6, P19.2, P19.4
/MISO_44: P5.6, P20.2, P20.4
/MISO_55: P6.6, P21.2, P21.4
/MOSI_0: P1.5, P12.1, P13.1, P14.1, P15.1, P16.1, P22.9, P23.9, P30.9
/MOSI_1: P12.3, P23.25, P30.17
/MOSI_2: P13.3, P23.41, P30.25
/MOSI_3: P14.3, P23.8, P30.33
/MOSI_4: P15.3, P23.24, P30.10
/MOSI_5: P16.3, P23.40, P30.18
/MOSI_11: P2.5, P12.2, P12.4
/MOSI_22: P3.5, P13.2, P13.4
/MOSI_33: P4.5, P14.2, P14.4
/MOSI_44: P5.5, P15.2, P15.4
/MOSI_55: P6.5, P16.2, P16.4
/RESET_MSTR: P1.3, P2.3, P3.3, P4.3, P5.3, P6.3, P22.1, P23.1, P30.1
/RX: P1.13, P2.13, P3.13, P4.13, P5.13, P6.13, P22.3, P23.3, P30.3
/SCK_0: P1.4, P7.1, P8.1, P9.1, P10.1, P11.1, P22.7, P23.7, P30.7
/SCK_1: P7.3, P23.23, P30.15
/SCK_2: P8.3, P23.39, P30.23
/SCK_3: P9.3, P23.6, P30.35
/SCK_4: P10.3, P23.22, P30.8
/SCK_5: P11.3, P23.38, P30.16
/SCK_11: P2.4, P7.2, P7.4
/SCK_22: P3.4, P8.2, P8.4
/SCK_33: P4.4, P9.2, P9.4
/SCK_44: P5.4, P10.2, P10.4
/SCK_55: P6.4, P11.2, P11.4
/TX: P1.14, P2.14, P3.14, P4.14, P5.14, P6.14, P22.5, P23.5, P30.5
GND: C1.2, C2.2, C3.2, C4.2, C5.2, P1.2, P2.2, P3.2, P4.2, P5.2, P6.2, P22.40, P23.57, P23.59, P24.2, P30.37, P30.39

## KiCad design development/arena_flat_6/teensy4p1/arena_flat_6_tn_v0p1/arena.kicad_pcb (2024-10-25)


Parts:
C1, C2, C3, C4, C5, C6: C_Polarized_Small; Capacitor_Polarized
H1, H2, H3, H4: MountingHole_Pad; MountingHole_3.2mm_M3_DIN965_Pad
J1: Barrel_Jack; DCJACK_2PIN_HIGHCURRENT
J2, J3: Conn_01x04_Pin; NS-Tech_Grove_1x04_P2mm_Horizontal
P1, P2, P3, P4, P5, P6: CONN15; HEADER_TOP
Q2: MOSFET_NCHAN; SOT-23-3
R1: 200; R_0805_2012Metric
R2: 20k; R_0805_2012Metric
SW1: SW_SPDT; slide_switch
U1, U2, U3, U4, U5, U6: SPARKFUN_TXB0104
U7: Teensy4.1; Teensy41

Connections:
/3V3: J2.2, J3.2, U1.6 (LV), U2.6 (LV), U3.6 (LV), U4.6 (LV), U5.6 (LV), U6.6 (LV), U7.15 (3V3), U7.46 (3V3)
/5V: U1.9 (HV), U2.9 (HV), U3.9 (HV), U4.9 (HV), U5.9 (HV), U6.9 (HV), U7.48 (VIN), U7.49 (VUSB)
/A0: J3.3, U7.36 (14_A0_TX3_SPDIF_OUT)
/A1: J3.4, U7.37 (15_A1_RX3_SPDIF_IN)
/CS_00_3V3: U3.2 (A1), U7.5 (3_LRCLK2)
/CS_00_5V: P1.7, P4.7, U3.13 (B1)
/CS_01_3V3: U3.3 (A2), U7.6 (4_BCLK2)
/CS_01_5V: P1.8, P4.8, U3.12 (B2)
/CS_02_3V3: U3.4 (A3), U7.7 (5_IN2)
/CS_02_5V: P1.9, P4.9, U3.11 (B3)
/CS_03_3V3: U3.5 (A4), U7.8 (6_OUT1D)
/CS_03_5V: P1.10, P4.10, U3.10 (B4)
/CS_04_3V3: U4.2 (A1), U7.9 (7_RX2_OUT1A)
/CS_04_5V: P1.11, P4.11, U4.13 (B1)
/CS_05_3V3: U4.3 (A2), U7.10 (8_TX2_IN1)
/CS_05_5V: P2.7, P5.7, U4.12 (B2)
/CS_06_3V3: U4.4 (A3), U7.11 (9_OUT1C)
/CS_06_5V: P2.8, P5.8, U4.11 (B3)
/CS_07_3V3: U4.5 (A4), U7.21 (29_TX7)
/CS_07_5V: P2.9, P5.9, U4.10 (B4)
/CS_08_3V3: U5.2 (A1), U7.22 (30_CRX3)
/CS_08_5V: P2.10, P5.10, U5.13 (B1)
/CS_09_3V3: U5.3 (A2), U7.23 (31_CTX3)
/CS_09_5V: P2.11, P5.11, U5.12 (B2)
/CS_10_3V3: U5.4 (A3), U7.24 (32_OUT1B)
/CS_10_5V: P3.7, P6.7, U5.11 (B3)
/CS_11_3V3: U5.5 (A4), U7.25 (33_MCLK2)
/CS_11_5V: P3.8, P6.8, U5.10 (B4)
/CS_12_3V3: U6.2 (A1), U7.26 (34_RX8)
/CS_12_5V: P3.9, P6.9, U6.13 (B1)
/CS_13_3V3: U6.3 (A2), U7.27 (35_TX8)
/CS_13_5V: P3.10, P6.10, U6.12 (B2)
/CS_14_3V3: U6.4 (A3), U7.28 (36_CS)
/CS_14_5V: P3.11, P6.11, U6.11 (B3)
/EXT_INT_5V: P1.15, P2.15, P3.15, P4.15, P5.15, P6.15
/MISO_0_3V3: U1.4 (A3), U7.14 (12_MISO_MQSL)
/MISO_0_5V: P1.6, P2.6, P3.6, U1.11 (B3)
/MISO_1_3V3: U2.4 (A3), U7.3 (1_TX1_CTX2_MISO1)
/MISO_1_5V: P4.6, P5.6, P6.6, U2.11 (B3)
/MOSI_0_3V3: U1.3 (A2), U7.13 (11_MOSI_CTX1)
/MOSI_0_5V: P1.5, P2.5, P3.5, U1.12 (B2)
/MOSI_1_3V3: U2.3 (A2), U7.18 (26_A12_MOSI1)
/MOSI_1_5V: P4.5, P5.5, P6.5, U2.12 (B2)
/RESET: R1.2, U7.29 (37_CS)
/RESET_PAN: P1.3, P2.3, P3.3, P4.3, P5.3, P6.3, Q2.3 (D)
/SCK_0_3V3: U1.2 (A1), U7.35 (13_SCK_LED)
/SCK_0_5V: P1.4, P2.4, P3.4, U1.13 (B1)
/SCK_1_3V3: U2.2 (A1), U7.19 (27_A13_SCK1)
/SCK_1_5V: P4.4, P5.4, P6.4, U2.13 (B1)
/SCL: J2.4, U7.41 (19_A5_SCL)
/SDA: J2.3, U7.40 (18_A4_SDA)
/VIN: C1.1, C2.1, C3.1, C4.1, C5.1, C6.1, P1.1, P2.1, P3.1, P4.1, P5.1, P6.1, SW1.2 (B)
/VIN_SW: J1.1, SW1.1 (A)
GND: C1.2, C2.2, C3.2, C4.2, C5.2, C6.2, H1.1, H2.1, H3.1, H4.1, J1.2, J2.1, J3.1, P1.2, P2.2, P3.2, P4.2, P5.2, P6.2, Q2.2 (S), R2.1, SW1.3 (C), U1.7 (GND), U1.8 (GND), U2.7 (GND), U2.8 (GND), U3.7 (GND), U3.8 (GND), U4.7 (GND), U4.8 (GND), U5.7 (GND), U5.8 (GND), U6.7 (GND), U6.8 (GND), U7.1 (GND), U7.34 (GND), U7.47 (GND)
unnamed: Q2.1 (G), R1.1, R2.2

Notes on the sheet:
SI2302-TP (Digikey SI2302-TPMSCT-ND)
Analog inputs
Level Shifters
Panel Headers
Power filtering
I2C connections for analog outputs, sensors etc.
7.5V to 9V
Reset Sink


Board: 4 copper layers, 260.0 x 80.0 mm, 30 parts (0 on the bottom side), 55 nets.

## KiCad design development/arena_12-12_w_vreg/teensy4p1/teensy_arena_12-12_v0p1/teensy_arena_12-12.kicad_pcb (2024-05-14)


Board: 4 copper layers, 254.0 x 254.0 mm, 87 parts (0 on the bottom side), 98 nets.

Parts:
C1, C2, C3, C4, C5, C6, C7, C8, C9, C10: 0.1uF; C_0603_1608Metric
C11, C13, C15, C17, C19, C21, C23, C25, C27, C29, C31, C33: 10uF; CP_Elec_4x5.4
C12, C14, C16, C18, C20, C22, C24, C26, C28, C30, C32, C34: 22uF; CP_Elec_4x5.4
H1, H2, H3, H4: MountingHole_Pad; MountingHole_4.5mm_Pad
J1: Barrel_Jack; DCJACK_2PIN_HIGHCURRENT
J2, J3: Conn_01x04; JST_SH_SM04B-SRSS-TB_1x04-1MP_P1.00mm_Horizontal
P1, P2, P3, P4, P5, P6, P7, P8, P9, P10, P11, P12: CONN15; HEADER_TOP
Q2: MOSFET_NCHAN; SOT-23-3
R1: 200; R_0805_2012Metric
R2: 20k; R_0805_2012Metric
R3, R4, R5, R6, R7, R8, R9, R10, R11, R12, R13, R14: 300; R_1206_3216Metric
SW1: SW_SPDT; slide_switch
U1, U2, U3, U4, U5: TXB0108PW; TSSOP-20_4.4x6.5mm_P0.65mm
U6, U7, U8, U9, U10, U11, U12, U13, U14, U15, U16, U17: AZ1084-5.0; TO-252
U18: Teensy4.1; Teensy41

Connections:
+3.3V: C1.1, C3.1, C5.1, C7.1, C9.1, J2.2, J3.2, U1.2 (VCCA), U1.10 (OE), U2.2 (VCCA), U2.10 (OE), U3.2 (VCCA), U3.10 (OE), U4.2 (VCCA), U4.10 (OE), U5.2 (VCCA), U5.10 (OE), U18.15 (3V3), U18.46 (3V3)
+5V: C2.1, C4.1, C6.1, C8.1, C10.1, U1.19 (VCCB), U2.19 (VCCB), U3.19 (VCCB), U4.19 (VCCB), U5.19 (VCCB), U18.48 (VIN), U18.49 (VUSB)
/Level Shifters/PAN3V.CS_00: U2.1 (A1), U18.2 (0_RX1_CRX2_CS1)
/Level Shifters/PAN3V.CS_01: U2.3 (A2), U18.4 (2_OUT2)
/Level Shifters/PAN3V.CS_02: U2.4 (A3), U18.5 (3_LRCLK2)
/Level Shifters/PAN3V.CS_03: U2.5 (A4), U18.6 (4_BCLK2)
/Level Shifters/PAN3V.CS_04: U2.6 (A5), U18.7 (5_IN2)
/Level Shifters/PAN3V.CS_05: U2.7 (A6), U18.8 (6_OUT1D)
/Level Shifters/PAN3V.CS_06: U2.8 (A7), U18.9 (7_RX2_OUT1A)
/Level Shifters/PAN3V.CS_07: U2.9 (A8), U18.10 (8_TX2_IN1)
/Level Shifters/PAN3V.CS_08: U3.1 (A1), U18.11 (9_OUT1C)
/Level Shifters/PAN3V.CS_09: U3.3 (A2), U18.12 (10_CS_MQSR)
/Level Shifters/PAN3V.CS_10: U3.4 (A3), U18.16 (24_A10_TX6_SCL2)
/Level Shifters/PAN3V.CS_11: U3.5 (A4), U18.17 (25_A11_RX6_SDA2)
/Level Shifters/PAN3V.CS_12: U3.6 (A5), U18.20 (28_RX7)
/Level Shifters/PAN3V.CS_13: U3.7 (A6), U18.21 (29_TX7)
/Level Shifters/PAN3V.CS_14: U3.8 (A7), U18.22 (30_CRX3)
/Level Shifters/PAN3V.CS_15: U3.9 (A8), U18.23 (31_CTX3)
/Level Shifters/PAN3V.CS_16: U4.1 (A1), U18.24 (32_OUT1B)
/Level Shifters/PAN3V.CS_17: U4.3 (A2), U18.45 (23_A9_CRX1_MCLK1)
/Level Shifters/PAN3V.CS_18: U4.4 (A3), U18.44 (22_A8_CTX1)
/Level Shifters/PAN3V.CS_19: U4.5 (A4), U18.43 (21_A7_RX5_BCLK1)
/Level Shifters/PAN3V.CS_20: U4.6 (A5), U18.42 (20_A6_TX5_LRCLK1)
/Level Shifters/PAN3V.CS_21: U4.7 (A6), U18.39 (17_A3_TX4_SDA1)
/Level Shifters/PAN3V.CS_22: U4.8 (A7), U18.38 (16_A2_RX4_SCL1)
/Level Shifters/PAN3V.CS_23: U4.9 (A8), U18.33 (41_A17)
/Level Shifters/PAN3V.CS_24: U5.1 (A1), U18.32 (40_A16)
/Level Shifters/PAN3V.CS_25: U5.3 (A2), U18.31 (39_MISO1_OUT1A)
/Level Shifters/PAN3V.CS_26: U5.4 (A3), U18.30 (38_CS1_IN1)
/Level Shifters/PAN3V.CS_27: U5.5 (A4), U18.29 (37_CS)
/Level Shifters/PAN3V.CS_28: U5.6 (A5), U18.28 (36_CS)
/Level Shifters/PAN3V.CS_29: U5.7 (A6), U18.27 (35_TX8)
/Level Shifters/PAN3V.EXT_INT: U5.9 (A8), U18.25 (33_MCLK2)
/Level Shifters/PAN3V.MISO_0: U1.5 (A4), U18.14 (12_MISO_MQSL)
/Level Shifters/PAN3V.MISO_1: U1.9 (A8), U18.3 (1_TX1_CTX2_MISO1)
/Level Shifters/PAN3V.MOSI_0: U1.4 (A3), U18.13 (11_MOSI_CTX1)
/Level Shifters/PAN3V.MOSI_1: U1.8 (A7), U18.18 (26_A12_MOSI1)
/Level Shifters/PAN3V.RESET: U1.1 (A1), U18.26 (34_RX8)
/Level Shifters/PAN3V.SCK_0: U1.3 (A2), U18.35 (13_SCK_LED)
/Level Shifters/PAN3V.SCK_1: U1.7 (A6), U18.19 (27_A13_SCK1)
/Level Shifters/PAN5V.CS_00: P1.7, P7.7, U2.20 (B1)
/Level Shifters/PAN5V.CS_01: P1.8, P7.8, U2.18 (B2)
/Level Shifters/PAN5V.CS_02: P1.9, P7.9, U2.17 (B3)
/Level Shifters/PAN5V.CS_03: P1.10, P7.10, U2.16 (B4)
/Level Shifters/PAN5V.CS_04: P1.11, P7.11, U2.15 (B5)
/Level Shifters/PAN5V.CS_05: P2.7, P8.7, U2.14 (B6)
/Level Shifters/PAN5V.CS_06: P2.8, P2.9, P8.8, P8.9, U2.13 (B7)
/Level Shifters/PAN5V.CS_08: P2.10, P8.10, U3.20 (B1)
/Level Shifters/PAN5V.CS_09: P2.11, P8.11, U3.18 (B2)
/Level Shifters/PAN5V.CS_10: P3.7, P9.7, U3.17 (B3)
/Level Shifters/PAN5V.CS_11: P3.8, P9.8, U3.16 (B4)
/Level Shifters/PAN5V.CS_12: P3.9, P9.9, U3.15 (B5)
/Level Shifters/PAN5V.CS_13: P3.10, P9.10, U3.14 (B6)
/Level Shifters/PAN5V.CS_14: P3.11, P9.11, U3.13 (B7)
/Level Shifters/PAN5V.CS_15: P4.7, P10.7, U3.12 (B8)
/Level Shifters/PAN5V.CS_16: P4.8, P10.8, U4.20 (B1)
/Level Shifters/PAN5V.CS_17: P4.9, P10.9, U4.18 (B2)
/Level Shifters/PAN5V.CS_18: P4.10, P10.10, U4.17 (B3)
/Level Shifters/PAN5V.CS_19: P4.11, P10.11, U4.16 (B4)
/Level Shifters/PAN5V.CS_20: P5.7, P11.7, U4.15 (B5)
/Level Shifters/PAN5V.CS_21: P5.8, P11.8, U4.14 (B6)
/Level Shifters/PAN5V.CS_22: P5.9, P11.9, U4.13 (B7)
/Level Shifters/PAN5V.CS_23: P5.10, P11.10, U4.12 (B8)
/Level Shifters/PAN5V.CS_24: P5.11, P11.11, U5.20 (B1)
/Level Shifters/PAN5V.CS_25: P6.7, P12.7, U5.18 (B2)
/Level Shifters/PAN5V.CS_26: P6.8, P12.8, U5.17 (B3)
/Level Shifters/PAN5V.CS_27: P6.9, P12.9, U5.16 (B4)
/Level Shifters/PAN5V.CS_28: P6.10, P12.10, U5.15 (B5)
/Level Shifters/PAN5V.CS_29: P6.11, P12.11, U5.14 (B6)
/Level Shifters/PAN5V.EXT_INT: P1.15, P2.15, P3.15, P4.15, P5.15, P6.15, P7.15, P8.15, P9.15, P10.15, P11.15, P12.15, U5.12 (B8)
/Level Shifters/PAN5V.MISO_0: P1.6, P2.6, P3.6, P4.6, P5.6, P6.6, U1.16 (B4)
/Level Shifters/PAN5V.MISO_1: P7.6, P8.6, P9.6, P10.6, P11.6, P12.6, U1.12 (B8)
/Level Shifters/PAN5V.MOSI_0: P1.5, P2.5, P3.5, P4.5, P5.5, P6.5, U1.17 (B3)
/Level Shifters/PAN5V.MOSI_1: P7.5, P8.5, P9.5, P10.5, P11.5, P12.5, U1.13 (B7)
/Level Shifters/PAN5V.RESET: R1.2, U1.20 (B1)
/Level Shifters/PAN5V.SCK_0: P1.4, P2.4, P3.4, P4.4, P5.4, P6.4, U1.18 (B2)
/Level Shifters/PAN5V.SCK_1: P7.4, P8.4, P9.4, P10.4, P11.4, P12.4, U1.14 (B6)
/Panel Headers/POW.5V_HDR_1: C12.1, P1.1, R3.1, U6.2 (VO)
/Panel Headers/POW.5V_HDR_2: C14.1, P2.1, R4.1, U7.2 (VO)
/Panel Headers/POW.5V_HDR_3: C16.1, P3.1, R5.1, U8.2 (VO)
/Panel Headers/POW.5V_HDR_4: C18.1, P4.1, R6.1, U9.2 (VO)
/Panel Headers/POW.5V_HDR_5: C20.1, P5.1, R7.1, U10.2 (VO)
/Panel Headers/POW.5V_HDR_6: C22.1, P6.1, R8.1, U11.2 (VO)
/Panel Headers/POW.5V_HDR_7: C24.1, P7.1, R9.1, U12.2 (VO)
/Panel Headers/POW.5V_HDR_8: C26.1, P8.1, R10.1, U13.2 (VO)
/Panel Headers/POW.5V_HDR_9: C28.1, P9.1, R11.1, U14.2 (VO)
/Panel Headers/POW.5V_HDR_10: C30.1, P10.1, R12.1, U15.2 (VO)
/Panel Headers/POW.5V_HDR_11: C32.1, P11.1, R13.1, U16.2 (VO)
/Panel Headers/POW.5V_HDR_12: C34.1, P12.1, R14.1, U17.2 (VO)
/Panel Headers/RESET: P1.3, P2.3, P3.3, P4.3, P5.3, P6.3, P7.3, P8.3, P9.3, P10.3, P11.3, P12.3, Q2.3 (D)
/Teensy/A0: J3.3, U18.36 (14_A0_TX3_SPDIF_OUT)
/Teensy/A1: J3.4, U18.37 (15_A1_RX3_SPDIF_IN)
/Teensy/SCL: J2.4, U18.41 (19_A5_SCL)
/Teensy/SDA: J2.3, U18.40 (18_A4_SDA)
GND: C1.2, C2.2, C3.2, C4.2, C5.2, C6.2, C7.2, C8.2, C9.2, C10.2, C11.2, C12.2, C13.2, C14.2, C15.2, C16.2, C17.2, C18.2, C19.2, C20.2, C21.2, C22.2, C23.2, C24.2, C25.2, C26.2, C27.2, C28.2, C29.2, C30.2, C31.2, C32.2, C33.2, C34.2, H1.1, H2.1, H3.1, H4.1, J1.2, J2.1, J3.1, P1.2, P2.2, P3.2, P4.2, P5.2, P6.2, P7.2, P8.2, P9.2, P10.2, P11.2, P12.2, Q2.2 (S), R2.1, R3.2, R4.2, R5.2, R6.2, R7.2, R8.2, R9.2, R10.2, R11.2, R12.2, R13.2, R14.2, SW1.3 (C), U1.11 (GND), U2.11 (GND), U3.11 (GND), U4.11 (GND), U5.11 (GND), U6.1 (GND), U7.1 (GND), U8.1 (GND), U9.1 (GND), U10.1 (GND), U11.1 (GND), U12.1 (GND), U13.1 (GND), U14.1 (GND), U15.1 (GND), U16.1 (GND), U17.1 (GND), U18.1 (GND), U18.34 (GND), U18.47 (GND)
unnamed: Q2.1 (G), R1.1, R2.2
unnamed: J1.1, SW1.1 (A)
VCC: C11.1, C13.1, C15.1, C17.1, C19.1, C21.1, C23.1, C25.1, C27.1, C29.1, C31.1, C33.1, SW1.2 (B), U6.3 (VI), U7.3 (VI), U8.3 (VI), U9.3 (VI), U10.3 (VI), U11.3 (VI), U12.3 (VI), U13.3 (VI), U14.3 (VI), U15.3 (VI), U16.3 (VI), U17.3 (VI)

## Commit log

2020-08-06 initial commit as received from jET
    [BOM_Arena_Bottom.xlsx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]
2020-08-08 12/18 and interconnect PCB, basic docu
    [BOM_Arena_Bottom.xlsx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]
2020-08-11 add old arena 2017 design
    [BOM_Arena_Bottom.xlsx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]
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2020-08-17 reorganize files according to other repos
    [BOM_Arena_Bottom.xlsx, BOM_Arena_Top.xlsx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]
2020-08-20 add OrCAD design files
    [Arena_bottom_V1.brd, Interconnect.brd]
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2020-08-20 Trailing Zero drill file
    [Interconnect-1-4.drl]
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2020-08-28 add arena 12-12 v5 (experimental, not working)
    [12INCH Arena-1-6.drl]
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2021-11-12 correct arena 12-12
    [BOM.xlsx]
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2022-11-17 replace obsolete connector
    [BOM.xlsx]
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2022-11-30 move arena 12-12 v2.2 → v6, new v2.3
    [BOM.xlsx, arena_12-12_v6.brd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]
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2023-06-15 update reference to latest design, fix BOM
    [BOM.xlsx]
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2023-10-26 Worked on 12x12 teensy arena with voltage regulator.
    [BOM.xls, arena.kicad_pcb.kicad_pcb, level_shifters.kicad_sch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]
2023-10-26 Worked on 12-12 teensy arena with voltage regulator.
    [level_shifters.kicad_sch, panel_headers.kicad_sch, teensy.kicad_sch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]
2023-10-26 Worked on 12-12 teensy arean with voltage regulators.
    Moved MOSFET to panel headers sheet. Added RESET to level sifters. Added
    decouple caps for TXB0108's.
    [level_shifters.kicad_sch, panel_headers.kicad_sch, power.kicad_sch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]
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2023-11-13 Worked on 12-12 schematic & part selection.
    Added new 5A regulators. Added load resistors so that regulators
    always have minimum load.
    [panel_headers.kicad_sch, power.kicad_sch, teensy.kicad_sch]
2023-11-16 Finished footprint assignment. Added notes. Modified header footprint.
    [level_shifters.kicad_sch, power.kicad_sch, teensy.kicad_sch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]
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2024-01-05 Added new pcb routing for 12-12 with vreg.
    [teensy.kicad_sch, teensy_arena_12-12.kicad_pcb, teensy_arena_12-12_pwr_gnd_route.kicad_pcb]
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2024-01-10 More work on routing of 12-12 arean with vreg.
    [teensy_arena_12-12.kicad_pcb]
2024-01-11 Worked on routing 12-12 teensy arena/controller with vreg.
    [teensy_arena_12-12.kicad_pcb]
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2024-02-06 Fixed outstanding layout violations 12-12 teensy controller/arena.
    [teensy_arena_12-12.kicad_pcb]
2024-02-10 Completed initial version of fab files.
    Note, there is an issue with the placement of the voltage regulators
    which needs to be resolved. Discrepancy between kicad and JLCPCB.
    [BOM_JLCPCB_teensy_arena_12-12_v0p1_r1.xlsx, nonlscs_bom_teensy_arena_12-12_v0p1_r1.xlsx, power.kicad_sch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]
2024-02-10 Fixed issue with AZ1084CD-5.0TRG1.
    Note, need to do re-route the voltage regulators and redo the CPL file and gerber files.
    [power.kicad_sch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]
2024-02-10 Finished initial version of fab files for 12-12 teensy controller arena.
    [BOM_JLCPCB_teensy_arena_12-12_v0p1_r1.xlsx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]
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2024-07-14 Added development and legacy directories and rearranged a bit.
    [Arena_bottom_V1.brd, BOM.xls, BOM.xlsx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]
2024-07-14 Fixed issue on teensy flat 6 arena + more project reorganization.
    [BOM.xls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]
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2024-07-14 Worked on fixing header orientation on 12-12 teensy arena.
    [BOM.xls, BOM_JLCPCB_teensy_arena_12-12_v0p1_r1.xlsx, holes.kicad_sch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]
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2024-07-17 Finished initial schematic and layout for 12-12 NI arena (without voltage regulators).
    [holes.kicad_sch, level_shifters.kicad_sch, ni_arena_12-12.kicad_pcb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]
2024-08-01 Worked on 12-12 arenas.
    Resized 12-12 arenas, changed NI connector from right angle to
    vertical, push panals back by 1mm.
    [modified_ni_arena_12-12.kicad_pcb, modified_teensy_arena_12-12.kicad_pcb, ni_arena_12-12.kicad_pcb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]
2024-08-01 Added switching regulator design to 12-12 w/ vreg design.
    [power.kicad_sch]
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2024-08-21 Worked on layout for 12-12 NI arena w/ vreg.
    [BOM.xls, BOM_JLCPCB_teensy_arena_12-12_v0p1_r1.xlsx, holes.kicad_sch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]
2024-08-22 Added 3D model of inductor for vreg designs.
    [ni_arena_12-12.kicad_pcb, teensy_arena_12-12.kicad_pcb]
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2024-08-26 Worked on routing for ni and teensy vreg arenas.
    [modified_ni_arena_12-12.kicad_pcb, ni_arena_12-12.kicad_pcb, ni_arena_12-12_copy.kicad_pcb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]
2024-08-28 Worked on routing of ni 12-12 arena with vreg.
    [ni_arena_12-12.dsn, ni_arena_12-12.kicad_pcb, ni_arena_12-12_pwr_and_gnd.kicad_pcb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]
2024-08-28 Fix issues with routed ni 12-12 arena with vreg.
    [ni_arena_12-12.kicad_pcb]
2024-08-28 Added routing of teensy 12-12 arena with big caps.
    [teensy_arena_12-12.dsn, teensy_arena_12-12.kicad_pcb, teensy_arena_12-12_copy.kicad_pcb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]
2024-08-28 Worked on routing of ni 12-12 big cap arena.
    [ni_arena_12-12.dsn, ni_arena_12-12_copy.kicad_pcb, ni_arena_12-12_pwr_and_gnd.kicad_pcb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]
2024-08-29 Added routed design for ni 12-12 arena with big caps.
    [ni_arena_12-12_tmp.kicad_pcb]
2024-09-05 Modified ni 12-12 arena with vreg to be 6-layers.
    Stack up is sig, gnd, vcc, 3v3, gnd, sig.
    [ni_arena_12-12.dsn, ni_arena_12-12_copy.kicad_pcb, ni_arena_12-12_pwr_and_gnd.kicad_pcb]
2024-09-05 Work on BOMs for 12-12 arenas with vregs. Finish non-LSCS versions.
    [BOM_JLCPCB_ni_arena_12-12_v0p1_r1.xlsx, BOM_JLCPCB_teensy_arena_12-12_v0p1_r1.xlsx, ni_arena_12-12.csv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]
2024-09-05 Fixed naming issues for 12-12 arena production files.
    [BOM_JLCPCB_teensy_arena_12-12_v0p2_r1.xlsx, nonlscs_bom_teensy_arena_12-12_v0p2_r1.xlsx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]
2024-09-10 Worked on 6-layer routes.
    Worked on adding gnd stiching vias for 12-12 NI arena with vreg. Work on
    6-layer route for 12-12 teensy arena with vreg.
    [teensy_arena_12-12.dsn, teensy_arena_12-12.kicad_pcb, teensy_arena_12-12_backup.kicad_pcb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]
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2024-09-26 Flushed out JLCPCB BOM for 12-12 wveg designs.
    [BOM_JLCPCB_ni_arena_12-12_v0p1_r1.xlsx, BOM_JLCPCB_teensy_arena_12-12_v0p2_r1.xlsx]
2024-09-26 Worked on new CPL files for 12-12 arenas with vreg.
    [BOM_JLCPCB_ni_arena_12-12_v0p1_r1.xlsx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]
2024-09-27 Worked on CPL files for 12-12 vreg arenas.
    [BOM_JLCPCB_ni_arena_12-12_v0p1_r1.xlsx, BOM_JLCPCB_teensy_arena_12-12_v0p1_r1.xlsx, BOM_JLCPCB_teensy_arena_12-12_v0p2_r1.xlsx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]
2024-09-27 Created gerber files for new 12-12 arenas with vreg.
    [ni_arena_12-12-B_Cu.gbl, ni_arena_12-12-B_Mask.gbs, ni_arena_12-12-B_Paste.gbp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]
2024-09-29 Fixed component rotations in NI 12-12 arena w/ vreg for JLCPCB upload.
    [CPL_JLCPCB_ni_arena_12-12_v0p1_r1.xlsx, CPL_JLCPCB_ni_arena_12-12_v0p1_r1_orig.xlsx]
2024-09-29 Fixed component rotations in CPL file for teensy 4.1 12-12 arena with vreg.
    [CPL_JLCPCB_teensy_arena_12-12_v0p2_r1.xlsx, CPL_JLCPCB_teensy_arena_12-12_v0p2_r1_orig.xlsx]
2024-10-01 Intermediate save during re-route of NI 12-12 arena with vreg.
    [arena_6-inf_v0p3.kicad_pcb, arena_6-inf_v0p3.kicad_sch, ni_arena_12-12.dsn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]
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2024-10-03 Remade gerber files for NI 12-12 vreg arena design.
    [CPL_JLCPCB_ni_arena_12-12_v0p1_r1.xlsx, ni_arena_12-12-B_Cu.gbl, ni_arena_12-12-B_Mask.gbs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]
2024-10-03 Fix issue on legacy design.
    [arena_6-inf_v0p3.kicad_sch]
2024-10-03 Remade gerbers for NI 12-12 arena w/ vreg again fix issue with trace.
    [ni_arena_12-12-B_Cu.gbl, ni_arena_12-12-B_Mask.gbs, ni_arena_12-12-B_Paste.gbp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]
2024-10-03 Remade gerbers for teensy 4.1 12-12 arena with vreg.
    [teensy_arena_12-12-B_Cu.gbl, teensy_arena_12-12-B_Mask.gbs, teensy_arena_12-12-B_Paste.gbp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]
2024-10-06 Fixed issue on silkscreen for ni and teensy 12-12 arenas with vreg.
    [ni_arena_12-12-B_Cu.gbl, ni_arena_12-12-B_Mask.gbs, ni_arena_12-12-B_Paste.gbp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]
